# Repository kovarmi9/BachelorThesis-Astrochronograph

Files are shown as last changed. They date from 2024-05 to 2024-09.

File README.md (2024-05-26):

# BachelorThesis-Astrochronograph

This repository contains files created for a Bachelor’s Thesis on the topic of ‘Development of a device for receiving and recording coordinated time for astronomical measurement purposes’. It includes the source code of the application and the LaTeX code of the thesis.

**Srtucture of repository:**
<pre>
├── README.md                                    # Documentation
│   ├── src                                      # Source code folder
│   │   ├── Arduino                              # Arduino codes
│   │   │   ├── Components                       # Codes for individual components
│   │   │   │   ├── BLE
│   │   │   │   ├── Bluetooth
│   │   │   │   ├── DCF77_time
│   │   │   │   ├── Display
│   │   │   │   ├── GNSS_time
│   │   │   │   ├── NTP
│   │   │   │   ├── RGB_LED
│   │   │   │   ├── Rotarry_encoder
│   │   │   │   ├── RTC
│   │   │   │   ├── SD
│   │   │   │   ├── Sound
│   │   │   │   └── TS_Reader
│   │   │   ├── Complet
│   │   │   │   ├── Astro-Chronograph_R3
│   │   │   │   └── Astro-Chronograph_R4
│   │   │   └── Test                             # Arduino codes for testing time synchronization
│   │   ├── LaTeX                                # LaTeX source code of the bachelor thesis
│   │   └── R                                    # Processing of testing data
├── Eagle                                        # Circuit schematics and PCB design
└── Text - Text                                  # Text of the Thesis
    ├── Thesis.pdf -                             # Thesis document in PDF format
    └── Presentation.pdf                         # Presentation document in PDF format
</pre>
**Circuit schematics:**
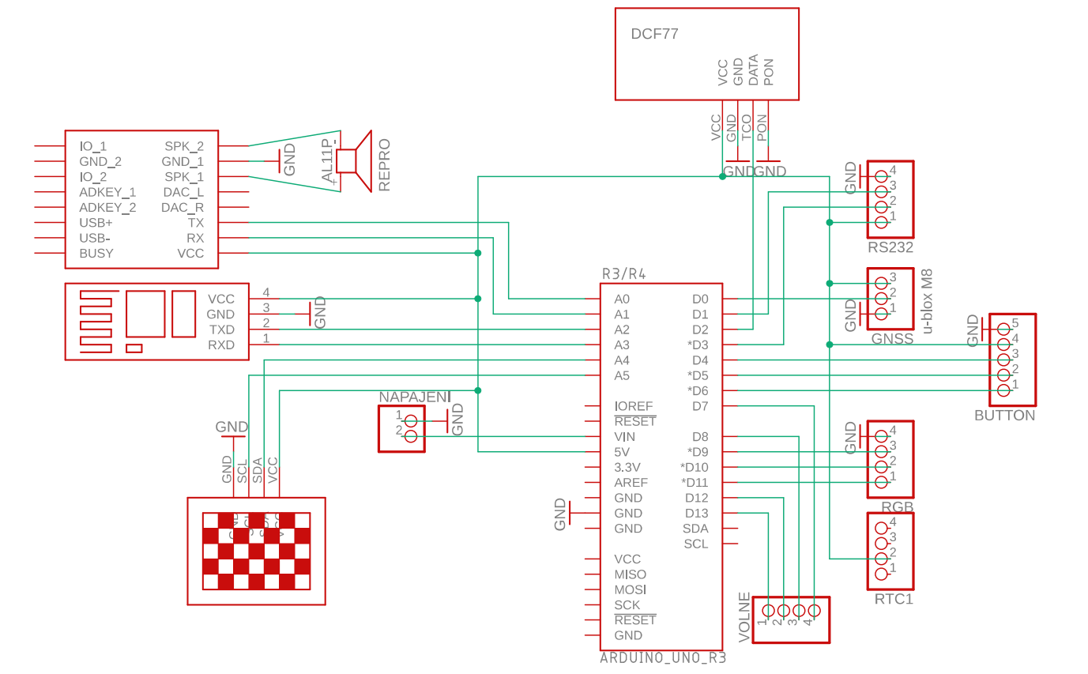
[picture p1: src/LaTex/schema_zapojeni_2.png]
Popis obrázku


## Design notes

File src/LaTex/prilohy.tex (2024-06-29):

% %%%%%%%%%%%%%%%%%%%%%%%%%%%%%%%%%%%%%%%%%%%%%%%%%%%%%%%%%%%%%%%%%%%%%%%%%%%%%%%%%%%
% %%                                    PŘÍLOHY                                    %%
% %%%%%%%%%%%%%%%%%%%%%%%%%%%%%%%%%%%%%%%%%%%%%%%%%%%%%%%%%%%%%%%%%%%%%%%%%%%%%%%%%%%

\appendix
% Příloha A: GitHub repozitář
\chapter*{A GitHub repozitář}
\addcontentsline{loa}{section}{A GitHub repozitář}
\href{https://github.com/kovarmi9/BachelorThesis-Astrochronograph}{\texttt{https://github.com/kovarmi9/BachelorThesis-Astrochronograph}}.
\begin{center}
\qrcode[height=4cm]{https://github.com/kovarmi9/BachelorThesis-Astrochronograph}
\end{center}
\textbf{Struktura repozitáře:}
\dirtree{%
.1 \href{https://github.com/kovarmi9/BachelorThesis-Astrochronograph}{BachelorThesis-Astrochronograph}.
.2 \href{https://github.com/kovarmi9/BachelorThesis-Astrochronograph/blob/main/README.md}{README.md}.\dottedline  stručná dokumentace.
.2 \href{https://github.com/kovarmi9/BachelorThesis-Astrochronograph/blob/main/src}{src}.
.3 \href{https://github.com/kovarmi9/BachelorThesis-Astrochronograph/tree/main/src/Arduino}{Arduino}.\dottedline kódy pro Arduino.
.4 \href{https://github.com/kovarmi9/BachelorThesis-Astrochronograph/tree/main/src/Arduino/Components}{Components}.\dottedline kódy pro jednotlivé komponenty.
.5 \href{https://github.com/kovarmi9/BachelorThesis-Astrochronograph/tree/main/src/Arduino/Components/BLE}{BLE}.
.5 \href{https://github.com/kovarmi9/BachelorThesis-Astrochronograph/tree/main/src/Arduino/Components/Bluetooth}{Bluetooth}.
.5 \href{https://github.com/kovarmi9/BachelorThesis-Astrochronograph/tree/main/src/Arduino/Components/DCF77_time}{DCF77\_time}.
.5 \href{https://github.com/kovarmi9/BachelorThesis-Astrochronograph/tree/main/src/Arduino/Components/Display}{Display}.
.5 \href{https://github.com/kovarmi9/BachelorThesis-Astrochronograph/tree/main/src/Arduino/Components/GNSS_time}{GNSS\_time}.
.5 \href{https://github.com/kovarmi9/BachelorThesis-Astrochronograph/tree/main/src/Arduino/Components/NTP}{NTP}.
.5 \href{https://github.com/kovarmi9/BachelorThesis-Astrochronograph/tree/main/src/Arduino/Components/RGB_LED}{RGB\_LED}.
.5 \href{https://github.com/kovarmi9/BachelorThesis-Astrochronograph/tree/main/src/Arduino/Components/Rotarry_encoder}{Rotarry\_encoder}.
.5 \href{https://github.com/kovarmi9/BachelorThesis-Astrochronograph/tree/main/src/Arduino/Components/RTC}{RTC}.
.5 \href{https://github.com/kovarmi9/BachelorThesis-Astrochronograph/tree/main/src/Arduino/Components/SD}{SD}.
.5 \href{https://github.com/kovarmi9/BachelorThesis-Astrochronograph/tree/main/src/Arduino/Components/Sound}{Sound}.
.5 \href{https://github.com/kovarmi9/BachelorThesis-Astrochronograph/tree/main/src/Arduino/Components/TS_Reader}{TS\_Reader}.
.4 \href{https://github.com/kovarmi9/BachelorThesis-Astrochronograph/tree/main/src/Arduino/Complet}{Complet}.\dottedline kompletní kód.
.5 \href{https://github.com/kovarmi9/BachelorThesis-Astrochronograph/tree/main/src/Arduino/Complet/Astro-Chronograph_R3}{Astrochronograph\_R3}.
.5 \href{https://github.com/kovarmi9/BachelorThesis-Astrochronograph/tree/main/src/Arduino/Complet/Astro-Chronograph_R4}{Astrochronograph\_R4}.
.4 \href{https://github.com/kovarmi9/BachelorThesis-Astrochronograph/tree/main/src/Arduino/Test}{Test}.\dottedline kód pro testování.
.3 \href{https://github.com/kovarmi9/BachelorThesis-Astrochronograph/tree/main/src/LaTeX}{LaTeX}.\dottedline zdrojový kód práce ve formátu \LaTeX.
.3 \href{https://github.com/kovarmi9/BachelorThesis-Astrochronograph/tree/main/src/R}{R}.\dottedline zpracování testovacích dat.
.2 \href{https://github.com/kovarmi9/BachelorThesis-Astrochronograph/tree/main/Eagle}{Eagle}.\dottedline schéma zapojení a návrh DPS.
.2 \href{https://github.com/kovarmi9/BachelorThesis-Astrochronograph/tree/main/Text}{Text}.
.3 \href{https://github.com/kovarmi9/BachelorThesis-Astrochronograph/blob/main/Text/Thesis.pdf}{Thesis.pdf}.\dottedline text práce ve formátu PDF.
.3 \href{https://github.com/kovarmi9/BachelorThesis-Astrochronograph/blob/main/Text/Presentation.pdf}{Presentation.pdf}.\dottedline Prezentace ve formátu PDF.
}

% Příloha B: Elektronická příloha - SD karta
\newpage
\chapter*{B Elektronická příloha - SD karta}
\addcontentsline{loa}{section}{B Elektronická příloha - SD karta}
\textbf{Struktura souborů na SD kartě:}
\dirtree{%
.1 SD.
.2 Arduino.\dottedline kódy pro Arduino.
.3 Components.\dottedline kódy pro jednotlivé komponenty.
.4 BLE.
.4 Bluetooth.
.4 DCF77\_time.
.4 Display.
.4 GNSS\_time.
.4 NTP.
.4 RGB\_LED.
.4 Rotarry\_encoder.
.4 RTC.
.4 SD.
.4 Sound.
.4 TS\_Reader.
.3 Complet.\dottedline kompletní kód.
.4 Astrochronograph\_R3.
.4 Astrochronograph\_R4.
.3 Test.
.2 R.\dottedline zpracování testovacích dat.
.2 Eagle.\dottedline schéma zapojení a návrh DPS.
}

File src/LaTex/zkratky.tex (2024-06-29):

\begin{seznamzkratek}{GNSS}
\novazkratka{API}{API}{Application Programming Interface}
\novazkratka{DPS}{DPS}{deska plošných spojů}
\novazkratka{GNSS}{GNSS}{globální navigační satelitní systémy}
\novazkratka{IDE}{IDE}{integrované vývojové prostředí} \(\) - z angl. Integrated Development Environment
\novazkratka{LED}{LED}{elektroluminiscenční dioda} \(\) - z angl. Light Emitting Diode
\novazkratka{NTP}{NTP}{Network Time Protokol}

\novazkratka{PWM}{PWM}{pulzně šířková modulace} \(\) - z angl. Pulse Width Modulation

\novazkratka{TAI}{TAI}{mezinárodní atomový čas} \(\) - z fr. Temps Atomique International
\novazkratka{UTC}{UTC}{univerzální koordinovaný čas}\(\) - z angl. Coordinated Universal Time / fr. Temps Universel Coordonné

%SI sistem international

%\novazkratka{VLBI}{VLBI}{interferometrie z velmi dlouhých základen} \(\) - z angl. Very-long-baseline interferometry
%\novazkratka{SEČ}{SEČ}{středoevropský čas}
%\novazkratka{SELČ}{SELČ}{středoevropský letní čas}
%\novazkratka{UART}{UART}{Universal asynchronous receiver-transmitter}

\end{seznamzkratek}

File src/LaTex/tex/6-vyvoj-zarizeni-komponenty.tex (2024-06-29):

\chapter{Vývoj zařízení - Komponenty}
\label{4-vyvoj-zarizeni-komponenty}
\section{Vývojová deska}
Vývojová deska je elektronické zařízení skládající se z~desky plošných spojů, mikro\-kontroléru a k~němu připojených dalších periférií. Mikrokontrolér je malý \text{počítač} na jednom integrovaném obvodu, který může obsahovat jedno nebo více jader \text{procesoru}, paměť pro uložení programu, operační paměť a programovatelné \text{vstupy/výstupy}. Mikrokontrolér neobsahuje operační systém a řídící program na něj bývá nahraný \text{pomocí} integrovaného vývojového prostředí (\zk{IDE}, z~anglického Integrated Develop\-ment Environment). Mikrokontrolér ovládá k~němu připojené periférie a další součástky připojnené k~vývojové desce. Připojením součástek k~vývojové desce lze vytvořit nové elektronické zařízení \cite{dps_vyvojove_desky}.

\subsection{Arduino Uno}
Jako vývojová deska bylo zvoleno Arduino UNO, a to z~důvodu jeho poměrně nízké ceny, velkého množství dostupné dokumentace a kompatibilních součástek. Tato vývojová deska, na které je nahraný řídící program, ovládá všechny ostatní použité komponenty. Nejběžněji se lze setkat s~Arduinem UNO R3, které je \text{založené} na mikrokontroléru ATmega328P od firmy Atmel. Z~důvodu malé kapacity paměti \text{Arduina} UNO R3 bylo využito novější Arduino UNO R4. To je založeno na mikrokontroléru Renesas RA4M1, jenž obsahuje procesor ARM Cortex-M4F. Arduino UNO R4 se vyrábí ve verzích Minima a WiFi. Verze WiFi je zaměřena na IoT aplikace a obsahuje navíc mikrokontrolér ESP32-S3 od firmy Espressif s~integrovaným WiFi a bluetooth low energy (BLE) modulem. Toho lze využít pro připojení k~NTP serveru, nebo odesílání dat \cite{arduino}. Arduino UNO lze pořídit i v~podobě „klonu“, který vyrábí neoficiální výrobce. Tyto „kolny“ bývají obvykle cenově dostupnější než \text{originální desky}.

% https://www.robotikabrno.cz/docs/arduino/Pr%C5%AFvodce-sv%C4%9Btem-Arduina-CZ.pdf

\begin{table}[H]
    \centering
    \caption{Porovnání kapacity paměti Arduina UNO R3 a R4 \cite{arduino}}
    \begin{tabular}{|c|c|c|}
    \hline
    \textbf{Typ paměti} & \textbf{R3} & \textbf{R4}\\
    \hline\hline
    flash  & 32 KB & 256 kB \\ \hline
    SRAM   & 2  KB &  32 kB \\ \hline
    EEPROM & 1  KB &   8 kB \\ \hline
    \end{tabular}\\
\end{table}

\begin{figure}[H]
	\centering
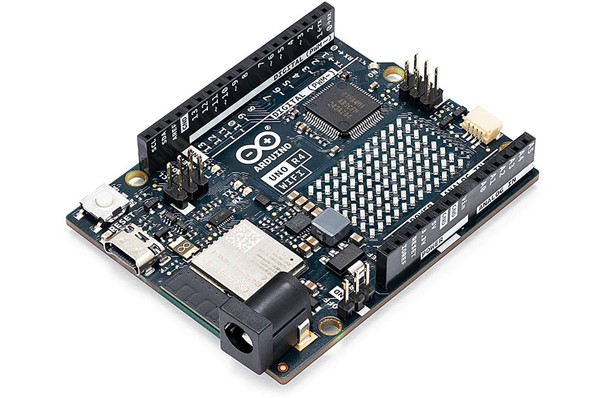
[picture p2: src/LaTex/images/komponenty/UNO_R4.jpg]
	
	\caption{Arduino UNO R4 ve verzi WiFi \cite{laskakit_web}}
\end{figure}

\subsection{Arduino Mega}
Vzhledem k~nedostatečné kapacitě paměti Arduina UNO R3 se rovněž nabízí možnost využití Arduina Mega. To je založené na mikrokontroléru ATmega2560. Oproti \text{Arduinu} UNO R3 disponuje větší kapacitou paměti, a oproti oběma verzím Arduina UNO i větším množstvím pinů. Nevýhodou Arduina Mega je větší fyzická velikost a bylo tedy využito jen pro testování během vývoje zařízení \cite{arduino}.

\begin{figure}[H]
	\centering
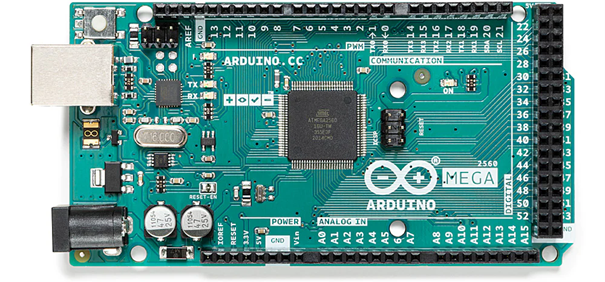
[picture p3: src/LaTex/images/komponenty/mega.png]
	
	\caption{Arduino Mega \cite{arduino}}
\end{figure}

\section{Přijímač časového signálu}
Existuje několik způsobů, jak synchronizovat čas Arduina s~koordinovaným časem. Jedním z~nich je synchronizace času při nahrávání programu do Arduina. Tato metoda však vyžaduje opakované nahrání programu před každým měřením, aby se interní čas aktualizoval. Tato metoda neumožňuje průběžnou synchronizaci a její přesnost je závislá na přesnosti vnitřního času zařízení z~nějž je program nahráván. Vhodnějšími metodami jsou synchronizace přes internet, využití přijímače DCF77, který přijímá koordinovaný čas pomocí rádiového signálu, nebo využití času z~NMEA zprávy z~GNSS přijímače. Tyto metody poskytují přesnější a průběžnou synchronizaci času bez nutnosti opakovaného nahrávání programu.

\subsection{Přijímač DCF77}
Pro příjem signálu DCF77 je vhodné zvolit anténu, která přijímá především magnetickou složku elektromagnetické vlny, protože elektrická složka vlny je citlivá na výšku antény nad povrchem a bývá výrazně více rušena okolním signálem z~jiných \text{elektronických} zařízení než magnetická složka. Pro příjem magnetické složky signálu lze využít rámovou anténu, která ale mívá poměrně velké rozměry. Obvykle se používá anténa o~průměru 0,5m. Z~důvodu kompaktnosti celého zařízení byla \text{zvolena} feritová anténa. Pokud by signál z~feritové antény nebyl dostatečně silný, je možné pro jeho zesílení přímo na feritovou anténu připojit rámovou anténu s~větším průměrem.

Využitý přijímač se skládá z~feritového jádra, kolem kterého je vinuta cívka a demodulátoru, který slouží k~oddělení modulačního signálu od nosného signálu. Anténa má dvě maxima a dvě minima. Pro příjem maximální intenzity signálu, je vhodné ji umístit kolmo na směr k~vysílači. Pokud by docházelo k~rušení signálu z~jednoho směru, lze to vyřešit tím, že bude anténa natočena minimem ke zdroji rušení \cite{fel_dcf77} \cite{vyvoj_hw_andel}.

\begin{figure}[H]
	\centering
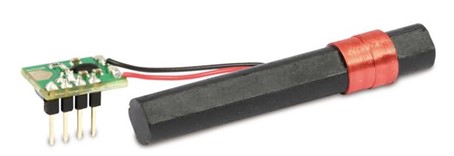
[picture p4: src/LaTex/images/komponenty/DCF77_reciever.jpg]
	
	\caption{Přijímač radiového signálu DCF77 \cite{dratek_web}}
\end{figure}

\subsection{Přijímač GNSS}
Pro příjem informací o~aktuálním čase lze využít i GNSS přijímač. \text{Astrochrograf} je navržený tak, že má vyvedený pin D0 Arduina, aby k~němu mohl být \text{připojen} \text{libovolný} GNSS přijímač. Pin D0 na Arduinu Uno funguje jako RX pin pro \text{sériovou} komunikaci pomocí UART. GNSS přijímač musí být k~RX pinu Arduina \text{připojen} pomocí svého TX pinu. Přijímač musí poskytovat NMEA zprávu \$GNZDA, která obsahuje informace o~aktuálním čase a zprávu \$GNGGA, která poskytuje informaci o~poloze přijímače. Pro vývoj zařízení byl použit aktuálně dostupný GNSS \text{přijímač} Ublox NEO-M8T, který je schopen přijímat data ze satelitů GPS, GLONASS, Galileo, BeiDou, QZSS a SBAS. Tento přijímač umožňuje i RTK měření. Nevýhodou přijímače je poměrně vysoká cena. Pro určování času lze využít i přijímače s~omeze\-nější funkcionalitou než Ublox NEO-M8T. Například levnější přijímač Ublox NEO-M7M, který přijímá data ze satelitů GPS, GLONASS, Galileo a QZSS. Tento přijímač neumožňuje měření RTK, což není pro určování času potřeba.
\begin{figure}[H]
\centering
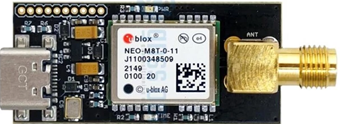
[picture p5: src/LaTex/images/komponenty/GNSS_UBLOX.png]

\caption{GNSS přijímač Ublox NEO-M8T \cite{gnss_store}}
\end{figure}

\begin{figure}[H]
	\centering
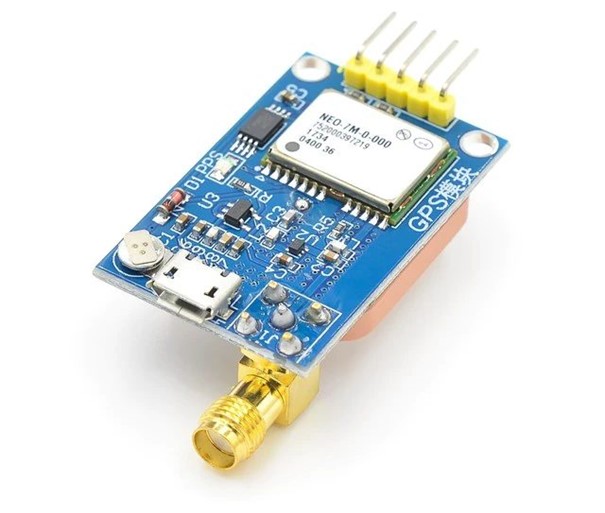
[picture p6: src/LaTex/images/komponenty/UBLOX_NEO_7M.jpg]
	
	\caption{GNSS přijímač Ublox NEO 7M \cite{dratek_web}}
\end{figure}

\section{Čtečka Micro SD karet}
Protože Arduino samo o sobě nemá paměť pro ukládání dat, tak byla pro ukládání měřených dat využita Micro SD karta. Čtečka Micro SD karet umožňuje zapisovat měřená data na Micro SD kartu a popřípadě je z~ní i číst. Pro komunikaci s~čtečkou Micro SD karet je využíváno standardní SPI rozhraní \cite{arduino_navody}.

\begin{figure}[H]
	\centering
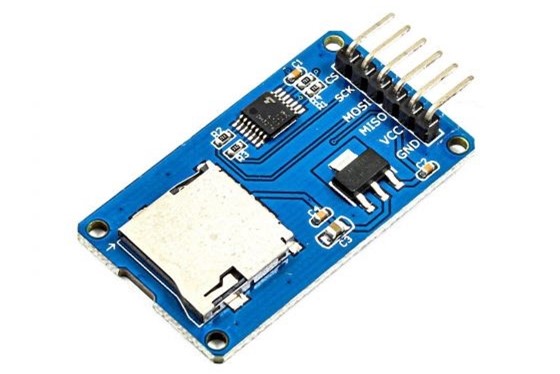
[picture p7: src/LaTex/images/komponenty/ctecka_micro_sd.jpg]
	
	\caption{Čtečka Micro SD karet \cite{dratek_web}}
\end{figure}

\section{Tlačítko}
Tlačítko je jednoduchý komponent, sloužící pro detekci svého stisknutí. Stisknutí tlačítka slouží k~provedení záznamu času na Micro SD kartu. Místo samostatného tlačítka byl využit modul rotačního enkodéru, který umí detekovat své stisknutí a při pootočení osou poskytuje informaci o~směru rotace. Výhodou rotačního enkodéru oproti tlačítku je, že poskytuje další informace, které lze využít k~ovládání zařízení. Výhodou tohoto konkrétního modulu je to, že jej lze snadno upevnit ke krabičce s~výsledným zařízením.
\begin{figure}[H]
	\centering
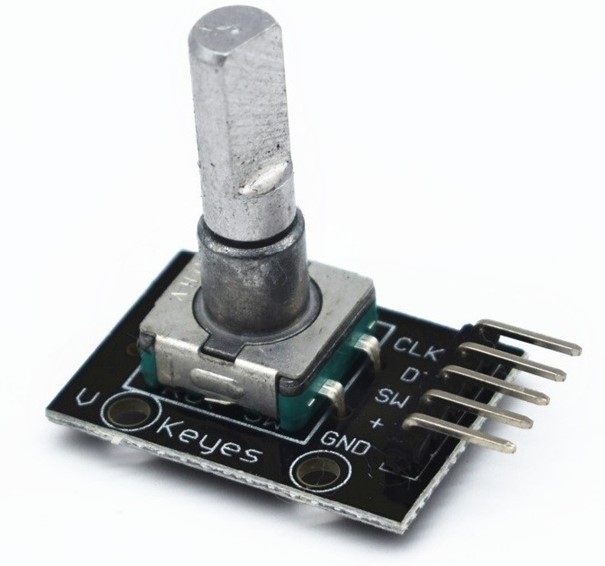
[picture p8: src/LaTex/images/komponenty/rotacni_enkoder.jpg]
	
	\caption{Rotační enkodér \cite{dratek_web}}
\end{figure}

\section{OLED displej}
K~informování měřiče o~průběhu měření slouží mimo jiné displej. Na něj se zobrazuje informace o~stavu vložení Micro SD karty, o~stavu synchronizace času, aktuální čas a poslední uložený čas. Jako displej byl zvolen OLED displej především kvůli nízké ceně, dobré čitelnosti, nízké spotřebě energie a absenci potřeby dodatečného podsvícení, jelikož světélkují samotné pixely. Displej je monochromatický a jeho rozlišení je 128×64 bodů. K~řízení displeje je využívána komunikace pomocí I\(^2\)C sběrnice \cite{arduino_navody}.

\begin{figure}[H]
	\centering
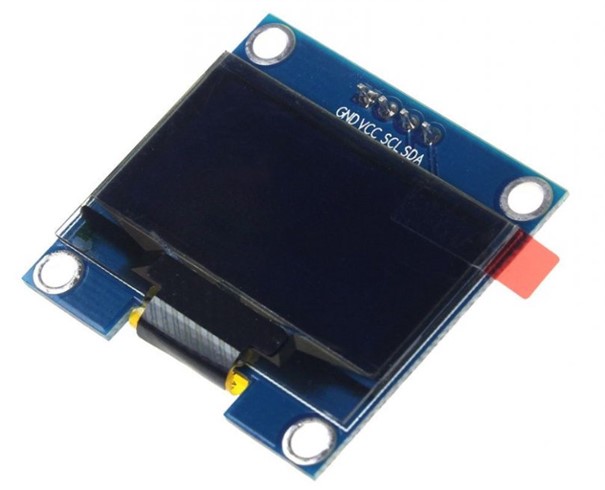
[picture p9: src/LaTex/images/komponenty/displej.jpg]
	
	\caption{OLED displej \cite{dratek_web}}
\end{figure}

\section{Hlasový modul}
O~průběhu měření je měřič informován kromě displeje i pomocí reproduktoru, tak aby nemusel při měření sledovat displej. Měřiče o~průběhu měření informují slovní pokyny „Čas byl synchronizován“ a „Měření času bylo uloženo“, které byly vytvořeny pomocí převodu textu na mp3 soubor. Jelikož Arduino neumožňuje ukládat žádné soubory do své vnitřní paměti, tak jsou mp3 soubory se zvukovými informacemi nahrány na Micro SD kartu. Soubory jsou z~Micro SD karty čteny pomocí hlasového modulu a přehrávány pomocí reproduktoru, který je k~hlasovému modulu připojen. Hlasový modul s~Arduinem komunikuje prostřednictvím sériové komunikace \cite{arduino_navody}.

\begin{figure}[H]
	\centering
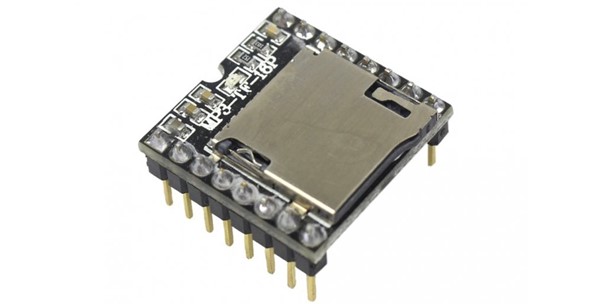
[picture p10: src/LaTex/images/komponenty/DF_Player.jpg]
	
	\caption{Hlasový modul \cite{laskakit_web}}
\end{figure}

\begin{figure}[H]
	\centering
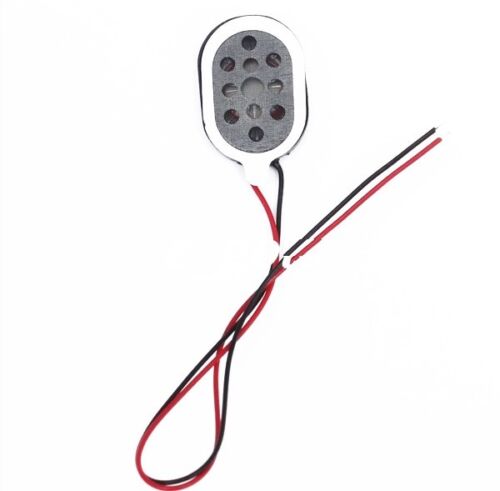
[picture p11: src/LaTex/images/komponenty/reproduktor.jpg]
	
	\caption{Reproduktor \cite{arduino}}
\end{figure}

\section{RGB LED}
Kromě displeje a zvukového signálu je měřič informován o~průběhu měření také prostřednictvím elektroluminiscenční diody (\zk{LED}, z~anglického Light Emitting Diode). Jako \zkratka{LED} je využit modul RGB \zk{LED}, který se skládá ze tří samostatných \zk{LED} (červená, zelená, modrá). Tyto \zk{LED} mají společnou \text{katodu}, ale samostatné anody. K ovládání jasu jednotlivých barev slouží \zkratka{PWM}. Jednotlivé anody lze nezávisle na sobě připojit na piny s podporou \zk{PWM}, což umožňuje ovládat samostatně jednotlivé barvy. Další výhodou tohoto modulu je, že již má integrované ochranné rezistory. Během měření může \zk{LED} signalizovat různé stavy: Nejprve bliká červeně v~každý okamžik, kdy přijme signál DCF77 (v~ideálním případě je to jednou za sekundu). Ve chvíli, kdy je čas poprvé synchronizován se změní červené blikání na zelené, což informuje měřiče o~úspěšné synchronizaci času. Dále \zk{LED} bliká modře v~každý okamžik, kdy měřič provede měření \cite{arduino_navody}.
\begin{figure}[H]
	\centering
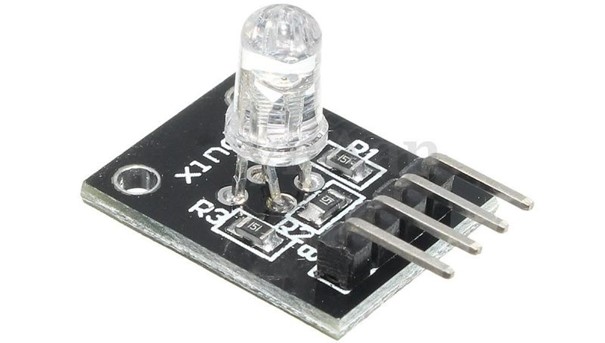
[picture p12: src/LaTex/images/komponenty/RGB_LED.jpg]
	
	\caption{Modul s~RGB LED \cite{dratek_web}}
\end{figure}

\section{Převodník TTL na RS232}
Aby byl spolu s~časovými údaji uložen na Micro SD kartu vodorovný směr (a případně i zenitový úhel) měřený totální stanicí, je potřeba zajistit komunikaci Arduina s~totální stanicí. K~tomu lze využít sériovou komunikaci pomocí UART. Konkrétně byla využita totální stanice Leica TC1700. Ta využívá pro sériovou komunikaci standart RS-232 a lze k~ní tedy připojit sériový kabel RS-232 \cite{tps-dna}. Standart RS-232 využívá pro datové signály +3~V až +25~V jako logickou nulu a -3~V až -25~V jako logickou jedničku. Arduino UNO využívá protokol TTL, který považuje hodnoty okolo 0~V za logickou nulu a hodnoty v~okolí +5~V za logickou jedničku. Aby mohl být kabel RS-232 připojen i k~Arduinu, je potřeba využít převodník TTL na RS-232 \cite{sparkfun-tutorial}.

\begin{figure}[H]
	\centering
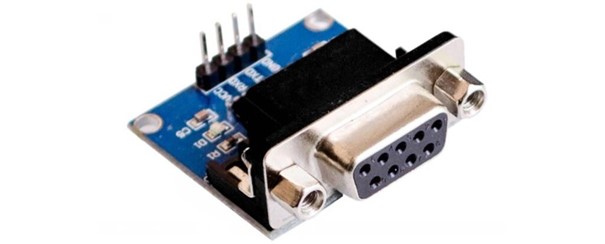
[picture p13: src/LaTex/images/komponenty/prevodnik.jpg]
	
	\caption{Převodník TTL na RS232 \cite{laskakit_web}}
\end{figure}

\section{Bluetooth modul}
Pro export dat z~Micro SD karty, aniž by bylo potřeba ji vyjmout, lze využít \text{Bluetooth} modul. Konkrétně byl pro tento účel využit modul HC-05. Tento modul využívá sériovou komunikaci pomocí UART a podporuje Bluetooth ve verzi 2.0. Pomocí Bluetooth modulu lze přenášet binární data. Modul je připojen pomocí pinů GND, VCC, RX a TX. Kromě toho obsahuje piny STATE a EN, které slouží pro konfiguraci modulu. Pin EN na modulu HC-05 umožňuje přepnutí modulu do režimu „enabled“. V~tomto režimu lze pomocí AT příkazů nastavit jméno, heslo, popřípadě i baud rate a další parametry modulu \cite{arduino_navody}.

\begin{figure}[H]
	\centering
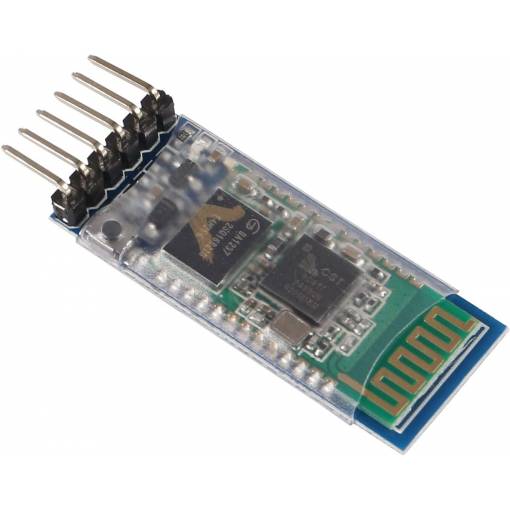
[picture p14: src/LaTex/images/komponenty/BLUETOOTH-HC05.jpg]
	
	\caption{Bluetooth modul HC-05 \cite{dratek_web}}
\end{figure}

\section{Deska plošných spojů}
Během vývoje zařízení byly všechny komponenty spojovány pomocí kabelů. Nevýho\-dou propojení pomocí kabelů je velká prostorová náročnost a celková nepřehlednost. Z~toho důvodu bývá obvykle propojení různých komponentů realizováno pomocí desky plošných spojů. Pro snadné propojení všech využitých komponentů byla tedy vyhotovena \zkratka{DPS}.

\begin{figure}[H]
	\centering
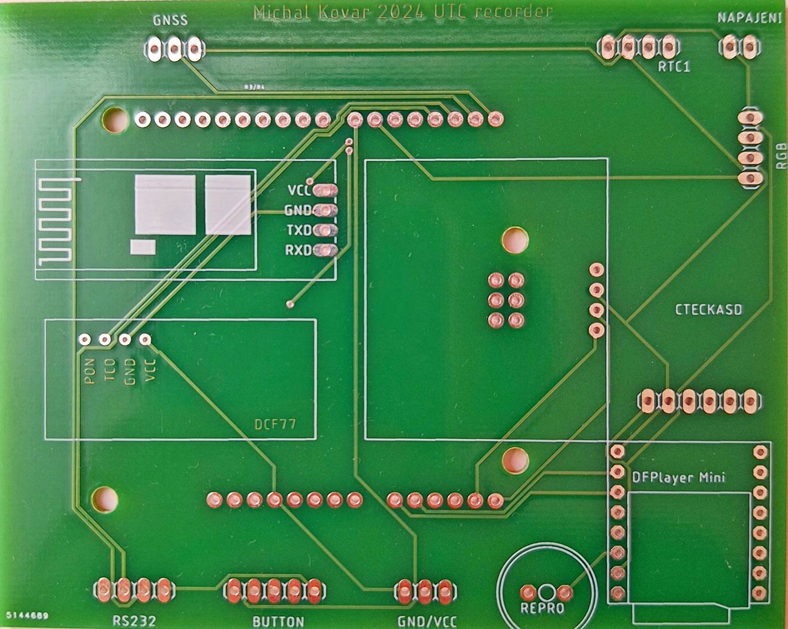
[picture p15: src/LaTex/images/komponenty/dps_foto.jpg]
	
	\caption{Výsledná DPS}
\end{figure}

\section{Cena komponentů}
Ceny jednotlivých komponentů se mění v čase a mohou se lišit v závislosti na místě (obchodě), kde byly zakoupeny. Cena výsledného zařízení závisí na tom, zda byly použity všechny komponenty pro plnou funkcionalitu, nebo zda byly některé funkce vynechány.  Pokud se zařízení vyrábí s omezenou funkcionalitou, lze využít levnější Arduino UNO R3. Náklady na výsledné zařízení lze také snížit použitím „klonů“ místo originálního Arduina. Níže uvedená tabulka obsahuje komponenty potřebné pro zařízení s plnou funkcionalitou a uvádí ceny, za které byly tyto komponenty zakoupeny.

\begin{table}[H]
    \centering
    \caption{Cena použitých součástek}
    \begin{tabular}{|c|c|c|}
    \hline
    \textbf{Název} & \textbf{Cena} & \textbf{Odkaz na obchod}\\
    \hline\hline
    Arduino UNO R4 WiFi         & 768 Kč            & \href{https://www.laskakit.cz/arduino-uno-r4-wifi--original/}{laskakit.cz}  \\ \hline
    Přijímač DCF77              & 5,60 \euro/140 Kč  & \href{https://www.pollin.de/p/dcf-empfangsmodul-dcf1-810054}{pollin.de} \\ \hline
    Přijímač GNSS               & 339 Kč            & \href{https://dratek.cz/arduino/1733-gps-satelitni-urceni-polohy-neo-7m-modul.html?}{dratek.cz} \\ \hline
    Čtečka Micro SD karet       & 24 Kč             & \href{https://dratek.cz/arduino/993-ctecka-microsd-karet.html?}{dratek.cz} \\ \hline
    Tlačítko (rotační enkodér)   & 38 Kč             & \href{https://dratek.cz/arduino/837-rotacni-enkoder.html?}{dratek.cz} \\ \hline
    OLED displej                & 167 Kč            & \href{https://dratek.cz/arduino/3181-iic-i2c-oled-1-3-displej-128x64-bily.html?}{dratek.cz} \\ \hline
    Hlasový modul               & 66 Kč             & \href{https://dratek.cz/arduino/4857-hlasovy-modul-s-integrovanym-mp3-prehravacem-dfplayer.html?}{dratek.cz} \\ \hline
    Reproduktor                 & 19 Kč             & \href{https://dratek.cz/arduino/1175-reproduktor-1w-8ohm.html?}{dratek.cz} \\ \hline
    RGB LED                     & 15 Kč             & \href{https://dratek.cz/arduino/837-rotacni-enkoder.html}{dratek.cz} \\ \hline
    Bluetooth modul HC-05       & 117 Kč            & \href{https://dratek.cz/arduino/1005-bluetooth-modul-hc-05.html?}{dratek.cz} \\ \hline
    Deska plošných spojů        & 9,34 \$/216 Kč    & \href{https://www.allpcb.com/}{allpcb.com} \\ \hline
     \textbf{Celkem}            & 1909 Kč           & - \\ \hline
    \end{tabular}\\
\end{table}

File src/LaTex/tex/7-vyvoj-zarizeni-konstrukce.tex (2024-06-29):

\chapter{Vývoj zařízení - Konstrukce}
\label{5-vyvoj-zarizeni-konstrukce}
V~této kapitole bude vysvětleno zapojení jednotlivých komponentů, které byly pop\-sány v~předchozí kapitole. Dále bude popsán návrh desky plošných spojů (\zk{DPS}), jenž byl vyhotoven v~softwaru Autodesk EAGLE. Bude vysvětleno, jak byla \zk{DPS} osazena jednotlivými komponenty. Nakonec bude popsáno, jak byl vytvořen prototyp výsledného zařízení.

\section{Schéma zapojení}
Arduino Uno disponuje různými typy pinů, které lze využít k~různým účelům. Při zapojování jednotlivých komponentů je důležité zohlednit specifickou funkcionalitu jednotlivých pinů. Nelze totiž připojit součástky na libovolné piny, ale je nutné je zapojit na piny, které disponují potřebnou funkcionalitou. Jeden pin může mít více funkcí najednou. Piny Arduina mohou sloužit například jako digitální vstupy/výstupy, analogové vstupy, \zk{PWM} (analogové výstupy s~modulací šířky pulzu), RX a TX pro sériovou komunikaci, SDA a SCL pro I\(^2\)C komunikaci nebo jako MISO, MOSI, CLK, a CS pro SPI komunikaci \cite{arduino}.

\begin{figure}[H]
	\centering
	
	\caption{Výstupy pinů pro Arduino UNO R4 \cite{arduino}}
\end{figure}

Schéma zapojení bylo vyhotoveno v~softwaru Autodesk Eagle. nejprve bylo \text{vyhotoveno} schéma zapojení pro Arduino UNO R3 podle toho, jak byly jednotlivé komponenty zapojeny v~rámci testování jejich funkčnosti. Toto schéma zapojení sloužilo jako podklad pro tvorbu desky plošných spojů (\zk{DPS}). Arduino UNO R3 však nedisponuje dostatečnou kapacitou paměti k~tomu, aby mohlo \text{obsluhovat} všechny plánované komponenty. Pro finální zařízení, které bude disponovat plnou funkcionalitou, bylo proto zvoleno Arduino UNO R4. Vzhledem k~tomu, že Arduino UNO R4 má lehce odlišné rozvržení pinů oproti verzi R3, bylo nutné vyhotovit nové schéma zapojení a podle něj i novou \zk{DPS}. Nové schéma zapojení se povedlo navrhnout tak, že nová \zk{DPS} je kompatibilní s~oběma verzemi Arduina UNO (R3 i R4).

\begin{figure}[H]
	\centering
	
	\caption{Schéma zapojení komponentů pro Arduino Uno}
\end{figure}

\subsubsection*{Přijímač časového signálu DCF77}
Přijímač poskytuje digitální signál, který odpovídá dekódovaným bitům časového kódu.
Tento digitální signál je pak k~dispozici na výstupním pinu přijímače (obvykle označeném jako TCO nebo DATA), který je potřeba připojit k~digitálnímu vstupu Arduina.
\begin{itemize}
    \tiny
    \setlength{\itemsep}{0pt} 
    \item VCC $\rightarrow$ 3.3V
    \item GND $\rightarrow$ GND
    \item PON $\rightarrow$ GND
    \item TCO $\rightarrow$ D2
\end{itemize}

\subsubsection*{GNSS přijímač u-blox NEO}
Komunikace s~Arduinem probíhá pomocí sériové komunikace TTL přes rozhraní UART. Je nutné připojit přijímač k~pinům Arduina, které tuto komunikaci umožňují.
 \begin{itemize}
     \tiny
     \setlength{\itemsep}{0pt} 
     \item VCC $\rightarrow$ 5V 
     \item GND $\rightarrow$ GND
     \item TX  $\rightarrow$ D0
 \end{itemize}

\subsubsection*{Tlačítko (rotační enkodér)}
Rotační enkodér poskytuje digitální signály, které odpovídají jeho otáčení a stisknutí tlačítka. Tyto signály lze číst pomocí digitálních pinů Arduina, které mohou sloužit jako digitální vstupy.
\begin{itemize}    
    \tiny
    \setlength{\itemsep}{0pt} 
    \item VCC $\rightarrow$ GND
    \item GND $\rightarrow$ 5V
    \item CLK $\rightarrow$ D6
    \item DT  $\rightarrow$ D5
    \item SW  $\rightarrow$ D4
\end{itemize}

\subsubsection*{OLED displej}
OLED displej využívá i\(^2\)C komunikaci a je tedy potřeba jej připojit k~pinům, které ji podporují.
\begin{itemize}
    \tiny
    \setlength{\itemsep}{0pt} 
    \item VCC $\rightarrow$ 5V 
    \item GND $\rightarrow$ GND
    \item SDA $\rightarrow$ A4
    \item SCL $\rightarrow$ A5 
\end{itemize}

\subsubsection*{Hlasový modul}
Hlasový modul využívá sériovou komunikaci. Kvůli nedostatku sériových pinů na Arduinu UNO je použita knihovna SoftwareSerial, která umožňuje emulovat \text{sériovou} komunikaci pomocí některých pinů, které nejsou primárně určeny pro sériovou komu\-nikaci.
\begin{itemize}
    \tiny
    \setlength{\itemsep}{0pt} 
    \item VCC $\rightarrow$ 5V 
    \item GND $\rightarrow$ GND
    \item TX  $\rightarrow$ RX 
    \item RX  $\rightarrow$ TX
    \item SPK1 $\rightarrow$ reproduktor (+)
    \item SPK2 $\rightarrow$ reproduktor (-)
\end{itemize}

\subsubsection*{RGB LED}
Pro ovládání jasu světla jednotlivých barev, lze využít piny s~podporou pulzně šířkové modulace (\zk{PWM}), označené symboly „\(\sim \)“.
\begin{itemize}
    \tiny
    \setlength{\itemsep}{0pt} 
    \item R $\rightarrow$ \(\sim \)D9
    \item G $\rightarrow$ \(\sim \)D10
    \item B $\rightarrow$ \(\sim \)D11
    \item GND $\rightarrow$ GND
\end{itemize}

\subsubsection*{Bluetooth modul HC-05}
Bluetooth modul HC-05 využívá sériovou komunikaci, ale Arduino UNO nemá dosta\-tečný počet sériových pinů. Proto jsou využity piny, které umožňují softwarovou emulaci sériové komunikace obdobně jako u~hlasového modulu.
\begin{itemize}
    \tiny
    \setlength{\itemsep}{0pt} 
    \item VCC $\rightarrow$ 5V 
    \item GND $\rightarrow$ GND
    \item TX  $\rightarrow$ RX 
    \item RX  $\rightarrow$ TX 
\end{itemize}

\section{Návrh DPS}
Návrh \zk{DPS} byl vyhotoven v~softwaru Autodesk Eagle. Propojení mezi komponenty vycházeli z~již vytvořeného schématu zapojení. Bylo navrženo rozmístění komponentů na \zk{DPS}. Pomocí funkce „Autorouter“ byly automaticky vygenerovány optimální trasy spojů. Dále byl vyhotoven „gerberfile“. Ten slouží jako podklad pro výrobu. Výroba \zk{DPS} může být provedena amatérsky. K~tomu je potřeba speciální vybavení a určitá zručnost zhotovitele. Vzhledem k~náročnosti výroby kvalitní \zk{DPS} byla zvolena možnost nechat ji vyrobit profesionální firmou, na základě předloženého „gerberfile“. Tím je zajištěno, že je \zk{DPS} kvalitní a spolehlivá.

\begin{figure}[H]
	\centering
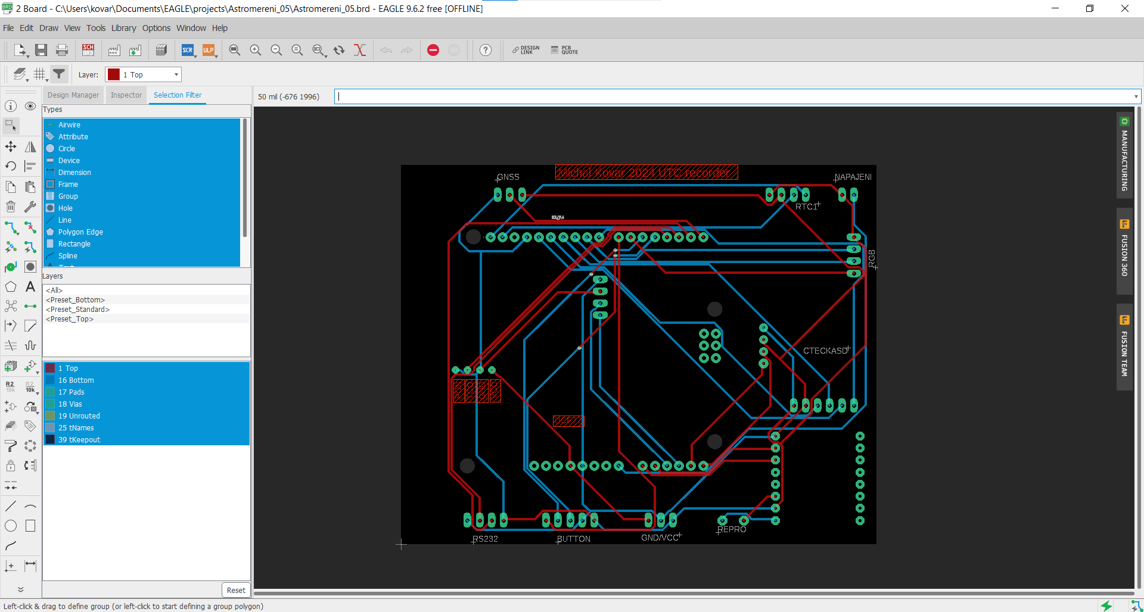
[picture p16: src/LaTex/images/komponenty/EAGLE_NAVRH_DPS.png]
	
	\caption{Ukázka návrh DPS v~softwaru Autodesk Eagle}
\end{figure}

\section{Sestavení výsledného zařízení}
Deska plošných spojů byla navržena tak, aby společně s~komponenty k~ní připojenými bylo výsledné zařízení co nejkompaktnější. K~desce byly připájeny další komponenty anebo patice a hřebínky, do kterých budou komponenty zapojeny, aby bylo možné některé komponenty v~případě potřeby odpojit nebo vyměnit. Některé součástky, jako tlačítka a displej byly připojeny k~desce pomocí kabelů. To umožňuje snadné umístění těchto součástek na vnější část krabičky. Kabely lze snadno odpojit pro případ, že by bylo zařízení potřeba rozebrat například z~důvodu výměny nějakého komponentu. Napájení zařízení je řešeno pomocí 9~V~baterie, která je propojená s~piny VIN a GND Arduina.

\begin{figure}[H]
	\centering
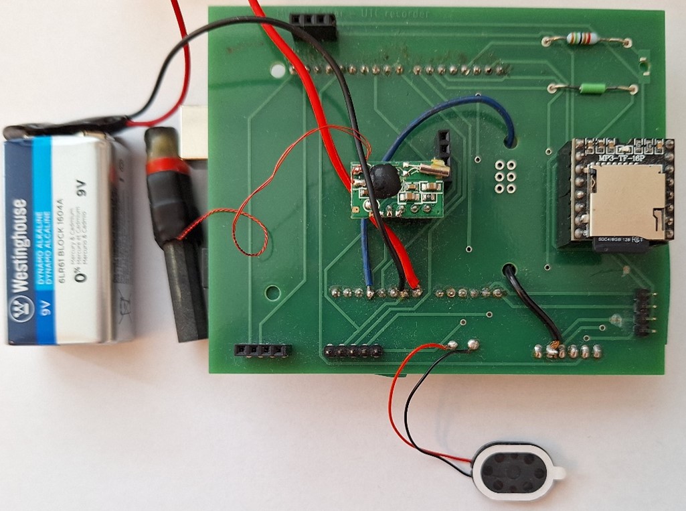
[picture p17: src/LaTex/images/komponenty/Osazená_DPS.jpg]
	
	\caption{Ukázka osazené DPS pro prototyp zařízení}
\end{figure}

Nakonec byly všechny komponenty integrovány do krabičky, která slouží jako tělo zařízení (astrochronografu). Tělo prototypu zařízení založeného na Arduinu UNO R3 bylo provizorně vytvořeno ze svačinové krabičky, která svými rozměry poměrně dobře vyhovuje potřebám zařízení. Svačinová krabička byla jako tělo zařízení využita z~důvodu toho, že je snadno dostupná a není potřeba ji speciálně vyrábět, zároveň je její výhodou vodotěsnost a průhlednost. V~budoucnu je v~plánu vytvořit vlastní tělo zařízení, které bude kompaktnější a bude přesně vyhovovat účelům zařízení. Do krabičky byly vyvrtány a vyřezány díry pro displej, konektory a tlačítka, které jsou utěsněny silikonem, aby byla zachována vodotěsnost celého zařízení.

\begin{figure}[H]
	\centering
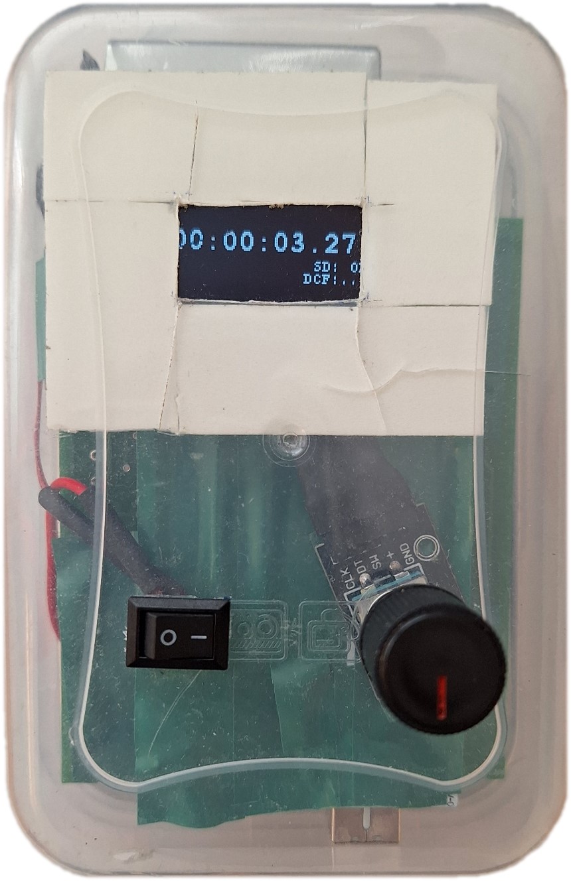
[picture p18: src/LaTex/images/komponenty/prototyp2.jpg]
	
	\caption{Prototyp zařízení}
\end{figure}

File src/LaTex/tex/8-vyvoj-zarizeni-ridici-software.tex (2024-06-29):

\chapter{Vývoj zařízení - Řídící software}
\label{5-vyvoj-zarizeni-ridici-software}
%V této kapitole bude popsána tvorba řídícího programu pro Arduino.

\section{Programovací jazyk}

Nejběžněji bývá pro tvorbu řídícího programu pro Arduino využívána varianta jazyka C++, která využívá struktury převzaté z~jazyka Wiring. Alternativně lze použít jazyky jako MicroPython, JavaScript a další. Ve Wiringu se namísto typické funkce \texttt{main} pro C++ používají funkce \texttt{setup} pro prvotní inicializaci při spuštění programu a funkce \texttt{loop} pro nekonečnou smyčku, která program nepřetržitě vykonává \cite{arduino}.

\section{Vývojové prostředí}
Pro tvorbu a nahrání řídicího programu do mikrokontroléru se využívá \zkratka{IDE}. Mikrokontroléry, na rozdíl od jednodeskových mikropočítačů, nejsou vybaveny operačním systémem. Nelze tedy tvořit kód přímo na mikro\-kontroléru, je potřeba jej vytvořit na počítači, zkompilovat a následně nahrát jako binární soubor do mikro\-kontroléru. Pro tvorbu řídicího programu bylo konkrétně využito Arduino \zk{IDE}. To nabízí kromě možnosti psaní, kompilování a nahrávání kódu i správu knihoven a čtení dat z~Arduina pro ladění kódu. Kromě vývojového prostředí Arduino \zk{IDE} bylo využíváno prostředí VS Code od společnosti Microsoft, které umožňuje verzování pomocí Gitu a sdílení kódu na platformě GitHub.

\begin{figure}[H]
	\centering
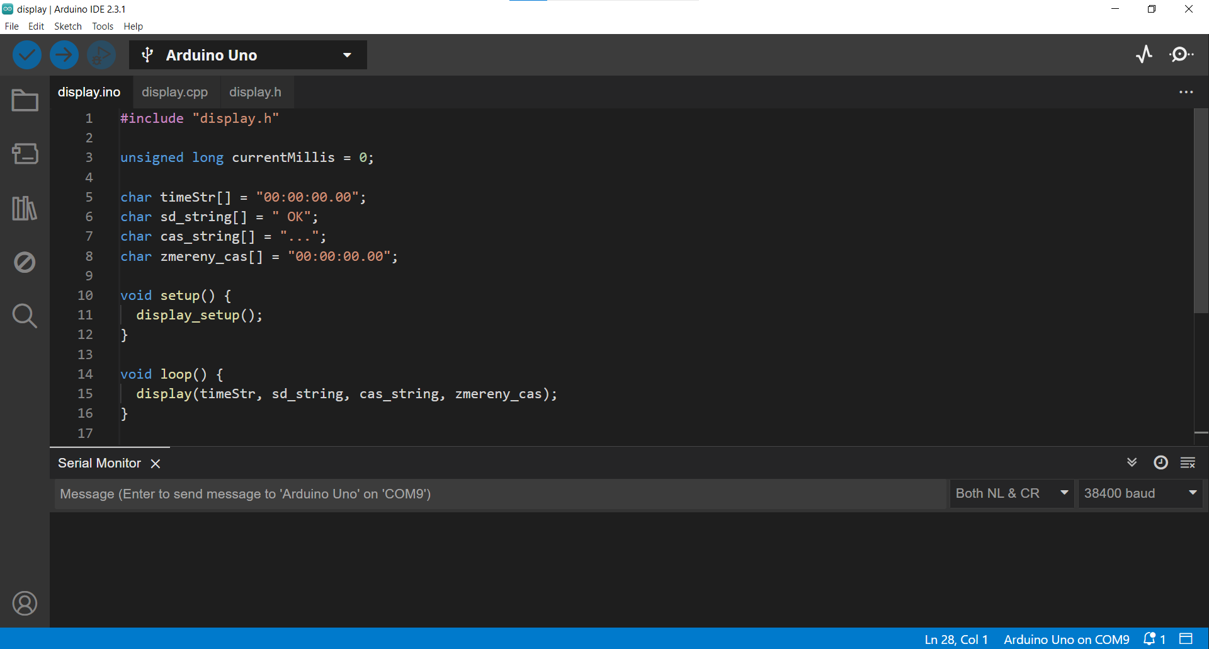
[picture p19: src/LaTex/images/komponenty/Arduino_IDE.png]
	
	\caption{Arduino IDE}
\end{figure}

\section{Použité knihovny}
Pro práci s~některými komponenty byly využity již existující knihovny, které usnadňují využití jejich funkcionality. Knihovna \href{https://www.arduino.cc/en/Reference/SoftwareSerial}{\texttt{SoftwareSerial.h}} byla využita pro emulaci pinů sloužících pro sériovou komunikaci, protože Arduino UNO obsahuje pouze jeden TX a jeden RX pin, určený pro sériovou komunikaci. Pro práci s~údaji o~čase byla využita knihovna \href{https://www.pjrc.com/teensy/td_libs_Time.html}{\texttt{TimeLib.h}}. Pro synchronizaci času prostřednictvím signálu z~DCF77 přijímače byla využita knihovna \href{https://github.com/thijse/Arduino-DCF77}{\texttt{DCF77.h}}. Tato knihovna obsahuje funkce pro dekódování signálu DCF77. Pro přístup k~NTP serveru byly využity knihovny \href{https://github.com/esp8266/Arduino/tree/master/libraries/ESP8266WiFi}{\texttt{WiFiS3.h}} a \href{https://www.arduino.cc/en/Reference/WiFi}{\texttt{WiFiUdp.h}}. Ty slouží pro připojení k~WiFi a přijímaní a odesílání paketů, které využívá NTP server. Pro práci s~Micro SD kartou byla využita knihovna \href{https://www.arduino.cc/en/Reference/SD}{\texttt{SD.h}}. Tato knihovna obsahuje funkce pro zapisování dat na Micro SD kartu a čtení dat z~ní. Pro práci s~OLED displejem byla nejprve využívána knihovna \href{https://github.com/olikraus/u8glib}{\texttt{U8glib.h}}, která ale není kompatibilní s~mikrokontroléry Renesas, a tak byla využita knihovna \href{https://github.com/olikraus/u8g2}{\texttt{U8g2lib.h}}. Pro práci s~hlasovým modulem byla využita knihovna \href{https://github.com/DFRobot/DFRobotDFPlayerMini}{\texttt{DFRobotDFPlayerMini.h}}.

\section{Členění kódu}
Řídící program byl rozdělen z~důvodu přehlednosti na hlavní program \texttt{(*.ino)}, který sdružuje další části kódu ve formě hlavičkových (\texttt{*.h}) a implementačních souborů (\texttt{*.cpp}). Během tvorby řídícího programu byly využity již existující kniho\-vny a při tvorbě kódu bylo vycházeno ze vzorových kódů, které k~nim byly přiložené v~dokumentaci. Nicméně některé části kódu byly vytvořeny zcela nově. \text{Například} bylo potřeba zajistit, aby stisknutí tlačítka bylo považováno za stisknutí pouze v~prvním průchodu funkcí \texttt{loop}, a v~dalších průchodech již nebylo tlačítko považováno za stisknuté tak, aby bylo provedeno při každém stisku jen jedno měření a měření bylo přehledné a jednoznačné. Kód pro příjem dat z~GNSS přijímače byl vytvořen také kompletně od začátku. V~tomto kódu je načítána pomocí sériové komunikace NMEA zpráva. Ta je parsována a je z~ní zjišťováno, zda byla určena poloha přijímače. Pokud je určena poloha přijímače lze považovat čas za aktuální. V~tom případě je text s~časem převeden na číselné hodnoty a s~těmi je dále praco\-váno. Dalším pří\-kladem je funkce setiny. Jelikož všechny použité přijímače poskytují data po celých sekundách, tak byla vytvořena funkce setiny, která je spuštěna vždy na začátku celé sekundy a rozděluje ji na setiny sekund. Při každé nové sekundě jsou setiny sekund vynulovány. Od začátku byla také vyhotovena část kódu pro komunikaci s~totální stanicí a další části kódu.

\vspace{1cm}

\begin{figure}[H]
\hspace{-1cm}
\begin{tikzpicture}[
    startstop/.style={rectangle, rounded corners, minimum width=2cm, minimum height=0.5cm,text centered, draw=black, fill=red!30},
    io/.style={trapezium, trapezium left angle=70, trapezium right angle=110, minimum width=2cm, minimum height=0.5cm, text centered, draw=black, fill=blue!30},
    process/.style={rectangle, minimum width=2cm, minimum height=0.5cm, text centered, draw=black, fill=orange!30},
    decision/.style={diamond, minimum width=2cm, minimum height=0.5cm, text centered, draw=black, fill=green!30},
    arrow/.style={thick,->,>=stealth},
]

\node (init) [startstop] {Inicializace zařízení};
\node (sdCheck) [process, below of=init, yshift=-0.25cm] {Kontrola připojení micro SD karty};
\node (timeAttempt) [process, below of=sdCheck, yshift=-0.25cm] {Pokus o~aktualizaci času};
\node (display) [process, below of=timeAttempt, yshift=-0.25cm] {Zobrazení aktuálního stavu na displeji};
\node (buttonCheck) [decision, below of=display, yshift=-2cm, align=center] {Kontrola\\stisknutí\\tlačítka};
\node (saveTime) [process, right of=buttonCheck, xshift=5.5cm] {Uložení aktuálního času};
\node (tsRequest) [process, below of=saveTime, yshift=-0.25cm] {Odeslání požadavku TS};
\node (saveTsData) [process, below of=tsRequest, yshift=-0.25cm] {Uložení dat z~TS};
\node (info) [process, below of=saveTsData, yshift=-0.25cm] {Signalizace};
\node (btCheck) [decision, below of=buttonCheck, yshift=-3.75cm, align=center] 
{Kontrola\\ požadavku\\ Bluetooth};

\node (uzel) [startstop, left of=btCheck, xshift=-5cm, align=center, fill=white, draw=white] {};

\node (openFile) [process, below of=btCheck, yshift=-2.1cm] {Otevření souboru s~měřenými daty};
\node (sendData) [process, below of=openFile, yshift=-0.25cm] {Odeslání dat přes Bluetooth};

\draw [arrow] (init) -- (sdCheck);
\draw [arrow] (sdCheck) -- (timeAttempt);
\draw [arrow] (timeAttempt) -- (display);
\draw [arrow] (display) -- (buttonCheck);
\draw [arrow] (buttonCheck.east) -- ++(1,0) |- node[yshift=0.2cm] {ano} (saveTime.west);
\draw [arrow] (saveTime) -- (tsRequest);
\draw [arrow] (tsRequest) -- (saveTsData);
\draw [arrow] (saveTsData) -- (info);
\draw [arrow] (info) |- (btCheck);

\draw [arrow] (btCheck.west) -- ++(0,0) |- node[yshift=0.2cm,xshift=-2cm] {ne} (uzel.center);

\draw [arrow] (buttonCheck) -- node[anchor=east] {ne} (btCheck);
\draw [arrow] (btCheck) -- node[xshift=0.5cm] {ano} (openFile);
\draw [arrow] (openFile) -- (sendData);
\draw [arrow] (sendData) |- ++(0,-1) -- ++(-6,0) |- (sdCheck);

\end{tikzpicture}
\caption{Zjednodušené schéma řídícího programu}
\end{figure}

% https://bastlirna.hwkitchen.cz/zakladni-struktury-jazyka-wiring/

% https://www.arduino.cc/reference/en/

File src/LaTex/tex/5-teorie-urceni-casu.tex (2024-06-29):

\chapter{Teorie - Možnosti určení času}
\label{4-teorie-urceni-casu}
Existuje mnoho možností, jak synchronizovat čas. Mezi nejběžnější patří synchronizace pomocí internetu, rádiového signálu nebo GNSS přijímače.

\section{Internet}
Na internetu jsou dostupné zdroje poskytující informace o~aktuálním koordinovaném světovém čase UTC. Hlavní výhodou synchronizace času pomocí internetu je její snadná dostupnost. Tato metoda je dostupná celosvětově na všech místech s~připojením k~internetu. Nevýhodou je, že může být přesnost synchronizace času ovlivněna latencí internetového připojení. Nejčastěji se lze setkat s~\zk{API} a \zk{NTP} servery.

\subsection{API}
\zkratka{API} je rozhraní, které slouží pro předávání dat mezi softwarovými aplikacemi.
\zk{API} může být použito k~získání času z~webové služby. Například, World Time API slouží pro získání aktuálního času a poskytuje čas pro konkrétní časová pásma ve tvaru Unixového času, nebo ve tvaru podle ISO8601. Data jsou poskytována ve formátu prostého textu nebo jako JSON \cite{worldtimeapi}.

\subsection{NTP}
\zkratka{NTP} servery jsou nejběžněji využívaným zdrojem pro synchronizaci času přes internet. \zk{NTP} je navržený tak, aby na něj neměla velký vliv proměnlivá latence internetového připojení. K~posílání informací slouží v~\zk{NTP} serverech takzvané packety, které obsahují vždy menší množství dat. K~omezení vlivu latence internetového připojení jsou využívány sofistikované algoritmy, díky nimž se přesnost synchronizace času pohybuje do 10 ms \cite{timetools}. Příkladem NTP serveru je Google Public NTP a NTP Pool \cite{ntppool}.
%https://home.zcu.cz/~poupa/pccas.html
% 50ms je sntp
%klasické ntp je lepší : https://timetoolsltd.com/ntp/ntp-timing-accuracy/

\section{Rádiový signál}
Existují vysílače, které vysílají informace o~čase pomocí radiových vln. Tyto signály jsou obvykle velmi přesné, ale jejich příjem může být ovlivněn atmosférickými podmínkami nebo rušením signálu. Příkladem těchto vysílačů jsou WWVB v~USA, MSF ve Velké Británii a DCF77 v~Německu. V~minulosti existoval v~ČR vysílač OMA 50, který od roku 1995 není v~provozu \cite{vyvoj_hw_poupa}.% seznam vysílačů: https://en.wikipedia.org/wiki/Radio_clock

\subsection{DCF77}
Vzhledem k~omezenému dosahu rádiového signálu má na území ČR smysl uvažovat o~využití pouze signálu DCF77. Vysílač DCF77 vysílá čas vycházející z~měření cesiových atomových hodin Fyzikálně-technického institutu v~Braunschweigu (PTB). Tento vysílač vysílá dlouhovlnné rádiové vlny na kmitočtu 77,5 kHz. Výkon vysílače je 50kW. Vysílač vysílá nepřetržitě od roku 1970 a odstaven je jen velmi výjimečně z~důvodů údržby. Teoretický dosah vysílače je uváděn až 2000 km, což však platí jen za ideálních podmínek. Dosah vysílače i za méně příznivých podmínek je udáván 1100~km, což stále pokrývá celé území České republiky.\cite{ptb_dcf77} Název DCF77 vychází z~označení:
\begin{description}[leftmargin=!,labelwidth=\widthof{\bfseries D --}]
    \item[\textbf{D} --] Deutschland (Německo)
    \item[\textbf{C} --] Označení pásma dlouhých vln
    \item[\textbf{F} --] Frankfurtský region
    \item[\textbf{77} --] Vysílací frekvence (77,5 kHz)
\end{description}

\textbf{Časový kód signálu DCF77:}
Každou minutu vysílač vysílá informaci o~\text{minutě}, hodině, dni v~týdnu, měsíci a roku pomocí amplitudové modulace. Tato \text{informace} platí vždy pro následující minutu \cite{fel_dcf77}. Dále je signál modulován pomocí pseudo\-náhodné fázové modulace, která slouží pro přenos pseudonáhodného šumu, který lze využít pro přesnější určení času \cite{vyvoj_hw_poupa} \cite{ptb_2012}.

\begin{figure}[H]
	\centering
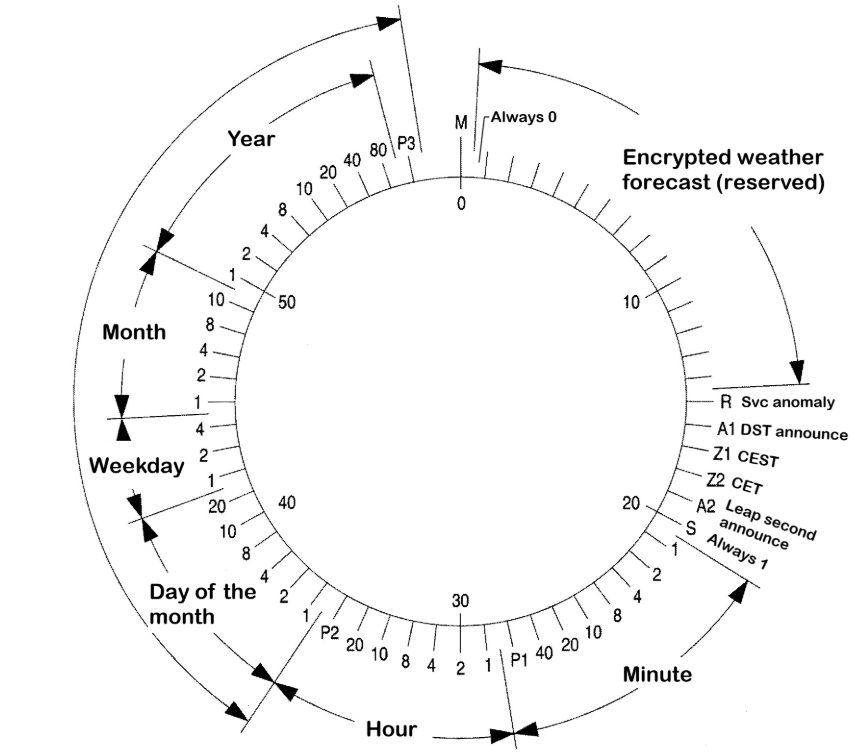
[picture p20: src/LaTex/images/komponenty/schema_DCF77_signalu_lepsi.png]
	
	\caption{Schéma signálu DCF 77 \cite{fel_dcf77}}
\end{figure}

\textbf{Rušení signálu DCF77:}
Signál DCF77 se šíří ohybem po povrchu Země a odrazem od ionosféry. Odrazy od ionosféry jsou přes den slabé, a proto je signál během dne slabší. Signál DCF77 je rušen z~několika zdrojů. Jedním zdrojem rušení je atmosférický šum způsobený činností ionosféry a může dosahovat velikosti až 80~dB. Atmosférický šum je proměnlivý. Dále může být signál rušen průmyslovou činností, například vlivem vysokonapěťového vedení \cite{vyvoj_hw_andel} \cite{hopf_dcf77}.

\section{GNSS}
Pro určení času lze využít \zkratka{GNSS} jako je GPS, GLONASS nebo Galileo. Družice těchto systémů vysílají časové informace spolu s~navigačními daty. Na satelitech těchto systémů jsou obvykle cesiové atomové hodiny a záložní rubidiové atomové hodiny, které poskytují velmi přesný zdroj času. Signál z těchto družic jsou schopny přijímat GNSS přijímače. Signál je ovšem z~důvodu tranzitní doby opožděn. Pokud přijímač přijímá v~jednu epochu signál alespoň ze čtyř družic, je schopen spočítat opravu hodin přijímače a tím získat svůj přesný čas. Tento čas poskytují GNSS přijímače prostřednictvím NMEA zprávy.

Je potřeba si uvědomit, že například GPS družice pracují v~GPS čase, který je odlišný od času UTC. Součástí NMEA zprávy \$GNZDA je však už čas přepočítaný do UTC \cite{ublox}. Tato metoda poskytuje velmi přesný čas a je dostupná kdekoliv na Zemi, ale vyžaduje přímý výhled na oblohu pro příjem signálů od alespoň čtyř satelitů, aby bylo možné spočítat i opravu hodin přijímače.

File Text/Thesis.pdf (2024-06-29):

## ČESKÉ VYSOKÉ UČENÍ TECHNICKÉ V PRAZE

## FAKULTA STAVEBNÍ

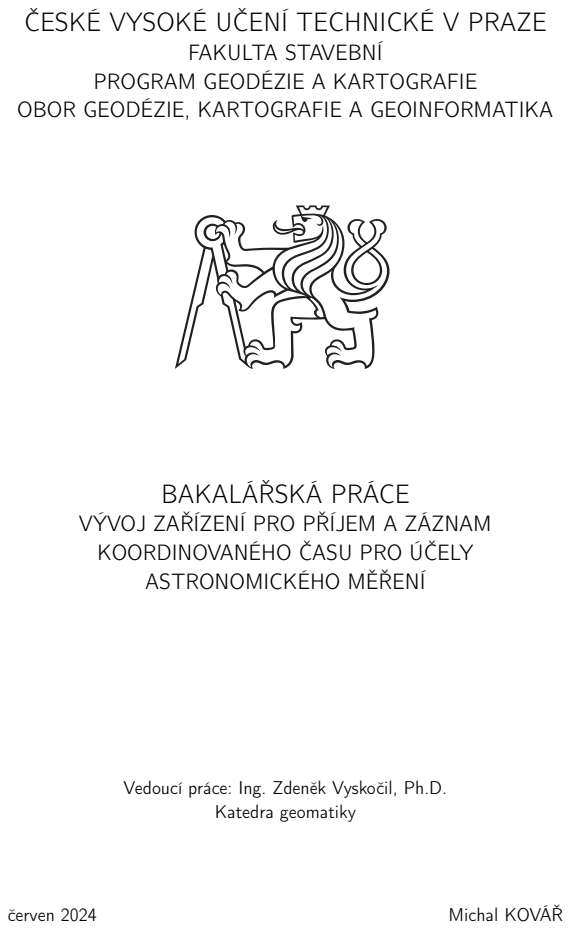
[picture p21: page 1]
BAKALÁŘSKÁ PRÁCE; Katedra geomatiky; červen 2024; Michal KOVÁŘ

PROGRAM GEODÉZIE A KARTOGRAFIE

OBOR GEODÉZIE, KARTOGRAFIE A GEOINFORMATIKA

VÝVOJ ZAŘÍZENÍ PRO PŘÍJEM A ZÁZNAM
KOORDINOVANÉHO ČASU PRO ÚČELY
ASTRONOMICKÉHO MĚŘENÍ

Vedoucí práce: Ing. Zdeněk Vyskočil, Ph.D.

ČESKÉ VYSOKÉ UČENÍ TECHNICKÉ V PRAZE Fakulta stavební
Thákurova 7, 166 29 Praha 6

## ZADÁNÍ BAKALÁŘSKÉ PRÁCE

I. OSOBNÍ A STUDIJNÍ ÚDAJE

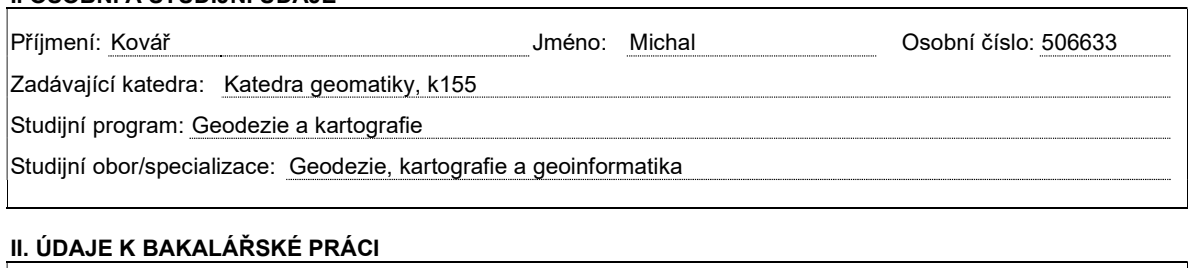
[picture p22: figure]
Příjmení: Kovář; Jméno: Michal; Osobní číslo: 506633; Zadávající katedra: Katedra geomatiky, k155; Studijní program: Geodezie a kartografie; II. ÚDAJE K BAKALÁŘSKÉ PRÁCI

Studijní obor/specializace: Geodezie, kartografie a geoinformatika

Název bakalářské práce: Vývoj zařízení pro příjem a záznam koordinovaného času pro účely astronomického měření
Název bakalářské práce anglicky: Development of a device for receiving and recording coordinated time for astronomical measurement purposes Pokyny pro vypracování:

### 1. Návrh zařízení pro příjem a záznam koordinovaného času 2. Realizace návrhu 3. Vývoj řídícího software 4. Testování

Seznam doporučené literatury:

Jméno vedoucího bakalářské práce: Ing. Zdeněk Vyskočil, Ph.D.

Datum zadání bakalářské práce: 9.2. 2024 | Termín odevzdání BP v IS KOS: 20. 5. 2024 Údaj uveďte v souladu s datem v časovém plánu příslušného ak. roku
Podpis vedoucího práce | Podpis vedoucího katedry

III. PŘEVZETÍ ZADÁNÍ
Beru na vědomí, že jsem povinen vypracovat bakalářskou práci samostatně, bez cizí pomoci, s výjimkou poskytnutých konzultací. Seznam použité literatury, jiných pramenů a jmen konzultantů je nutné uvést v bakalářské práci a při citování postupovat v souladu s metodickou příručkou ČVUT „Jak psát vysokoškolské závěrečné práce“ a metodickým pokynem ČVUT „O dodržování etických principů při přípravě vysokoškolských závěrečných prací“.
Datum převzetí zadání | Podpis studenta(ky)

ABSTRAKT

Tato bakalářská práce se zabývá vývojem zařízení, které je schopné přijímat a zazna-

menávat koordinovaný čas (UTC) pro účely astronomického měření v geodézii. Nejprve

je popsána teorie časových soustav a teorie astronomického měření, včetně požadavků

na přesnost určení času. Následně jsou popsány možnosti příjmu koordinovaného času.

Práce dále popisuje jednotlivé komponenty využité pro tvorbu tohoto zařízení. Je pop-

sána konstrukce výsledného zařízení a řídící program, který zařízení ovládá. Na závěr je

testována funkčnost zařízení.

KLÍČOVÁ SLOVA

astronomické měření, astronomický azimut, časové soustavy, UTC, synchronizace času,

Arduino, NTP, DCF77, GNSS

### ABSTRACT

This bachelor’s thesis deals with the development of a device that is able to receive and

record Coordinated Universal Time (UTC) for the purposes of astronomical measure-

ments in geodesy. Initially, the theory of time systems and principles of astronomical

measurement are described, including the specification of accuracy requirements for time

determination. Subsequently, the possibilities for receiving coordinated time are explored.

The thesis further describes the individual components used for the creation of this de-

vice. It details the construction of the resulting device and the control program that

operates it. At the end, the functionality of the device is tested.

KEYWORDS

astronomical measurement, astronomical azimuth, time systems, UTC, time synchro-

nization, Arduino, NTP, DCF77, GNSS

### PROHLÁŠENÍ

Prohlašuji, že bakalářskou práci na téma „Vývoj zařízení pro příjem a záznam koordi-

novaného času pro účely astronomického měření“ jsem vypracoval samostatně. Použitou

literaturu a podkladové materiály uvádím v seznamu zdrojů.

V Praze dne | | | |
| | (podpis autora)

### PODĚKOVÁNÍ

Chtěl bych poděkovat Ing. Zdeňku Vyskočilovi, Ph.D za jeho ochotu a velké

množství cenných rad při vedení této bakalářské práce. Dále bych chtěl poděkovat

Ing. Janu Holešovskému za rady ohledně průběhu astronomického měření a v neposlední řadě paní Kerstin Eisold za zakoupení součástek, které nebyly v České republice dostupné.

Velké poděkování také patří mé rodině za podporu během celého studia.

## Obsah

1 Úvod | 10
2 Rešerše | 11
3 Teorie - Čas | 12
4 Teorie - Astronomické měření | 15
5 Teorie - Možnosti určení času | 17
6 Vývoj zařízení - Komponenty | 20

7 Vývoj zařízení - Konstrukce | 29
8 Vývoj zařízení - Řídící software | 35
9 Testování | 38
10 Závěr | 41
Seznam zkratek | 43
Literatura | 44
Seznam příloh | 47

## Seznam obrázků

4.1 Schéma konverze časových údajů | 16
5.1 Schéma signálu DCF 77 [12] | 18
6.1 Arduino UNO R4 ve verzi WiFi [15] | 21
6.2 Arduino Mega [3] | 21
6.3 Přijímač radiového signálu DCF77 [7] | 22
6.4 GNSS přijímač Ublox NEO-M8T [9] | 23
6.5 GNSS přijímač Ublox NEO 7M [7] | 23
6.6 Čtečka Micro SD karet [7] | 23
6.7 Rotační enkodér [7] | 24
6.8 OLED displej [7] | 24
6.9 Hlasový modul [15] | 25
6.10 Reproduktor [3] | 25
6.11 Modul s RGB LED [7] | 26
6.12 Převodník TTL na RS232 [15] | 26
6.13 Bluetooth modul HC-05 [7] | 27
6.14 Výsledná DPS | 27
7.1 Výstupy pinů pro Arduino UNO R4 [3] | 29
7.2 Schéma zapojení komponentů pro Arduino Uno | 30
7.3 Ukázka návrh DPS v softwaru Autodesk Eagle | 33
7.4 Ukázka osazené DPS pro prototyp zařízení | 33
7.5 Prototyp zařízení | 34
8.1 Arduino IDE | 35
8.2 Zjednodušené schéma řídícího programu | 37
9.1 Histogram počtu synchronizací | 39

## Seznam tabulek

4.1 Rozdíly azimutů Slunce v závislosti na rozdílu časů UTC | 16
6.1 Porovnání kapacity paměti Arduina UNO R3 a R4 [3] | 20
6.2 Cena použitých součástek | 28
9.1 Porovnání časů z různých zdrojů | 40

ČVUT v Praze | 1. ÚVOD

## 1 Úvod

V minulosti bylo velmi obtížné určit přesnou polohu objektů na Zemi. Poloha ob-

jektů na Zemi byla určována především pomocí geodetické astronomie. Určovaly se

astronomické zeměpisné souřadnice (astronomická zeměpisná šířka a astronomická

zeměpisná délka) a astronomické azimuty. Během astronomického měření se na

rozdíl od klasické geodézie měří na pohyblivé cíle a je tedy nutné zaznamenávat

i čas jednotlivých měření. Přesnost určení času má významný vliv na přesnost

konkrétních výsledků.

V dnešní době byly metody geodetické astronomie z velké části nahrazeny meto-

dami kosmické geodezie, jako jsou GNSS a VLBI. Avšak pro výukové účely má

astronomické měření stále svůj význam. V současné době se v rámci výuky teoretické

geodezie zaměřují astronomické azimuty na Slunce. Během tohoto měření se synchro-

nizují stopky (zpravidla na chytrém telefonu) pomocí analogového přijímače signálu

DCF77 ručně, a při vlastním měření se záznam provádí druhou osobou na slovní

pokyn měřiče. To je příčinou velkých nepřesností v určení času, které negativně

ovlivňují výsledky celého astronomického měření.

Cílem této práce je navrhnout a vytvořit zařízení schopné přijímat a zaznamenávat

koordinovaný čas pro účely astronomického měření (Astrochronograf). Toto zařízení

by mělo být schopno automaticky synchronizovat svůj vnitřní čas, aby nedocházelo

k chybě z ruční synchronizace. Mělo by být jednoduché na ovládání tak, aby

mohl astronomické měření snadno provádět i jednotlivec, díky čemuž se eliminuje

prodleva způsobená slovním pokynem. Zařízení by mělo být také schopné informovat

měřiče o průběhu měření, včetně stavu synchronizace a posledního změřeného času,

a umožnit snadný export přehledně zaznamenaných měřených dat.

Výsledné zařízení by mělo být testováno, aby byla ověřena jeho funkčnost. Dále

by mělo být zjištěno, jak přesně je zařízení schopno synchronizovat svůj vnitřní čas,

jak přesně je schopné zaznamenat měřený čas a jaký vliv má zlepšení určení času

na konečné výsledky astronomického měření.

ČVUT v Praze | 2. REŠERŠE

## 2 Rešerše

Nepodařilo se dohledat žádnou práci, která by se zabývala explicitně tvorbou zařízení

pro příjem a záznam koordinovaného času pro účely astronomického měření. Podařilo

se však dohledat zdroje, které se zabývají souvisejícími tématy. Geodetickou astro-

nomií se zabývají skripta:

1. Geodetická astronomie 10: Toto skriptum bylo vydáno nakladatelstvím ČVUT

a zabývá se obecně geodetickou astronomií. Ve skriptu je popsána nauka o čase,

metody geodetické astronomie, přístroje pro astronomické měření včetně přístrojů

pro měření času. Skriptum dále obsahuje rozbory přesnosti pro astronomické

měření a zmiňuje i požadavky na přesnost určení času [13].

2. Geodetická astronomie I. a základy kosmické geodézie: Toto skriptum, bylo

vydáno nakladatelstvím VUTIUM a zabývá se geodetickou astronomií a kosmickou

geodezií. Pro tuto práci je v něm důležitá především kapitola o časech a časových

systémech [8].

Tvorbou zařízení, které umí synchronizovat svůj vnitřní čas se zabývají práce:

1. „Časový normál pro centralizovanou správu elektronických hodin“: Tato bakalářská

práce se zabývá návrhem a realizací hodinové ústředny, která po zisku časového

normálu vzdáleně řídí elektronické hodiny. K synchronizaci času tato práce

využívá tři nezávislé zdroje (DCF77, GPS a NTP server) [19].

2. „Elektronické hodiny“: Tato bakalářská práce se zabývá synchronizací času pomocí

DCF77 a GPS přijímače [11].

3. „Synchronizace času pro odloučená měřící stanoviště“: Tato diplomová práce se

zabývá tvorbou zařízení, které pomocí signálu DCF77 synchronizuje čas osobního

počítače [26].

ČVUT v Praze | 3. TEORIE - ČAS

## 3 Teorie - Čas

Aby bylo možné měřit čas, je potřeba sledovat periodicky se opakující jev. V minu-

losti se předpokládalo, že rotace Země je rovnoměrná, a tak se pro měření času

využívalo měření zdánlivého pohybu nebeských objektů, který je daný rotací Země kolem své osy. Časy vycházející z rotace Země se nazývají rotační časy. Vzhledem

k nerovnoměrné rotaci Země, způsobené vlivem precese a nutace, bylo potřeba

definovat čas přesněji. K tomu se využívají fyzikálně definované časy, které nejsou

navázané na rotaci Země [8].

## 3.1 Rotační časy

Všechny rotační časy jsou odvozené od nerovnoměrné rotace Země a jsou tedy

také nerovnoměrné. Rotační časy lze dělit na místní a světové. Místní časy se

vztahují k astronomické zeměpisné délce pozorovatele λ. Světové (greenwichské)

jsou vztažené k základnímu (greenwichskému) poledníku. Podle toho, zda rotační

časy vychází ze zdánlivého pohybu jarního bodu à nebo Slunce, je lze dále dělit na

časy hvězdné a časy sluneční [13].

### 3.1.1 Rotační časy hvězdné

Hvězdné časy jsou definovány jako hodinový úhel jarního bodu à. Světové hvězdné

časy jsou vztaženy k základnímu (Greenwichskému) poledníku a jsou tedy definovány

jako úhel, který je měřený mezi směrem k jarnímu bodu à a základním poledníkem

v rovině rovníku. Místní hvězdné časy jsou definovány analogicky, avšak namísto

k základnímu poledníku se vztahují k místnímu poledníku. Hvězdný den je definovaný

jako časový interval mezi dvěma po sobě jdoucími horními kulminacemi jarního

bodu. Dále lze hvězdné časy dělit na pravé a střední. Pravé hvězdné časy jsou

vztaženy k pravému jarnímu bodu a jsou ovlivněny precesí i nutací. Střední hvězdné

časy jsou vztažené ke střednímu jarnímu bodu a jsou ovlivněné pouze precesí.

Rozdíl pravého místního hvězdného času s a pravého světového hvězdného času

S je totožný, jako rozdíl středního místního hvězdného času s a středního světového

hvězdného času S. Tento rozdíl je zároveň roven astronomické zeměpisné šířce

místního poledníku λ [13].

s − S = s − S = λ | (3.1)

ČVUT v Praze | 3. TEORIE - ČAS

### 3.1.2 Rotační časy sluneční

Smysl zavedení slunečních časů spočívá v tom, že sluneční časy korespondují s naším

vnímáním světla a tmy. Sluneční den je definován jako časový interval mezi dvěma po

sobě jdoucími dolními kulminacemi Slunce. V důsledku rotace Země kolem Slunce

urazí Země každý den v rovině ekliptiky více než 1°, což mění směr ke Slunci a

způsobuje, že sluneční den je zhruba o 4 minuty delší, než hvězdný den [8]. Sluneční

časy lze rozdělit na pravé sluneční časy a střední sluneční časy. Pravé sluneční časy

vychází ze zdánlivého pohybu pravého (skutečného) Slunce. Střední sluneční časy

vychází z pohybu fiktivního středního Slunce, které se pohybuje rovnoměrně v rovině rovníku. Často používaným časovým standardem je střední světový sluneční čas

(UT) [13].

## 3.2 Fyzikální časy

Fyzikálně definované časy vznikly kvůli nedostatečné přesnosti rotačních časů, způ-

sobené nerovnoměrnou rotací Země. Pro dosažení vyšší přesnosti při určování času

je zapotřebí měřit stabilnější, periodicky se opakující jev. V praxi se nejčastěji

využívají hodiny, které jsou založené na měření kmitání atomu cesia. Tyto hodiny

se nazývají cesiové atomové hodiny. Z měření kmitů atomu cesia vychází atomová

sekunda, která je základní jednotkou času podle mezinárodního systému jednotek

(SI) [13].

## 3.3 Časové soustavy

Jelikož je čas odvozený z rotace Země nerovnoměrný, tak mezinárodní časová služba

(BIH) zavedla soustavu světových časů [8].

### 3.3.1 Univerzální čas UT0

Jde o střední světový sluneční čas (UT), který je vázaný k místu měření, jelikož je

ovlivňován pohybem pólu vzhledem k danému místu měření [13].

### 3.3.2 Univerzální čas UT1

Nerovnoměrnosti v čase UT0, způsobené kolísáním pravého pólu, jsou v čase UT1

eliminovány zavedením redukce na střední polohu pólu ∆λp [13].

UT1 = UT0 − ∆λp | (3.2)

ČVUT v Praze | 3. TEORIE - ČAS

### 3.3.3 Mezinárodní Atomový čas (TAI)

Mezinárodní atomový čas (TAI, Temps Atomique International) je získán prostřed-

nictvím měření času množstvím nejpřesnějších atomových hodin po celém světě. Časy jednotlivých hodin se liší vlivem systematických chyb a vlivem relativistic-

kých efektů. Po zavedení oprav pro každé atomové hodiny, je mezinárodní atomový

čas (TAI) získán jako vážený průměr časů všech zapojených hodin [13] [8]. Z TAI

vychází i GPS čas, který byl zvolen tak, aby se rovnal času UTC v epoše GPS 6.

ledna 1980 [14]. Vztah mezi TAI a GPS časem je:

GP S = T AI − 19 s | (3.3)

### 3.3.4 Univerzální koordinovaný čas (UTC)

Jelikož TAI není vázaný na rotaci Země a UT1 je nerovnoměrný, byl zaveden

univerzální koordinovaný čas (UTC). Ten vychází z TAI, ale je uměle udržován

v blízkosti rotačního času UT1. Délka sekundy TAI i UTC je shodná. Vlivem

nerovnoměrné rotace Země se přidává přestupná sekunda, která udržuje čas UTC

v blízkosti UT1. Rozdíl mezi UTC a UT1 je nazýván DUT1 a nikdy nepřesáhne

hodnotu ±0,9s. Rozdíl mezi TAI a UTC je počet přestupných sekund n [13].

DUT1 = UT1 − UT C | (3.4)
n = T AI − UT C | (3.5)

UTC se běžně používá jako občanský čas. Vychází z něj i pásmové varianty SEČ a

SELČ, které vznikají přičtením jedné, respektive dvou hodin. UTC slouží také pro

tvorbu rádiových časových signálů [13].

ČVUT v Praze | 4. TEORIE - ASTRONOMICKÉ MĚŘENÍ

## 4 Teorie - Astronomické měření

Astronomické měření bylo na našem území prováděno od roku 1863 do roku 1974.

Metody měření se v průběhu času měnily v závislosti na aktuálním vědeckém poznání

a na přesnosti, s jakou bylo možno určovat čas. Například měření zeměpisné délky

vztažené k základnímu poledníku byla započata až roku 1927, díky existenci rá-

diových časových signálů. Astronomické měření bylo prováděno především v rámci

astronomicko-geodetické sítě (AGS). Body, u nichž byly určeny astronomické země-

pisné souřadnice a astronomický azimut, se nazývají Laplaceovy body [13].

## 4.1 Astronomické azimuty

V rámci výuky Teoretické geodézie na FSv ČVUT se měří pouze astronomické

azimuty Slunce metodou určení hodinového úhlu, a tak zde bude zmíněn pouze

požadavek přesnosti určení času pro toto měření. Výpočet astronomického azimutu

vychází se vztahu:

tg(A) = | sin(t) sin(φ) · cos(t) − cos(φ) · tg(δ) (4.1)

kde δ je deklinace Slunce a lze ji zjistit například z astronomických tabulek

a t je hodinový úhel získaný ze vztahu:

t = S + λ − α | (4.2)

kde α je rektascenze Slunce a lze ji zjistit například z astronomických tabulek

S je pravý světový hvězdný čas, který je ovlivněn precesí i nutací a lze jej

dopočítat z různých časů pomocí vztahů popsaných v kapitole 3 [13]. Způsob

převodu mezi různými časy je naznačen zde:

ČVUT v Praze | 4. TEORIE - ASTRONOMICKÉ MĚŘENÍ

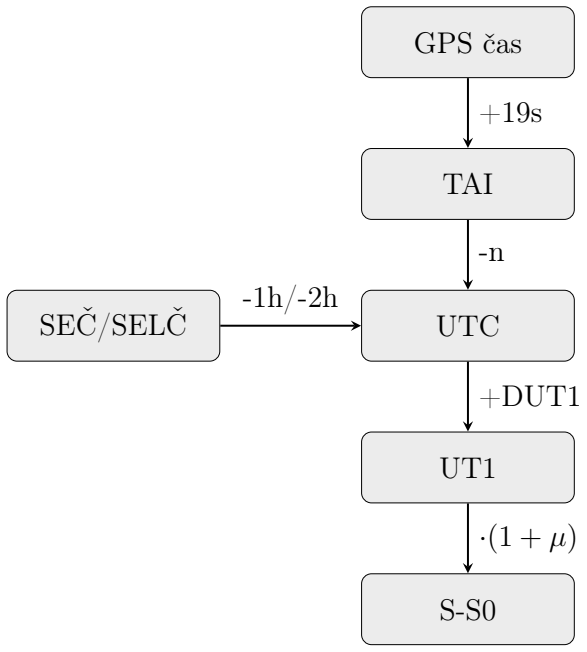
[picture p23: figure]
GPS čas; TAI; SEČ/SELČ; UTC; +DUT1

*S0 je světový hvězdný čas pro 0h UT1 [h] v den pozorováni

*μ lze dohledat v astronomických tabulkách

Obrázek 4.1: Schéma konverze časových údajů

Do výpočtu tedy vstupují zeměpisné souřadnice stanoviska a čas měření na

Slunce, zbylé hodnoty lze zjistit z astronomických tabulek a bulletinu mezinárodní

služby IERS. Experimentálním dosazením hodnot do vztahů (4.1) pro zeměpisné

souřadnice stanoviska 50° s. š. a 15° v. d. a hodnot vycházejících z časů UTC

lišících se o 1s 0.1s a 0.01s byl orientačně zjištěn vliv chyby v určení času na výsledný

astronomický azimut Slunce.

Tab. 4.1: Rozdíly azimutů Slunce v závislosti na rozdílu časů UTC

∆ UTC [s] | Rozdíl azimutů ["] | Rozdíl azimutů [cc]
1 | 13.93 | 43.01
0.1 | 1.39 | 4.30
0.01 | 0.13 | 0.43

Z tabulky vyplývá, že aby byla chyba v určení azimutu Slunce menší než jedna

úhlová vteřina, je potřeba určovat čas s přesností na setiny sekund.

ČVUT v Praze | 5. TEORIE - MOŽNOSTI URČENÍ ČASU

## 5 Teorie - Možnosti určení času

Existuje mnoho možností, jak synchronizovat čas. Mezi nejběžnější patří synchro-

nizace pomocí internetu, rádiového signálu nebo GNSS přijímače.

## 5.1 Internet

Na internetu jsou dostupné zdroje poskytující informace o aktuálním koordinovaném

světovém čase UTC. Hlavní výhodou synchronizace času pomocí internetu je její

snadná dostupnost. Tato metoda je dostupná celosvětově na všech místech s připo-

jením k internetu. Nevýhodou je, že může být přesnost synchronizace času ovlivněna

latencí internetového připojení. Nejčastěji se lze setkat s API a NTP servery.

### 5.1.1 API

Application Programming Interface (API) je rozhraní, které slouží pro předávání dat

mezi softwarovými aplikacemi. API může být použito k získání času z webové služby.

Například, World Time API slouží pro získání aktuálního času a poskytuje čas pro

konkrétní časová pásma ve tvaru Unixového času, nebo ve tvaru podle ISO8601.

Data jsou poskytována ve formátu prostého textu nebo jako JSON [25].

### 5.1.2 NTP

Network Time Protokol (NTP) servery jsou nejběžněji využívaným zdrojem pro

synchronizaci času přes internet. NTP je navržený tak, aby na něj neměla velký

vliv proměnlivá latence internetového připojení. K posílání informací slouží v NTP

serverech takzvané packety, které obsahují vždy menší množství dat. K omezení

vlivu latence internetového připojení jsou využívány sofistikované algoritmy, díky

nimž se přesnost synchronizace času pohybuje do 10 ms [23]. Příkladem NTP serveru

je Google Public NTP a NTP Pool [16].

## 5.2 Rádiový signál

Existují vysílače, které vysílají informace o čase pomocí radiových vln. Tyto signály

jsou obvykle velmi přesné, ale jejich příjem může být ovlivněn atmosférickými pod-

mínkami nebo rušením signálu. Příkladem těchto vysílačů jsou WWVB v USA, MSF ve Velké Británii a DCF77 v Německu. V minulosti existoval v ČR vysílač

OMA 50, který od roku 1995 není v provozu [21].

ČVUT v Praze | 5. TEORIE - MOŽNOSTI URČENÍ ČASU

### 5.2.1 DCF77

Vzhledem k omezenému dosahu rádiového signálu má na území ČR smysl uvažovat

o využití pouze signálu DCF77. Vysílač DCF77 vysílá čas vycházející z měření

cesiových atomových hodin Fyzikálně-technického institutu v Braunschweigu (PTB).

Tento vysílač vysílá dlouhovlnné rádiové vlny na kmitočtu 77,5 kHz. Výkon vysílače

je 50kW. Vysílač vysílá nepřetržitě od roku 1970 a odstaven je jen velmi výjimečně

z důvodů údržby. Teoretický dosah vysílače je uváděn až 2000 km, což však platí jen

za ideálních podmínek. Dosah vysílače i za méně příznivých podmínek je udáván 1100 km, což stále pokrývá celé území České republiky.[18] Název DCF77 vychází

z označení:

D – Deutschland (Německo)

C – Označení pásma dlouhých vln

F – Frankfurtský region

77 – Vysílací frekvence (77,5 kHz)

Časový kód signálu DCF77: Každou minutu vysílač vysílá informaci o minutě,

hodině, dni v týdnu, měsíci a roku pomocí amplitudové modulace. Tato informace

platí vždy pro následující minutu [12]. Dále je signál modulován pomocí pseudo-

náhodné fázové modulace, která slouží pro přenos pseudonáhodného šumu, který lze

využít pro přesnější určení času [21] [5].

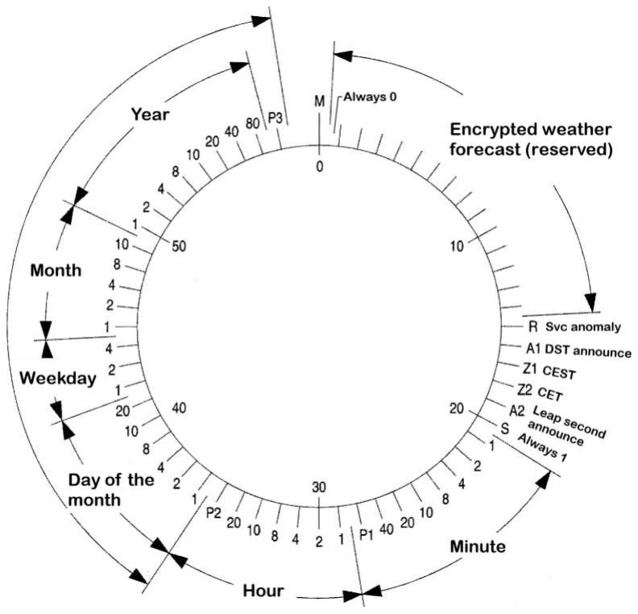
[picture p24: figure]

Obrázek 5.1: Schéma signálu DCF 77 [12]

ČVUT v Praze | 5. TEORIE - MOŽNOSTI URČENÍ ČASU

Rušení signálu DCF77: Signál DCF77 se šíří ohybem po povrchu Země a

odrazem od ionosféry. Odrazy od ionosféry jsou přes den slabé, a proto je signál

během dne slabší. Signál DCF77 je rušen z několika zdrojů. Jedním zdrojem rušení

je atmosférický šum způsobený činností ionosféry a může dosahovat velikosti až

80 dB. Atmosférický šum je proměnlivý. Dále může být signál rušen průmyslovou

činností, například vlivem vysokonapěťového vedení [2] [22].

## 5.3 GNSS

Pro určení času lze využít globální navigační satelitní systémy (GNSS) jako je GPS,

GLONASS nebo Galileo. Družice těchto systémů vysílají časové informace spolu

s navigačními daty. Na satelitech těchto systémů jsou obvykle cesiové atomové

hodiny a záložní rubidiové atomové hodiny, které poskytují velmi přesný zdroj času.

Signál z těchto družic jsou schopny přijímat GNSS přijímače. Signál je ovšem

z důvodu tranzitní doby opožděn. Pokud přijímač přijímá v jednu epochu signál

alespoň ze čtyř družic, je schopen spočítat opravu hodin přijímače a tím získat svůj

přesný čas. Tento čas poskytují GNSS přijímače prostřednictvím NMEA zprávy.

Je potřeba si uvědomit, že například GPS družice pracují v GPS čase, který je

odlišný od času UTC. Součástí NMEA zprávy $GNZDA je však už čas přepočítaný

do UTC [24]. Tato metoda poskytuje velmi přesný čas a je dostupná kdekoliv

na Zemi, ale vyžaduje přímý výhled na oblohu pro příjem signálů od alespoň čtyř

satelitů, aby bylo možné spočítat i opravu hodin přijímače.

ČVUT v Praze | 6. VÝVOJ ZAŘÍZENÍ - KOMPONENTY

## 6 Vývoj zařízení - Komponenty

## 6.1 Vývojová deska

Vývojová deska je elektronické zařízení skládající se z desky plošných spojů, mikro-

kontroléru a k němu připojených dalších periférií. Mikrokontrolér je malý počítač na

jednom integrovaném obvodu, který může obsahovat jedno nebo více jader procesoru,

paměť pro uložení programu, operační paměť a programovatelné vstupy/výstupy.

Mikrokontrolér neobsahuje operační systém a řídící program na něj bývá nahraný

pomocí integrovaného vývojového prostředí (IDE, z anglického Integrated Develop-

ment Environment). Mikrokontrolér ovládá k němu připojené periférie a další

součástky připojnené k vývojové desce. Připojením součástek k vývojové desce

lze vytvořit nové elektronické zařízení [17].

### 6.1.1 Arduino Uno

Jako vývojová deska bylo zvoleno Arduino UNO, a to z důvodu jeho poměrně nízké

ceny, velkého množství dostupné dokumentace a kompatibilních součástek. Tato

vývojová deska, na které je nahraný řídící program, ovládá všechny ostatní použité

komponenty. Nejběžněji se lze setkat s Arduinem UNO R3, které je založené na

mikrokontroléru ATmega328P od firmy Atmel. Z důvodu malé kapacity paměti

Arduina UNO R3 bylo využito novější Arduino UNO R4. To je založeno na mikrokon-

troléru Renesas RA4M1, jenž obsahuje procesor ARM Cortex-M4F. Arduino UNO

R4 se vyrábí ve verzích Minima a WiFi. Verze WiFi je zaměřena na IoT aplikace

a obsahuje navíc mikrokontrolér ESP32-S3 od firmy Espressif s integrovaným WiFi

a bluetooth low energy (BLE) modulem. Toho lze využít pro připojení k NTP

serveru, nebo odesílání dat [3]. Arduino UNO lze pořídit i v podobě „klonu“,

který vyrábí neoficiální výrobce. Tyto „kolny“ bývají obvykle cenově dostupnější

než originální desky.

Tab. 6.1: Porovnání kapacity paměti Arduina UNO R3 a R4 [3]

Typ paměti | R3 | R4
flash | 32 KB | 256 kB
SRAM | 2 KB | 32 kB
EEPROM | 1 KB | 8 kB

ČVUT v Praze | 6. VÝVOJ ZAŘÍZENÍ - KOMPONENTY


Obrázek 6.1: Arduino UNO R4 ve verzi WiFi [15]

### 6.1.2 Arduino Mega

Vzhledem k nedostatečné kapacitě paměti Arduina UNO R3 se rovněž nabízí možnost

využití Arduina Mega. To je založené na mikrokontroléru ATmega2560. Oproti

Arduinu UNO R3 disponuje větší kapacitou paměti, a oproti oběma verzím Arduina

UNO i větším množstvím pinů. Nevýhodou Arduina Mega je větší fyzická velikost

a bylo tedy využito jen pro testování během vývoje zařízení [3].

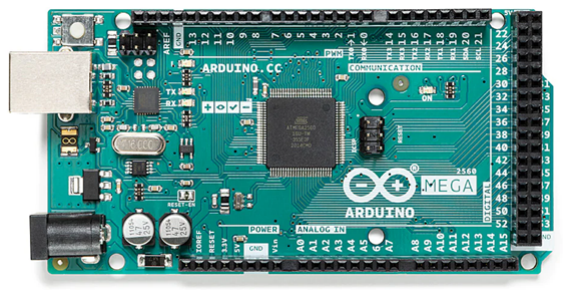
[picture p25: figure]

Obrázek 6.2: Arduino Mega [3]

## 6.2 Přijímač časového signálu

Existuje několik způsobů, jak synchronizovat čas Arduina s koordinovaným časem.

Jedním z nich je synchronizace času při nahrávání programu do Arduina. Tato

metoda však vyžaduje opakované nahrání programu před každým měřením, aby se

interní čas aktualizoval. Tato metoda neumožňuje průběžnou synchronizaci a její

přesnost je závislá na přesnosti vnitřního času zařízení z nějž je program nahráván.

Vhodnějšími metodami jsou synchronizace přes internet, využití přijímače DCF77,

který přijímá koordinovaný čas pomocí rádiového signálu, nebo využití času z NMEA

zprávy z GNSS přijímače. Tyto metody poskytují přesnější a průběžnou synchro-

nizaci času bez nutnosti opakovaného nahrávání programu.

ČVUT v Praze | 6. VÝVOJ ZAŘÍZENÍ - KOMPONENTY

### 6.2.1 Přijímač DCF77

Pro příjem signálu DCF77 je vhodné zvolit anténu, která přijímá především mag-

netickou složku elektromagnetické vlny, protože elektrická složka vlny je citlivá na

výšku antény nad povrchem a bývá výrazně více rušena okolním signálem z jiných

elektronických zařízení než magnetická složka. Pro příjem magnetické složky signálu

lze využít rámovou anténu, která ale mívá poměrně velké rozměry. Obvykle se

používá anténa o průměru 0,5m. Z důvodu kompaktnosti celého zařízení byla

zvolena feritová anténa. Pokud by signál z feritové antény nebyl dostatečně silný, je

možné pro jeho zesílení přímo na feritovou anténu připojit rámovou anténu s větším

průměrem.

Využitý přijímač se skládá z feritového jádra, kolem kterého je vinuta cívka

a demodulátoru, který slouží k oddělení modulačního signálu od nosného signálu.

Anténa má dvě maxima a dvě minima. Pro příjem maximální intenzity signálu, je

vhodné ji umístit kolmo na směr k vysílači. Pokud by docházelo k rušení signálu

z jednoho směru, lze to vyřešit tím, že bude anténa natočena minimem ke zdroji

rušení [12] [2].


Obrázek 6.3: Přijímač radiového signálu DCF77 [7]

### 6.2.2 Přijímač GNSS

Pro příjem informací o aktuálním čase lze využít i GNSS přijímač. Astrochrograf

je navržený tak, že má vyvedený pin D0 Arduina, aby k němu mohl být připojen

libovolný GNSS přijímač. Pin D0 na Arduinu Uno funguje jako RX pin pro sériovou

komunikaci pomocí UART. GNSS přijímač musí být k RX pinu Arduina připojen

pomocí svého TX pinu. Přijímač musí poskytovat NMEA zprávu $GNZDA, která

obsahuje informace o aktuálním čase a zprávu $GNGGA, která poskytuje informaci

o poloze přijímače. Pro vývoj zařízení byl použit aktuálně dostupný GNSS přijímač

Ublox NEO-M8T, který je schopen přijímat data ze satelitů GPS, GLONASS,

Galileo, BeiDou, QZSS a SBAS. Tento přijímač umožňuje i RTK měření. Nevýhodou

ČVUT v Praze | 6. VÝVOJ ZAŘÍZENÍ - KOMPONENTY

přijímače je poměrně vysoká cena. Pro určování času lze využít i přijímače s omeze-

nější funkcionalitou než Ublox NEO-M8T. Například levnější přijímač Ublox NEO-

M7M, který přijímá data ze satelitů GPS, GLONASS, Galileo a QZSS. Tento přijí-

mač neumožňuje měření RTK, což není pro určování času potřeba.


Obrázek 6.4: GNSS přijímač Ublox NEO-M8T [9]

Obrázek 6.5: GNSS přijímač Ublox NEO 7M [7]

## 6.3 Čtečka Micro SD karet

Protože Arduino samo o sobě nemá paměť pro ukládání dat, tak byla pro ukládání měřených dat využita Micro SD karta. Čtečka Micro SD karet umožňuje zapisovat

měřená data na Micro SD kartu a popřípadě je z ní i číst. Pro komunikaci s čtečkou

Micro SD karet je využíváno standardní SPI rozhraní [6].


Obrázek 6.6: Čtečka Micro SD karet [7]

ČVUT v Praze | 6. VÝVOJ ZAŘÍZENÍ - KOMPONENTY

## 6.4 Tlačítko

Tlačítko je jednoduchý komponent, sloužící pro detekci svého stisknutí. Stisknutí

tlačítka slouží k provedení záznamu času na Micro SD kartu. Místo samostatného

tlačítka byl využit modul rotačního enkodéru, který umí detekovat své stisknutí a při

pootočení osou poskytuje informaci o směru rotace. Výhodou rotačního enkodéru

oproti tlačítku je, že poskytuje další informace, které lze využít k ovládání zařízení.

Výhodou tohoto konkrétního modulu je to, že jej lze snadno upevnit ke krabičce

s výsledným zařízením.


Obrázek 6.7: Rotační enkodér [7]

## 6.5 OLED displej

K informování měřiče o průběhu měření slouží mimo jiné displej. Na něj se zobrazuje

informace o stavu vložení Micro SD karty, o stavu synchronizace času, aktuální

čas a poslední uložený čas. Jako displej byl zvolen OLED displej především kvůli

nízké ceně, dobré čitelnosti, nízké spotřebě energie a absenci potřeby dodatečného

podsvícení, jelikož světélkují samotné pixely. Displej je monochromatický a jeho rozlišení je 128×64 bodů. K řízení displeje je využívána komunikace pomocí I²C

sběrnice [6].


Obrázek 6.8: OLED displej [7]

ČVUT v Praze | 6. VÝVOJ ZAŘÍZENÍ - KOMPONENTY

## 6.6 Hlasový modul

O průběhu měření je měřič informován kromě displeje i pomocí reproduktoru, tak

aby nemusel při měření sledovat displej. Měřiče o průběhu měření informují slovní pokyny „Čas byl synchronizován“ a „Měření času bylo uloženo“, které byly vytvořeny

pomocí převodu textu na mp3 soubor. Jelikož Arduino neumožňuje ukládat žádné

soubory do své vnitřní paměti, tak jsou mp3 soubory se zvukovými informacemi

nahrány na Micro SD kartu. Soubory jsou z Micro SD karty čteny pomocí hlasového

modulu a přehrávány pomocí reproduktoru, který je k hlasovému modulu připojen.

Hlasový modul s Arduinem komunikuje prostřednictvím sériové komunikace [6].


Obrázek 6.9: Hlasový modul [15]


Obrázek 6.10: Reproduktor [3]

## 6.7 RGB LED

Kromě displeje a zvukového signálu je měřič informován o průběhu měření také

prostřednictvím elektroluminiscenční diody (LED, z anglického Light Emitting Diode).

Jako elektroluminiscenční dioda (LED) je využit modul RGB LED, který se skládá

ze tří samostatných LED (červená, zelená, modrá). Tyto LED mají společnou

katodu, ale samostatné anody. K ovládání jasu jednotlivých barev slouží pulzně

šířková modulace (PWM). Jednotlivé anody lze nezávisle na sobě připojit na piny s

ČVUT v Praze | 6. VÝVOJ ZAŘÍZENÍ - KOMPONENTY

podporou PWM, což umožňuje ovládat samostatně jednotlivé barvy. Další výhodou

tohoto modulu je, že již má integrované ochranné rezistory. Během měření může

LED signalizovat různé stavy: Nejprve bliká červeně v každý okamžik, kdy při-

jme signál DCF77 (v ideálním případě je to jednou za sekundu). Ve chvíli, kdy je

čas poprvé synchronizován se změní červené blikání na zelené, což informuje měřiče

o úspěšné synchronizaci času. Dále LED bliká modře v každý okamžik, kdy měřič

provede měření [6].

Obrázek 6.11: Modul s RGB LED [7]

## 6.8 Převodník TTL na RS232

Aby byl spolu s časovými údaji uložen na Micro SD kartu vodorovný směr (a pří-

padně i zenitový úhel) měřený totální stanicí, je potřeba zajistit komunikaci Arduina

s totální stanicí. K tomu lze využít sériovou komunikaci pomocí UART. Konkrétně

byla využita totální stanice Leica TC1700. Ta využívá pro sériovou komunikaci

standart RS-232 a lze k ní tedy připojit sériový kabel RS-232 [1]. Standart RS-232

využívá pro datové signály +3 V až +25 V jako logickou nulu a -3 V až -25 V jako

logickou jedničku. Arduino UNO využívá protokol TTL, který považuje hodnoty

okolo 0 V za logickou nulu a hodnoty v okolí +5 V za logickou jedničku. Aby mohl

být kabel RS-232 připojen i k Arduinu, je potřeba využít převodník TTL na RS-232 [4].


Obrázek 6.12: Převodník TTL na RS232 [15]

ČVUT v Praze | 6. VÝVOJ ZAŘÍZENÍ - KOMPONENTY

## 6.9 Bluetooth modul

Pro export dat z Micro SD karty, aniž by bylo potřeba ji vyjmout, lze využít

Bluetooth modul. Konkrétně byl pro tento účel využit modul HC-05. Tento modul

využívá sériovou komunikaci pomocí UART a podporuje Bluetooth ve verzi 2.0.

Pomocí Bluetooth modulu lze přenášet binární data. Modul je připojen pomocí

pinů GND, VCC, RX a TX. Kromě toho obsahuje piny STATE a EN, které slouží

pro konfiguraci modulu. Pin EN na modulu HC-05 umožňuje přepnutí modulu do

režimu „enabled“. V tomto režimu lze pomocí AT příkazů nastavit jméno, heslo,

popřípadě i baud rate a další parametry modulu [6].


Obrázek 6.13: Bluetooth modul HC-05 [7]

## 6.10 Deska plošných spojů

Během vývoje zařízení byly všechny komponenty spojovány pomocí kabelů. Nevýho-

dou propojení pomocí kabelů je velká prostorová náročnost a celková nepřehlednost.

Z toho důvodu bývá obvykle propojení různých komponentů realizováno pomocí

desky plošných spojů. Pro snadné propojení všech využitých komponentů byla tedy

vyhotovena deska plošných spojů (DPS).


Obrázek 6.14: Výsledná DPS

ČVUT v Praze | 6. VÝVOJ ZAŘÍZENÍ - KOMPONENTY

## 6.11 Cena komponentů

Ceny jednotlivých komponentů se mění v čase a mohou se lišit v závislosti na místě

(obchodě), kde byly zakoupeny. Cena výsledného zařízení závisí na tom, zda byly

použity všechny komponenty pro plnou funkcionalitu, nebo zda byly některé funkce

vynechány. Pokud se zařízení vyrábí s omezenou funkcionalitou, lze využít levnější

Arduino UNO R3. Náklady na výsledné zařízení lze také snížit použitím „klonů“

místo originálního Arduina. Níže uvedená tabulka obsahuje komponenty potřebné

pro zařízení s plnou funkcionalitou a uvádí ceny, za které byly tyto komponenty

zakoupeny.

Tab. 6.2: Cena použitých součástek

Název | Cena | Odkaz na obchod
Arduino UNO R4 WiFi | 768 Kč | laskakit.cz (https://www.laskakit.cz/arduino-uno-r4-wifi--original/)
Přijímač DCF77 | 5,60 e/140 Kč | pollin.de (https://www.pollin.de/p/dcf-empfangsmodul-dcf1-810054)
Přijímač GNSS | 339 Kč | dratek.cz (https://dratek.cz/arduino/1733-gps-satelitni-urceni-polohy-neo-7m-modul.html?)
Čtečka Micro SD karet | 24 Kč | dratek.cz (https://dratek.cz/arduino/993-ctecka-microsd-karet.html?)
Tlačítko (rotační enkodér) | 38 Kč | dratek.cz (https://dratek.cz/arduino/837-rotacni-enkoder.html?)
OLED displej | 167 Kč | dratek.cz (https://dratek.cz/arduino/3181-iic-i2c-oled-1-3-displej-128x64-bily.html?)
Hlasový modul | 66 Kč | dratek.cz (https://dratek.cz/arduino/4857-hlasovy-modul-s-integrovanym-mp3-prehravacem-dfplayer.html?)
Reproduktor | 19 Kč | dratek.cz (https://dratek.cz/arduino/1175-reproduktor-1w-8ohm.html?)
RGB LED | 15 Kč | dratek.cz (https://dratek.cz/arduino/837-rotacni-enkoder.html)
Bluetooth modul HC-05 | 117 Kč | dratek.cz (https://dratek.cz/arduino/1005-bluetooth-modul-hc-05.html?)
Deska plošných spojů | 9,34 $/216 Kč | allpcb.com
Celkem | 1909 Kč | -

ČVUT v Praze | 7. VÝVOJ ZAŘÍZENÍ - KONSTRUKCE

## 7 Vývoj zařízení - Konstrukce

V této kapitole bude vysvětleno zapojení jednotlivých komponentů, které byly pop-

sány v předchozí kapitole. Dále bude popsán návrh desky plošných spojů (DPS),

jenž byl vyhotoven v softwaru Autodesk EAGLE. Bude vysvětleno, jak byla DPS os-

azena jednotlivými komponenty. Nakonec bude popsáno, jak byl vytvořen prototyp

výsledného zařízení.

## 7.1 Schéma zapojení

Arduino Uno disponuje různými typy pinů, které lze využít k různým účelům. Při

zapojování jednotlivých komponentů je důležité zohlednit specifickou funkcionalitu

jednotlivých pinů. Nelze totiž připojit součástky na libovolné piny, ale je nutné je

zapojit na piny, které disponují potřebnou funkcionalitou. Jeden pin může mít více

funkcí najednou. Piny Arduina mohou sloužit například jako digitální vstupy/výs-

tupy, analogové vstupy, PWM (analogové výstupy s modulací šířky pulzu), RX a TX

pro sériovou komunikaci, SDA a SCL pro I²C komunikaci nebo jako MISO, MOSI,

CLK, a CS pro SPI komunikaci [3].


Obrázek 7.1: Výstupy pinů pro Arduino UNO R4 [3]

ČVUT v Praze | 7. VÝVOJ ZAŘÍZENÍ - KONSTRUKCE

Schéma zapojení bylo vyhotoveno v softwaru Autodesk Eagle. nejprve bylo

vyhotoveno schéma zapojení pro Arduino UNO R3 podle toho, jak byly jednotlivé

komponenty zapojeny v rámci testování jejich funkčnosti. Toto schéma zapojení

sloužilo jako podklad pro tvorbu desky plošných spojů (DPS). Arduino UNO

R3 však nedisponuje dostatečnou kapacitou paměti k tomu, aby mohlo obsluhovat

všechny plánované komponenty. Pro finální zařízení, které bude disponovat plnou

funkcionalitou, bylo proto zvoleno Arduino UNO R4. Vzhledem k tomu, že Arduino

UNO R4 má lehce odlišné rozvržení pinů oproti verzi R3, bylo nutné vyhotovit

nové schéma zapojení a podle něj i novou DPS. Nové schéma zapojení se povedlo

navrhnout tak, že nová DPS je kompatibilní s oběma verzemi Arduina UNO (R3 i

R4).


Obrázek 7.2: Schéma zapojení komponentů pro Arduino Uno

Přijímač časového signálu DCF77

Přijímač poskytuje digitální signál, který odpovídá dekódovaným bitům časového

kódu. Tento digitální signál je pak k dispozici na výstupním pinu přijímače (obvykle

označeném jako TCO nebo DATA), který je potřeba připojit k digitálnímu vstupu

Arduina.

ČVUT v Praze | 7. VÝVOJ ZAŘÍZENÍ - KONSTRUKCE
- VCC → 3.3V
- GND → GND
- PON → GND
- TCO → D2

GNSS přijímač u-blox NEO

Komunikace s Arduinem probíhá pomocí sériové komunikace TTL přes rozhraní

UART. Je nutné připojit přijímač k pinům Arduina, které tuto komunikaci umožňují.

- VCC → 5V
- GND → GND
- TX → D0

Tlačítko (rotační enkodér)

Rotační enkodér poskytuje digitální signály, které odpovídají jeho otáčení a stisknutí

tlačítka. Tyto signály lze číst pomocí digitálních pinů Arduina, které mohou sloužit

jako digitální vstupy.

- VCC → GND
- GND → 5V
- CLK → D6
- DT → D5
- SW → D4

OLED displej

OLED displej využívá i²C komunikaci a je tedy potřeba jej připojit k pinům, které

ji podporují.

- VCC → 5V
- GND → GND
- SDA → A4
- SCL → A5

Hlasový modul

Hlasový modul využívá sériovou komunikaci. Kvůli nedostatku sériových pinů na

Arduinu UNO je použita knihovna SoftwareSerial, která umožňuje emulovat sériovou

komunikaci pomocí některých pinů, které nejsou primárně určeny pro sériovou komu-

nikaci.

- VCC → 5V
- GND → GND
- TX → RX
- RX → TX
- SPK1 → reproduktor (+)
- SPK2 → reproduktor (-)

ČVUT v Praze | 7. VÝVOJ ZAŘÍZENÍ - KONSTRUKCE

RGB LED

Pro ovládání jasu světla jednotlivých barev, lze využít piny s podporou pulzně

šířkové modulace (PWM), označené symboly „∼“.

- R → ∼D9
- G → ∼D10
- B → ∼D11
- GND → GND

Bluetooth modul HC-05

Bluetooth modul HC-05 využívá sériovou komunikaci, ale Arduino UNO nemá dosta-

tečný počet sériových pinů. Proto jsou využity piny, které umožňují softwarovou

emulaci sériové komunikace obdobně jako u hlasového modulu.

- VCC → 5V
- GND → GND
- TX → RX
- RX → TX

## 7.2 Návrh DPS

Návrh DPS byl vyhotoven v softwaru Autodesk Eagle. Propojení mezi kompo-

nenty vycházeli z již vytvořeného schématu zapojení. Bylo navrženo rozmístění

komponentů na DPS. Pomocí funkce „Autorouter“ byly automaticky vygenerovány

optimální trasy spojů. Dále byl vyhotoven „gerberfile“. Ten slouží jako podklad pro

výrobu. Výroba DPS může být provedena amatérsky. K tomu je potřeba speciální

vybavení a určitá zručnost zhotovitele. Vzhledem k náročnosti výroby kvalitní DPS

byla zvolena možnost nechat ji vyrobit profesionální firmou, na základě předloženého

„gerberfile“. Tím je zajištěno, že je DPS kvalitní a spolehlivá.

ČVUT v Praze | 7. VÝVOJ ZAŘÍZENÍ - KONSTRUKCE


Obrázek 7.3: Ukázka návrh DPS v softwaru Autodesk Eagle

## 7.3 Sestavení výsledného zařízení

Deska plošných spojů byla navržena tak, aby společně s komponenty k ní připo-

jenými bylo výsledné zařízení co nejkompaktnější. K desce byly připájeny další

komponenty anebo patice a hřebínky, do kterých budou komponenty zapojeny, aby

bylo možné některé komponenty v případě potřeby odpojit nebo vyměnit. Některé

součástky, jako tlačítka a displej byly připojeny k desce pomocí kabelů. To umožňuje

snadné umístění těchto součástek na vnější část krabičky. Kabely lze snadno odpo-

jit pro případ, že by bylo zařízení potřeba rozebrat například z důvodu výměny

nějakého komponentu. Napájení zařízení je řešeno pomocí 9 V baterie, která je

propojená s piny VIN a GND Arduina.


Obrázek 7.4: Ukázka osazené DPS pro prototyp zařízení

ČVUT v Praze | 7. VÝVOJ ZAŘÍZENÍ - KONSTRUKCE

Nakonec byly všechny komponenty integrovány do krabičky, která slouží jako tělo

zařízení (astrochronografu). Tělo prototypu zařízení založeného na Arduinu UNO

R3 bylo provizorně vytvořeno ze svačinové krabičky, která svými rozměry poměrně

dobře vyhovuje potřebám zařízení. Svačinová krabička byla jako tělo zařízení využita

z důvodu toho, že je snadno dostupná a není potřeba ji speciálně vyrábět, zároveň

je její výhodou vodotěsnost a průhlednost. V budoucnu je v plánu vytvořit vlastní

tělo zařízení, které bude kompaktnější a bude přesně vyhovovat účelům zařízení. Do

krabičky byly vyvrtány a vyřezány díry pro displej, konektory a tlačítka, které jsou

utěsněny silikonem, aby byla zachována vodotěsnost celého zařízení.


Obrázek 7.5: Prototyp zařízení

ČVUT v Praze | 8. VÝVOJ ZAŘÍZENÍ - ŘÍDÍCÍ SOFTWARE

## 8 Vývoj zařízení - Řídící software

## 8.1 Programovací jazyk

Nejběžněji bývá pro tvorbu řídícího programu pro Arduino využívána varianta jazyka

C++, která využívá struktury převzaté z jazyka Wiring. Alternativně lze použít

jazyky jako MicroPython, JavaScript a další. Ve Wiringu se namísto typické funkce

main pro C++ používají funkce setup pro prvotní inicializaci při spuštění programu

a funkce loop pro nekonečnou smyčku, která program nepřetržitě vykonává [3].

## 8.2 Vývojové prostředí

Pro tvorbu a nahrání řídicího programu do mikrokontroléru se využívá integrované

vývojové prostředí (IDE). Mikrokontroléry, na rozdíl od jednodeskových mikropočí-

tačů, nejsou vybaveny operačním systémem. Nelze tedy tvořit kód přímo na mikro-

kontroléru, je potřeba jej vytvořit na počítači, zkompilovat a následně nahrát jako

binární soubor do mikrokontroléru. Pro tvorbu řídicího programu bylo konkrétně

využito Arduino IDE. To nabízí kromě možnosti psaní, kompilování a nahrávání

kódu i správu knihoven a čtení dat z Arduina pro ladění kódu. Kromě vývojového

prostředí Arduino IDE bylo využíváno prostředí VS Code od společnosti Microsoft,

které umožňuje verzování pomocí Gitu a sdílení kódu na platformě GitHub.


Obrázek 8.1: Arduino IDE

ČVUT v Praze | 8. VÝVOJ ZAŘÍZENÍ - ŘÍDÍCÍ SOFTWARE

## 8.3 Použité knihovny

Pro práci s některými komponenty byly využity již existující knihovny, které us-

nadňují využití jejich funkcionality. Knihovna SoftwareSerial.h (https://www.arduino.cc/en/Reference/SoftwareSerial) byla využita pro

emulaci pinů sloužících pro sériovou komunikaci, protože Arduino UNO obsahuje

pouze jeden TX a jeden RX pin, určený pro sériovou komunikaci. Pro práci s údaji

o čase byla využita knihovna TimeLib.h. (https://www.pjrc.com/teensy/td_libs_Time.html) Pro synchronizaci času prostřednictvím

signálu z DCF77 přijímače byla využita knihovna DCF77.h. (https://github.com/thijse/Arduino-DCF77) Tato knihovna ob-

sahuje funkce pro dekódování signálu DCF77. Pro přístup k NTP serveru byly

využity knihovny WiFiS3.h (https://github.com/esp8266/Arduino/tree/master/libraries/ESP8266WiFi) a WiFiUdp.h. (https://www.arduino.cc/en/Reference/WiFi) Ty slouží pro připojení k WiFi a přijí-

maní a odesílání paketů, které využívá NTP server. Pro práci s Micro SD kartou

byla využita knihovna SD.h. (https://www.arduino.cc/en/Reference/SD) Tato knihovna obsahuje funkce pro zapisování dat na

Micro SD kartu a čtení dat z ní. Pro práci s OLED displejem byla nejprve využívána

knihovna U8glib.h, (https://github.com/olikraus/u8glib) která ale není kompatibilní s mikrokontroléry Renesas, a tak

byla využita knihovna U8g2lib.h. (https://github.com/olikraus/u8g2) Pro práci s hlasovým modulem byla využita

knihovna DFRobotDFPlayerMini.h. (https://github.com/DFRobot/DFRobotDFPlayerMini)

## 8.4 Členění kódu

Řídící program byl rozdělen z důvodu přehlednosti na hlavní program (*.ino), který

sdružuje další části kódu ve formě hlavičkových (*.h) a implementačních souborů

(*.cpp). Během tvorby řídícího programu byly využity již existující knihovny a při

tvorbě kódu bylo vycházeno ze vzorových kódů, které k nim byly přiložené v doku-

mentaci. Nicméně některé části kódu byly vytvořeny zcela nově. Například bylo

potřeba zajistit, aby stisknutí tlačítka bylo považováno za stisknutí pouze v prvním

průchodu funkcí loop, a v dalších průchodech již nebylo tlačítko považováno za

stisknuté tak, aby bylo provedeno při každém stisku jen jedno měření a měření bylo

přehledné a jednoznačné. Kód pro příjem dat z GNSS přijímače byl vytvořen také

kompletně od začátku. V tomto kódu je načítána pomocí sériové komunikace NMEA

zpráva. Ta je parsována a je z ní zjišťováno, zda byla určena poloha přijímače.

Pokud je určena poloha přijímače lze považovat čas za aktuální. V tom případě je

text s časem převeden na číselné hodnoty a s těmi je dále pracováno. Dalším pří-

kladem je funkce setiny. Jelikož všechny použité přijímače poskytují data po celých

sekundách, tak byla vytvořena funkce setiny, která je spuštěna vždy na začátku celé

ČVUT v Praze | 8. VÝVOJ ZAŘÍZENÍ - ŘÍDÍCÍ SOFTWARE

sekundy a rozděluje ji na setiny sekund. Při každé nové sekundě jsou setiny sekund

vynulovány. Od začátku byla také vyhotovena část kódu pro komunikaci s totální

stanicí a další části kódu.

Inicializace zařízení; Kontrola připojení micro SD karty; Pokus o aktualizaci času; Zobrazení aktuálního stavu na displeji; Kontrola; stisknutí; tlačítka; Uložení aktuálního času; Odeslání požadavku TS; Uložení dat z TS; Signalizace; požadavku; Bluetooth; Otevření souboru s měřenými daty; Odeslání dat přes Bluetooth; ano

Obrázek 8.2: Zjednodušené schéma řídícího programu

ČVUT v Praze | 9. TESTOVÁNÍ

## 9 Testování

## 9.1 Testování během vývoje

Funkčnost jednotlivých komponentů a byla testována v průběhu vývoje řídicího

programu. Nejprve byla testována funkčnost každého komponentu samostatně. Poté

byly komponenty postupně začleňovány do celkového zařízení a byla testována jejich

vzájemná spolupráce a funkčnost jako celek.

## 9.2 Testování výsledného zařízení

Po dokončení prototypu zařízení byla ověřena jeho funkčnost. Protože prototyp je

založen na Arduinu UNO R3, má pouze omezenou funkcionalitu. Prototyp umí

synchronizovat svůj vnitřní čas buď pomocí DCF77 nebo GNSS přijímače. Tento

čas umí po stisknutí tlačítka ukládat na Micro SD kartu. Dále umí informovat měřiče

o průběhu měření prostřednictvím displeje, zvuku a diody. Všechny tyto zmíněné

funkce byly otestovány a jsou plně funkční.

## 9.3 Testování DCF77

U přijímače signálu DCF77 bylo testováno, jak rychle je schopné výsledné zařízení

synchronizovat svůj vnitřní čas a jak často bývá čas synchronizován po první syn-

chronizaci.

Prvotní synchronizace

Bylo zjištěno, že prvotní synchronizace bývá za vhodných podmínek provedena mezi

druhou až třetí minutou od spuštění.

Průběžná synchronizace

Jak často zařízení synchronizuje svůj vnitřní čas, bylo testováno tím, že bylo zařízení

spuštěno po dobu jednoho dne u okna orientovaného na západ. Na Micro SD kartě se

vytváří soubor TEST.TXT, který obsahuje informace o tom, kdy došlo k aktualizaci

času pomocí DCF77. Tato data byla následně zpracována v softwaru R, kde byl

vykreslen histogram znázorňující sloupce pro jednotlivé hodiny, přičemž velikost

sloupce značí, kolik synchronizací bylo během této hodiny provedeno.

ČVUT v Praze | 9. TESTOVÁNÍ


Obrázek 9.1: Histogram počtu synchronizací

## 9.4 Testování GNSS modulu

Prvotní synchronizace

Bylo zjištěno, že prvotní synchronizace bývá za vhodných podmínek (v exteriéru

nebo u okna) provedena během několika sekund.

Průběžná synchronizace

Po prvotní synchronizaci získává modul čas nepřetržitě, pokud nedojde k přerušení

příjmu signálu (stínění antény).

## 9.5 Testování NTP serveru

Čas z NTP serveru bývá získán prakticky okamžitě a pokud nedojde k přerušení

internetového připojení získává zařízení čas nepřetržitě.

## 9.6 Porovnání získaných časů

Pro porovnání časů získaných z NTP serveru, přijímače signálu DCF77 a GNSS

přijímače byl vytvořen testovací kód pro Arduino UNO R4. Tento kód synchronizuje

čas pomocí všech tří zmíněných metod a provádí záznam času každou minutu od

spuštění Arduina.

ČVUT v Praze | 9. TESTOVÁNÍ

Tab. 9.1: Porovnání časů z různých zdrojů

Arduino čas | NTP | DCF77 | GNSS
00:04:00.00 | 10:27:12.52 | 10:27:12.55 | 10:27:12.68
00:05:00.00 | 10:28:12.50 | 10:28:12.55 | 10:28:12.65
00:06:00.00 | 10:29:12.49 | 10:29:12.55 | 10:29:12.64
00:07:00.00 | 10:30:12.49 | 10:30:12.54 | 10:30:12.69
00:08:00.00 | 10:31:12.48 | 10:31:12.54 | 10:31:12.62

Z měřených dat je vidět, že získané časy se od sebe liší na úrovni setin až desetin

sekundy. Tyto rozdíly mohou být způsobeny tím, že každý zdroj má lehce rozdílnou

přesnost. Nejvíce se liší čas získaný pomocí GNSS přijímače, to může být způsobeno

tím, že zpracování NMEA zprávy není dostatečně rychlé a dochází tedy ke zpoždění

v určení času. Pokud se chyba v určení času pohybuje na úrovni pod jednu desetinu

sekundy, lze očekávat, že chyba výsledného astronomického azimutu Slunce, způsobená určením času, bude mít velikost menší než 5cc

ČVUT v Praze | 10. ZÁVĚR

## 10 Závěr

Cílem této práce bylo vytvořit zařízení pro příjem a záznam koordinovaného času

určené pro účely astronomického měření (Astrochronograf). Toto zařízení má sloužit

jako výuková pomůcka pro měření astronomických azimutů na Slunce v rámci výuky

teoretické geodézie.

Práce začala rešerší, během níž byly dohledány zdroje informací, týkající se témat

spojených s určováním času. Byly také dohledány cizí práce, které se zabývaly

určováním času pro různé účely. Tyto zdroje poskytly informace o tom, jakým

vhodným způsobem při tvorbě zařízení lze postupovat.

V teoretické části byly popsány jednotlivé typy časů a převody mezi nimi. Byl

rozebrán vliv chyby při určování času na přesnost výsledných astronomických azi-

mutů. Nakonec byly zmíněny způsoby, jak lze synchronizovat čas zařízení.

V praktické části byl navržen Astrochronograf. Byla vytvořena DPS k propojení

všech využitých komponentů. Byl vytvořen řídící kód pro jednotlivé části zařízení.

Dále byl vyhotoven prototyp zařízení, který je založen na Arduinu UNO R3. Z dů-

vodu nedostatečné kapacity paměti Arduina UNO R3 má tento prototyp pouze

omezenou funkcionalitu. Nicméně umožňuje synchronizaci času prostřednictvím

rádiového přijímače DCF77 nebo prostřednictvím GNSS přijímače. Zařízení infor-

muje měřiče o průběhu měření prostřednictvím displeje, LED a zvukových pokynů

tak, aby při měření nemusel měřič vizuálně sledovat zařízení.

Komponenty a pro ně vyhotovené řídící kódy, které nebyly do prototypu zahrnuty,

byly samostatně testovány, jsou plně funkční a plánuje se jejich implementace do

zařízení. Aby bylo možné tyto komponenty do zařízení implementovat, bude nutné

vyměnit Arduino UNO R3 za Arduino UNO R4. Všechny komponenty a jejich řídící

kódy byly testovány i na Arduinu UNO R4, a tak bude potřeba pouze fyzicky propo-

jit komponenty. K tomu bude sloužit nová deska plošných spojů, která je lehce jinak

uspořádaná než DPS použitá v prototypu. Změna uspořádání komponentů na DPS

byla provedena z důvodu, aby byla DPS kompatibilní s rozvržením pinů jak pro

Arduino UNO R3, tak pro Arduino UNO R4. Tato DPS bohužel dorazila až těsně

před odevzdáním této práce, a tak je prozatím funkční pouze prototyp zařízení.

ČVUT v Praze | 10. ZÁVĚR

Tato práce je včetně zdrojových kódu veřejně dostupná na GitHubu, aby mohla

sloužit jako zdroj informací pro lidi, kteří se budou v budoucnu zabývat podobnými

tématy.

ČVUT v Praze | SEZNAM ZKRATEK

## Seznam zkratek

API | Application Programming Interface
DPS | deska plošných spojů

GNSS globální navigační satelitní systémy

IDE integrované vývojové prostředí - z angl. Integrated Development

Environment

LED elektroluminiscenční dioda - z angl. Light Emitting Diode

NTP Network Time Protokol

PWM pulzně šířková modulace - z angl. Pulse Width Modulation

TAI mezinárodní atomový čas - z fr. Temps Atomique International

UTC univerzální koordinovaný čas - z angl. Coordinated Universal Time / fr.

Temps Universel Coordonné

ČVUT v Praze | | LITERATURA

## Literatura

[1] ADAMS, Mark. GSI ONLINE for Leica TPS and DNA [online]. [cit. 2024-

05-23]. Dostupné z: https://www.engineeringsurveyor.com/software/

tps-dna-online_v114.pdf. (https://www.engineeringsurveyor.com/software/tps-dna-online_v114.pdf)

[2] ANDĚL, Vladimír. Smerování antén přijímačů DCF77 [online]. [cit. 2024-

05-25]. Dostupné z: https://vyvoj.hw.cz/teorie-a-praxe/dokumentace/

smerovani-anten-prijimacu-dcf-77.html. (https://vyvoj.hw.cz/teorie-a-praxe/dokumentace/smerovani-anten-prijimacu-dcf-77.html)

[3] Arduino. Arduino - Home [online]. [cit. 2024-03-26]. Dostupné z: https:

//www.arduino.cc/.

[4] BLOOM, Jim. RS-232 vs. TTL Serial Communication [online]. [cit. 2024-05-

23]. Dostupné z: https://www.sparkfun.com/tutorials/215.

[5] D. Piester, A. Bauch, J. Becker a A. Hoppmann. Generation of UTC(PTB) as

a fountain-clock based time scale [online]. [cit. 2024-03-26]. Dostupné z: https:

//www.ptb.de/cms/fileadmin/internet/fachabteilungen/abteilung_4/

4.4_zeit_und_frequenz/pdf/2012_Piester_ProcPTTI2011.pdf. (https://www.ptb.de/cms/fileadmin/internet/fachabteilungen/abteilung_4/4.4_zeit_und_frequenz/pdf/2012_Piester_ProcPTTI2011.pdf)

[6] Drátek. Začínáme s Arduinem | Návody Drátek [online]. [cit. 2024-05-01]. Do-

stupné z: https://navody.dratek.cz/zaciname-s-arduinem/.

[7] Drátek. Drátek.cz [online]. [cit. 2024-05-01]. Dostupné z: https://dratek.cz/.
[8] FIXEL, Jan. Geodetická astronomie I. a základy kosmické geodézie. Brno:

VUTIUM, 2000. ISBN 80-214-1786-2.

[9] GNSS Store. NEO-M8T TIME and RAW receiver board with SMA (RTK
ready) [online]. [cit. 2024-05-25]. | Dostupné z: | https://gnss.store/

neo-m8t-timing-gnss-modules/284-ELT0332.html. (https://gnss.store/neo-m8t-timing-gnss-modules/284-ELT0332.html)

[10] Google. Google Public NTP [online]. [cit. 2024-04-07]. Dostupné z: https:

//developers.google.com/time.

[11] HAVLÍČEK, David. Elektronické hodiny. [online]. Brno, 2022. Bakalářská práce,

VUT. Dostupné z: https://dspace.cvut.cz/handle/10467/73830.

ČVUT v Praze | LITERATURA
[12] HRUŠKA, Ondřej. Přijímač časové reference DCF77 [online]. [cit. 2024-04-

08]. Dostupné z: https://embedded.fel.cvut.cz/sites/default/files/

kurzy/lpe/radioclock_dcf77/LongWave_Time_Reference_DCF77.pdf. (https://embedded.fel.cvut.cz/sites/default/files/kurzy/lpe/radioclock_dcf77/LongWave_Time_Reference_DCF77.pdf)

[13] KABELÁČ, Josef a KOSTELECKÝ, Jan. Geodetická astronomie 10. Vyd. 2.

Praha: České vysoké učení technické, 2009. ISBN 978-80-01-04322-6.

[14] KOSTELECKÝ, Jakub. Globální polohové souřadnicové systémy. Praha: České

vysoké učení technické, 2019. ISBN 978-80-01-06571-6.

[15] Laskakit. LaskaKit.cz [online]. [cit. 2024-05-01]. Dostupné z: https://www.

laskakit.cz/.

[16] NTP Pool Project. NTP Pool Project [online]. [cit. 2024-04-07]. Dostupné z:

https://www.ntppool.org/en/.

[17] PATRICKS, Mark. | Vývojové desky: | jaké byly, jsou a budou [online].

[cit. 2024-04-30]. Dostupné z: https://www.dps-az.cz/clanky/id:92446/

vyvojove-desky-jake-byly-jsou-a-budou. (https://www.dps-az.cz/clanky/id:92446/vyvojove-desky-jake-byly-jsou-a-budou)

[18] PIESTER, Dirk. | Reach of DCF77 [online]. [cit. 2024-03-26]. | Do-

stupné z: https://www.ptb.de/cms/en/ptb/fachabteilungen/abt4/fb-44/

ag-442/dissemination-of-legal-time/dcf77/reach-of-dcf77.html. (https://www.ptb.de/cms/en/ptb/fachabteilungen/abt4/fb-44/ag-442/dissemination-of-legal-time/dcf77/reach-of-dcf77.html)

[19] PILÍK, Martin. Časový normál pro centralizovanou správu elektronických hodin.

[online]. Praha, 2018. Bakalářská práce, ČVUT. Dostupné z: https://dspace.

cvut.cz/handle/10467/73830. (https://dspace.cvut.cz/handle/10467/73830)

[20] Pollin Electronic. DCF Empfangsmodul DCF1 [online]. [cit. 2024-04-07]. Do-

stupné z: https://www.pollin.de/p/dcf-empfangsmodul-dcf1-810054.

[21] POUPA, Martin. Vysílání časového signálu a DCF77 [online]. [cit. 2024-

03-26]. Dostupné z: https://vyvoj.hw.cz/teorie-a-praxe/dokumentace/

vysilani-casoveho-signalu-a-dcf77.html. (https://vyvoj.hw.cz/teorie-a-praxe/dokumentace/vysilani-casoveho-signalu-a-dcf77.html)

[22] REGA, B. How the DCF77-receiver works [online]. [cit. 2024-04-08]. Dostupné

z: https://timeserver.eu/dcf77-and-gps-comparison.

ČVUT v Praze | LITERATURA
[23] SHINTON, Andrew. | How Accurate Is Network Time Protocol (NTP)?
[online]. [cit. 2024-05-25]. | Dostupné z: https://timetoolsltd.com/ntp/

ntp-timing-accuracy/. (https://timetoolsltd.com/ntp/ntp-timing-accuracy/)

[24] u-blox. | u-blox 5 Protocol Specifications [online]. [cit. 2024-05-23]. | Do-

stupné z: https://www.sparkfun.com/datasheets/GPS/Modules/u-blox5_

Protocol_Specifications%28GPS.G5-X-07036%29.pdf. (https://www.sparkfun.com/datasheets/GPS/Modules/u-blox5_Protocol_Specifications%28GPS.G5-X-07036%29.pdf)

[25] World Time API. World Time API [online]. [cit. 2024-04-10]. Dostupné z:

https://worldtimeapi.org/.

[26] ZEIS, Zbyněk. Synchronizace času pro odloučená měřící stanoviště [online]. Plzeň, 2016. Bakalářská práce, ZČU. Dostupné z: https://dspace5.zcu.cz/

handle/11025/23073. (https://dspace5.zcu.cz/handle/11025/23073)

ČVUT v Praze | SEZNAM PŘÍLOH

## Seznam příloh

ČVUT v Praze | SEZNAM PŘÍLOH
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

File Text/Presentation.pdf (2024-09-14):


# Vývoj zařízení pro příjem a záznam koordinovaného času pro účely astronomického měření

## Autor: Michal Kovář

Vedoucí: Ing. Zdeněk Vyskočil, Ph.D. Oponent: prof. Ing. Jiří Pospíšil, CSc.

## Předmět práce

Synchronizace a záznam času

## Motivace

Současný postup astronomického měření Chyby v určení času
Vliv chyby v určení času
| Rozdíl azimutů ["] | Rozdíl azimutů [cc UTC [s] ]
1 | 13,93 | 43,01
0,1 | 1,39 | 4,30
0,01 | 0,14 | 0,43

## Cíl práce

Automatická synchronizace času Záznam na MicroSD kartu
Komunikace s totální stanicí Informování měřiče

## Metody příjmu času

Rádiový signál
Internet
GNSS


## Rádiový signál

OMA50, WWVB, MSF, DCF77

## Internet

Application Programming Interface (API) Network Time Protokol (NTP)


## GNSS


## Použité komponenty

Vývojová deska
Deska plošných spojů (DPS) Další

## Schéma zapojení


## Schéma zapojení


## Deska plošných spůjů


## Prototyp zařízení

## Soubory vytvořené na MicroSD kartě


## Závěr

Funkční zařízení pro příjem a záznam koordinovaného času Možnosti vylepšení

## Děkuji za pozornost

## Odpovědi na otázky oponenta

Které součástky nebyly v České republice dostupné?
Jak se bude lišit metoda měření s Astrochronografem oproti metodě zpracované Ing. O. Bottom v GÚ Bratislava v sedmdesátých letech minulého století?
Jak se projeví astronomická refrakce na určení astronomického azimutu Slunce?

## Které součástky nebyly v České republice dostupné?


Přijímač signálu DCF77

### Jak se bude lišit metoda měření s Astrochronografem oproti metodě zpracované Ing. O. Bottom v GÚ Bratislava v sedmdesátých letech minulého století?

Měření vodorovných směrů a času
Měření vodorovných směrů a zenitových úhlů

Měření vodorovných směrů a času


Měření vodorovných směrů a zenitových
úhlů

Pro t0; = 1013,2 hPa [1]

Jak se projeví astronomická refrakce na
určení astronomického azimutu Slunce?

Pouze zenitové úhly
Tečna k zakřivenému paprsku
Úhel, o který se liší skutečná výška hvězdy nad obzorem od
pozorované zdánlivé výšky.

z [°] | 70 | 72 | 74 | 76 | 78 | 80 | 82 | 84 | 86 | 88 | 90
R | 2‘44“ | 3‘03“ | 3‘27“ | 3‘57“ | 4‘37“ | 5‘30“ | 6‘47“ | 8‘46“ | 12‘11“ | 19‘04“ | 36‘30“ 0
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

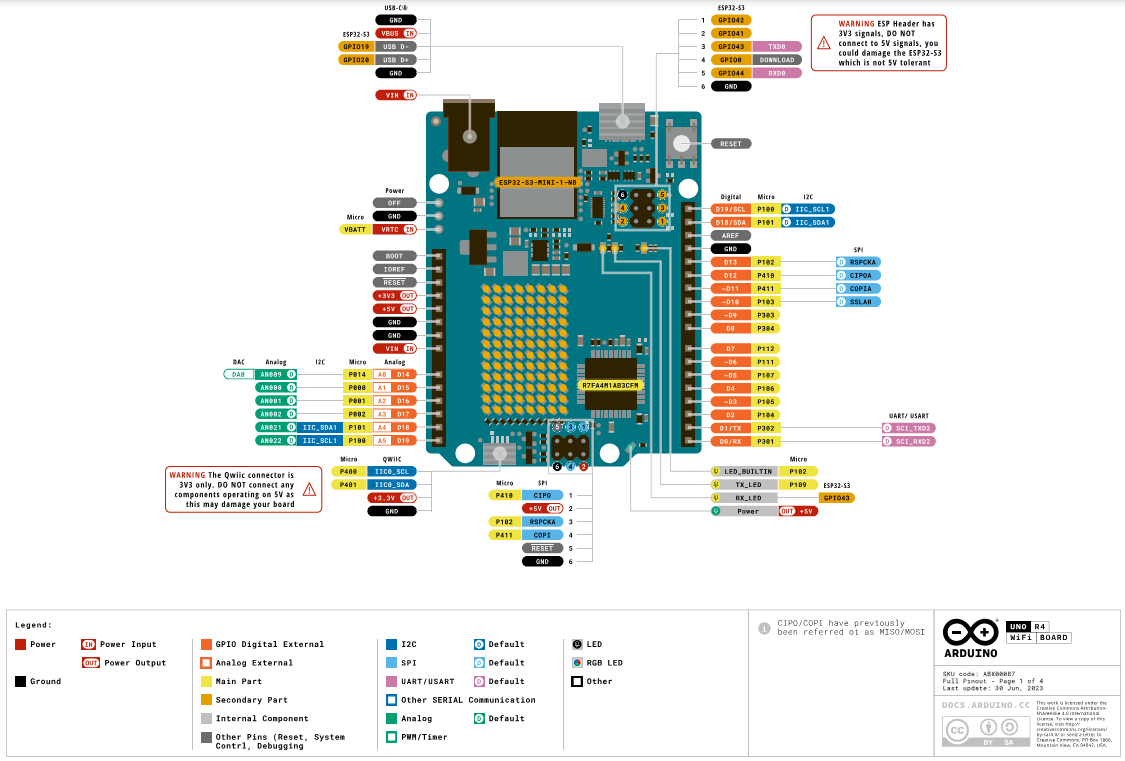
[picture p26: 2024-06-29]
src/LaTex/images/pinout_uno_R4.png

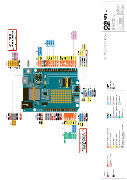
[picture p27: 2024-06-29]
src/LaTex/images/pinout.png

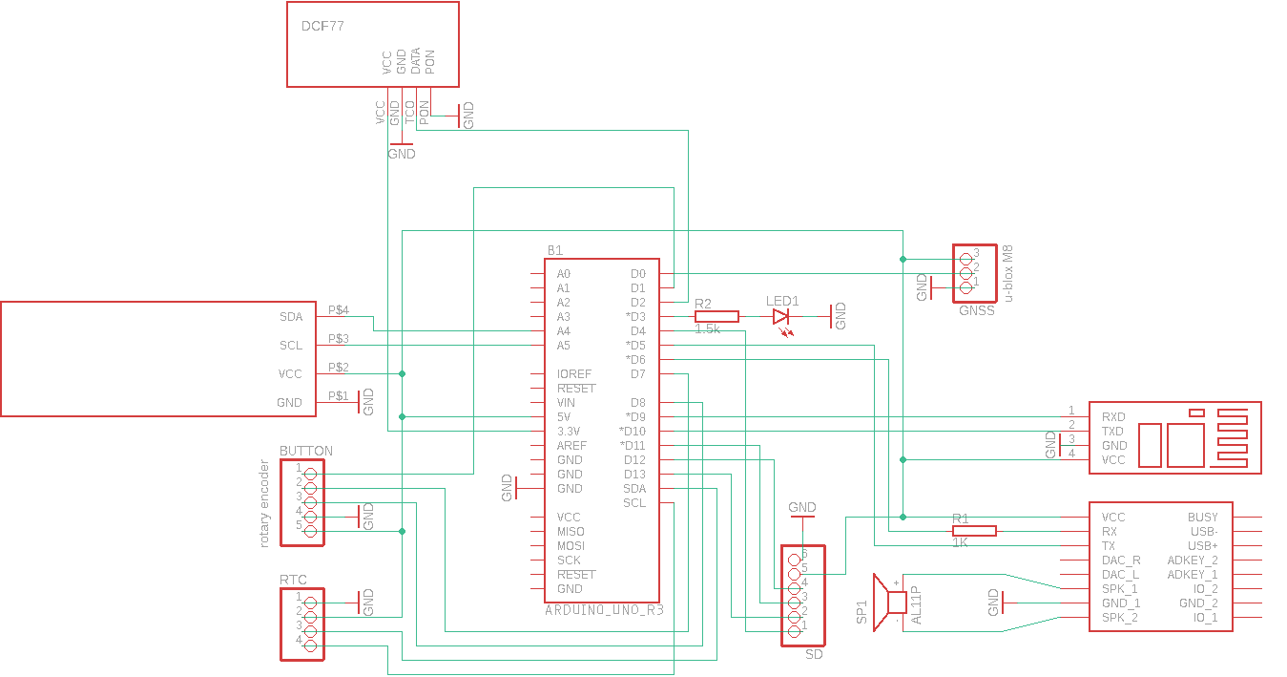
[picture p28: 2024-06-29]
src/LaTex/images/schema_zapojeni_UNO.png

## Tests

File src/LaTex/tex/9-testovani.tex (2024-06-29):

\chapter{Testování}
\label{6-testovani}

\section{Testování během vývoje}
Funkčnost jednotlivých komponentů a byla testována v~průběhu vývoje řídicího programu. Nejprve byla testována funkčnost každého komponentu samostatně. Poté byly komponenty postupně začleňovány do celkového zařízení a byla testována jejich vzájemná spolupráce a funkčnost jako celek.

\section{Testování výsledného zařízení}
Po dokončení prototypu zařízení byla ověřena jeho funkčnost. Protože prototyp je založen na Arduinu UNO R3, má pouze omezenou funkcionalitu. Prototyp umí synchronizovat svůj vnitřní čas buď pomocí DCF77 nebo GNSS přijímače. Tento čas umí po stisknutí tlačítka ukládat na Micro SD kartu. Dále umí informovat měřiče o~průběhu měření prostřednictvím displeje, zvuku a diody. Všechny tyto zmíněné funkce byly otestovány a jsou plně funkční.

\section{Testování DCF77}
U~přijímače signálu DCF77 bylo testováno, jak rychle je schopné výsledné zařízení synchronizovat svůj vnitřní čas a jak často bývá čas synchronizován po první synchronizaci.

\subsubsection{Prvotní synchronizace}
Bylo zjištěno, že prvotní synchronizace bývá za vhodných podmínek provedena mezi druhou až třetí minutou od spuštění. 

\subsubsection{Průběžná synchronizace}
Jak často zařízení synchronizuje svůj vnitřní čas, bylo testováno tím, že bylo \text{zařízení} spuštěno po dobu jednoho dne u~okna orientovaného na západ. Na Micro SD kartě se vytváří soubor \texttt{TEST.TXT}, který obsahuje informace o~tom, kdy došlo k~\text{aktualizaci} času pomocí DCF77. Tato data byla následně zpracována v~softwaru R, kde byl vykreslen histogram znázorňující sloupce pro jednotlivé hodiny, přičemž velikost sloupce značí, kolik synchronizací bylo během této hodiny provedeno.

\begin{figure}[H]
	\centering
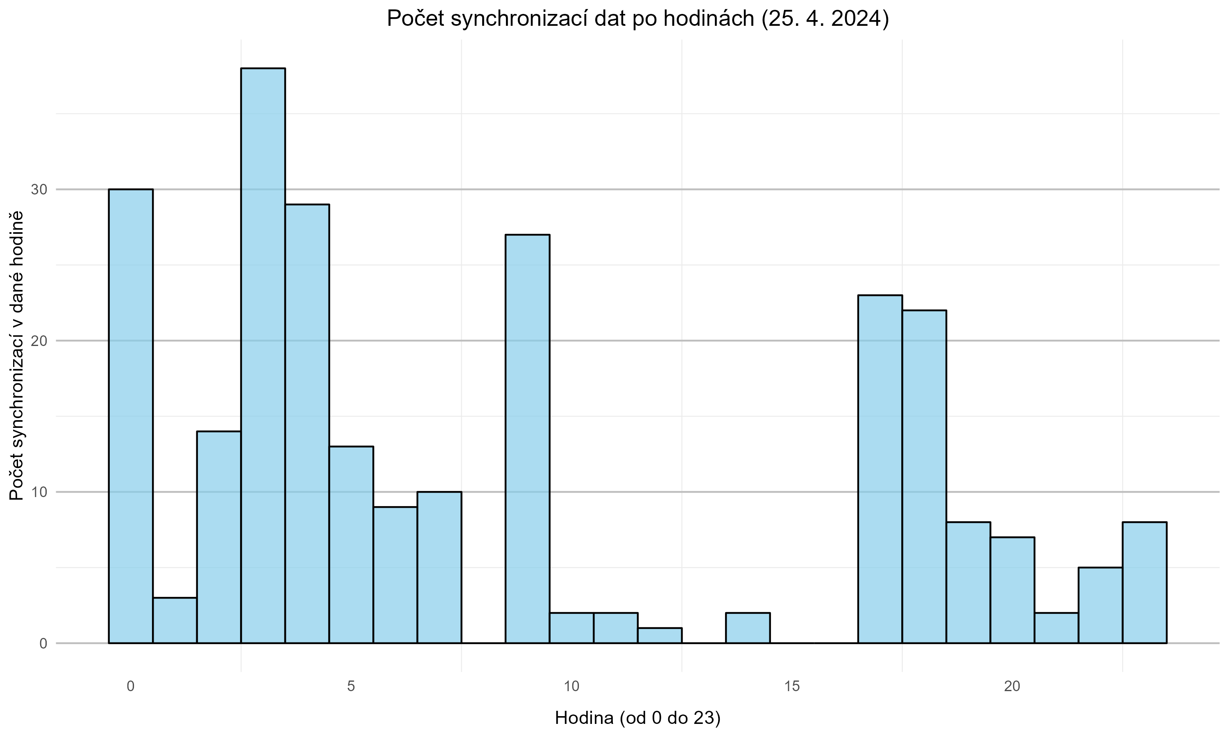
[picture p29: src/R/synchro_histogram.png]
	
	\caption{Histogram počtu synchronizací}
\end{figure}

\section{Testování GNSS modulu}

\subsubsection{Prvotní synchronizace}
Bylo zjištěno, že prvotní synchronizace bývá za vhodných podmínek (v~exteriéru nebo u~okna) provedena během několika sekund.

\subsubsection{Průběžná synchronizace}
Po prvotní synchronizaci získává modul čas nepřetržitě, pokud nedojde k~přerušení příjmu signálu (stínění antény).

\section{Testování NTP serveru}
Čas z~\zk{NTP} serveru bývá získán prakticky okamžitě a pokud nedojde k~přerušení internetového připojení získává zařízení čas nepřetržitě.

\section{Porovnání získaných časů}
Pro porovnání časů získaných z~NTP serveru, přijímače signálu DCF77 a GNSS přijímače byl vytvořen testovací kód pro Arduino UNO R4. Tento kód synchronizuje čas pomocí všech tří zmíněných metod a provádí záznam času každou minutu od spuštění Arduina.

\begin{table}[H]
    \centering
    \caption{Porovnání časů z~různých zdrojů}
    \begin{tabular}{|c|c|c|c|}
    \hline
    Arduino čas & NTP & DCF77 & GNSS \\
    \hline\hline
    00:04:00.00 & 10:27:12.52 & 10:27:12.55 & 10:27:12.68 \\ \hline
    00:05:00.00 & 10:28:12.50 & 10:28:12.55 & 10:28:12.65 \\ \hline
    00:06:00.00 & 10:29:12.49 & 10:29:12.55 & 10:29:12.64 \\ \hline
    00:07:00.00 & 10:30:12.49 & 10:30:12.54 & 10:30:12.69 \\ \hline
    00:08:00.00 & 10:31:12.48 & 10:31:12.54 & 10:31:12.62 \\ \hline
    \end{tabular}\\
\end{table}

Z~měřených dat je vidět, že získané časy se od sebe liší na úrovni setin až \text{desetin} sekundy. Tyto rozdíly mohou být způsobeny tím, že každý zdroj má lehce rozdílnou přesnost. \text{Nejvíce} se liší čas získaný pomocí GNSS přijímače, to může být způsobeno tím, že zpracování NMEA zprávy není dostatečně rychlé a dochází tedy ke zpoždění v~určení času. Pokud se chyba v~určení času pohybuje na úrovni pod jednu \text{desetinu} sekundy, lze očekávat, že chyba výsledného astronomického azimutu Slunce, způsobená určením času, bude mít velikost menší než 5\(^{cc}\).

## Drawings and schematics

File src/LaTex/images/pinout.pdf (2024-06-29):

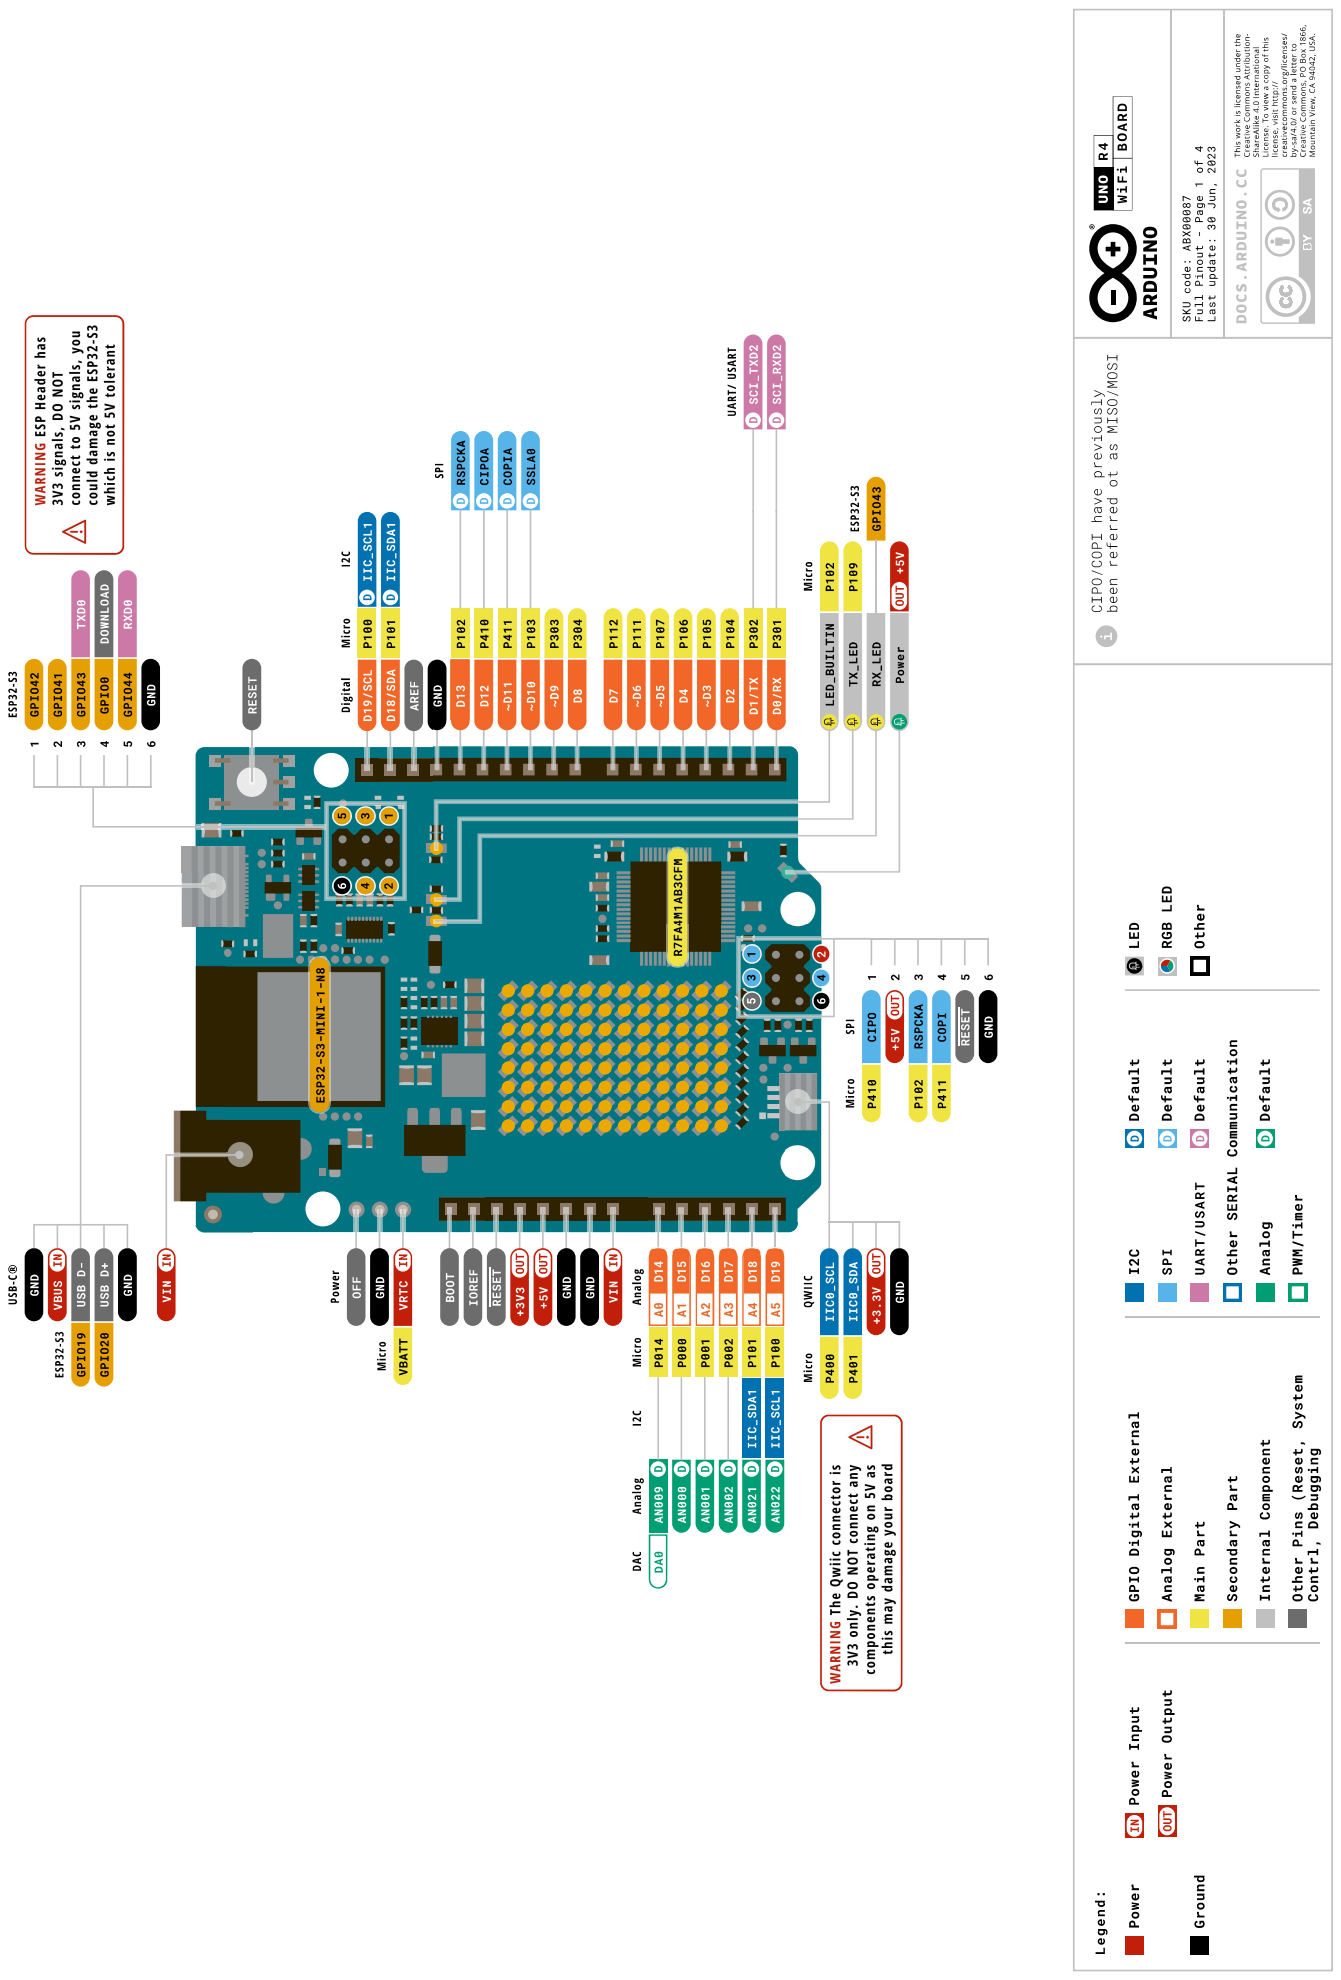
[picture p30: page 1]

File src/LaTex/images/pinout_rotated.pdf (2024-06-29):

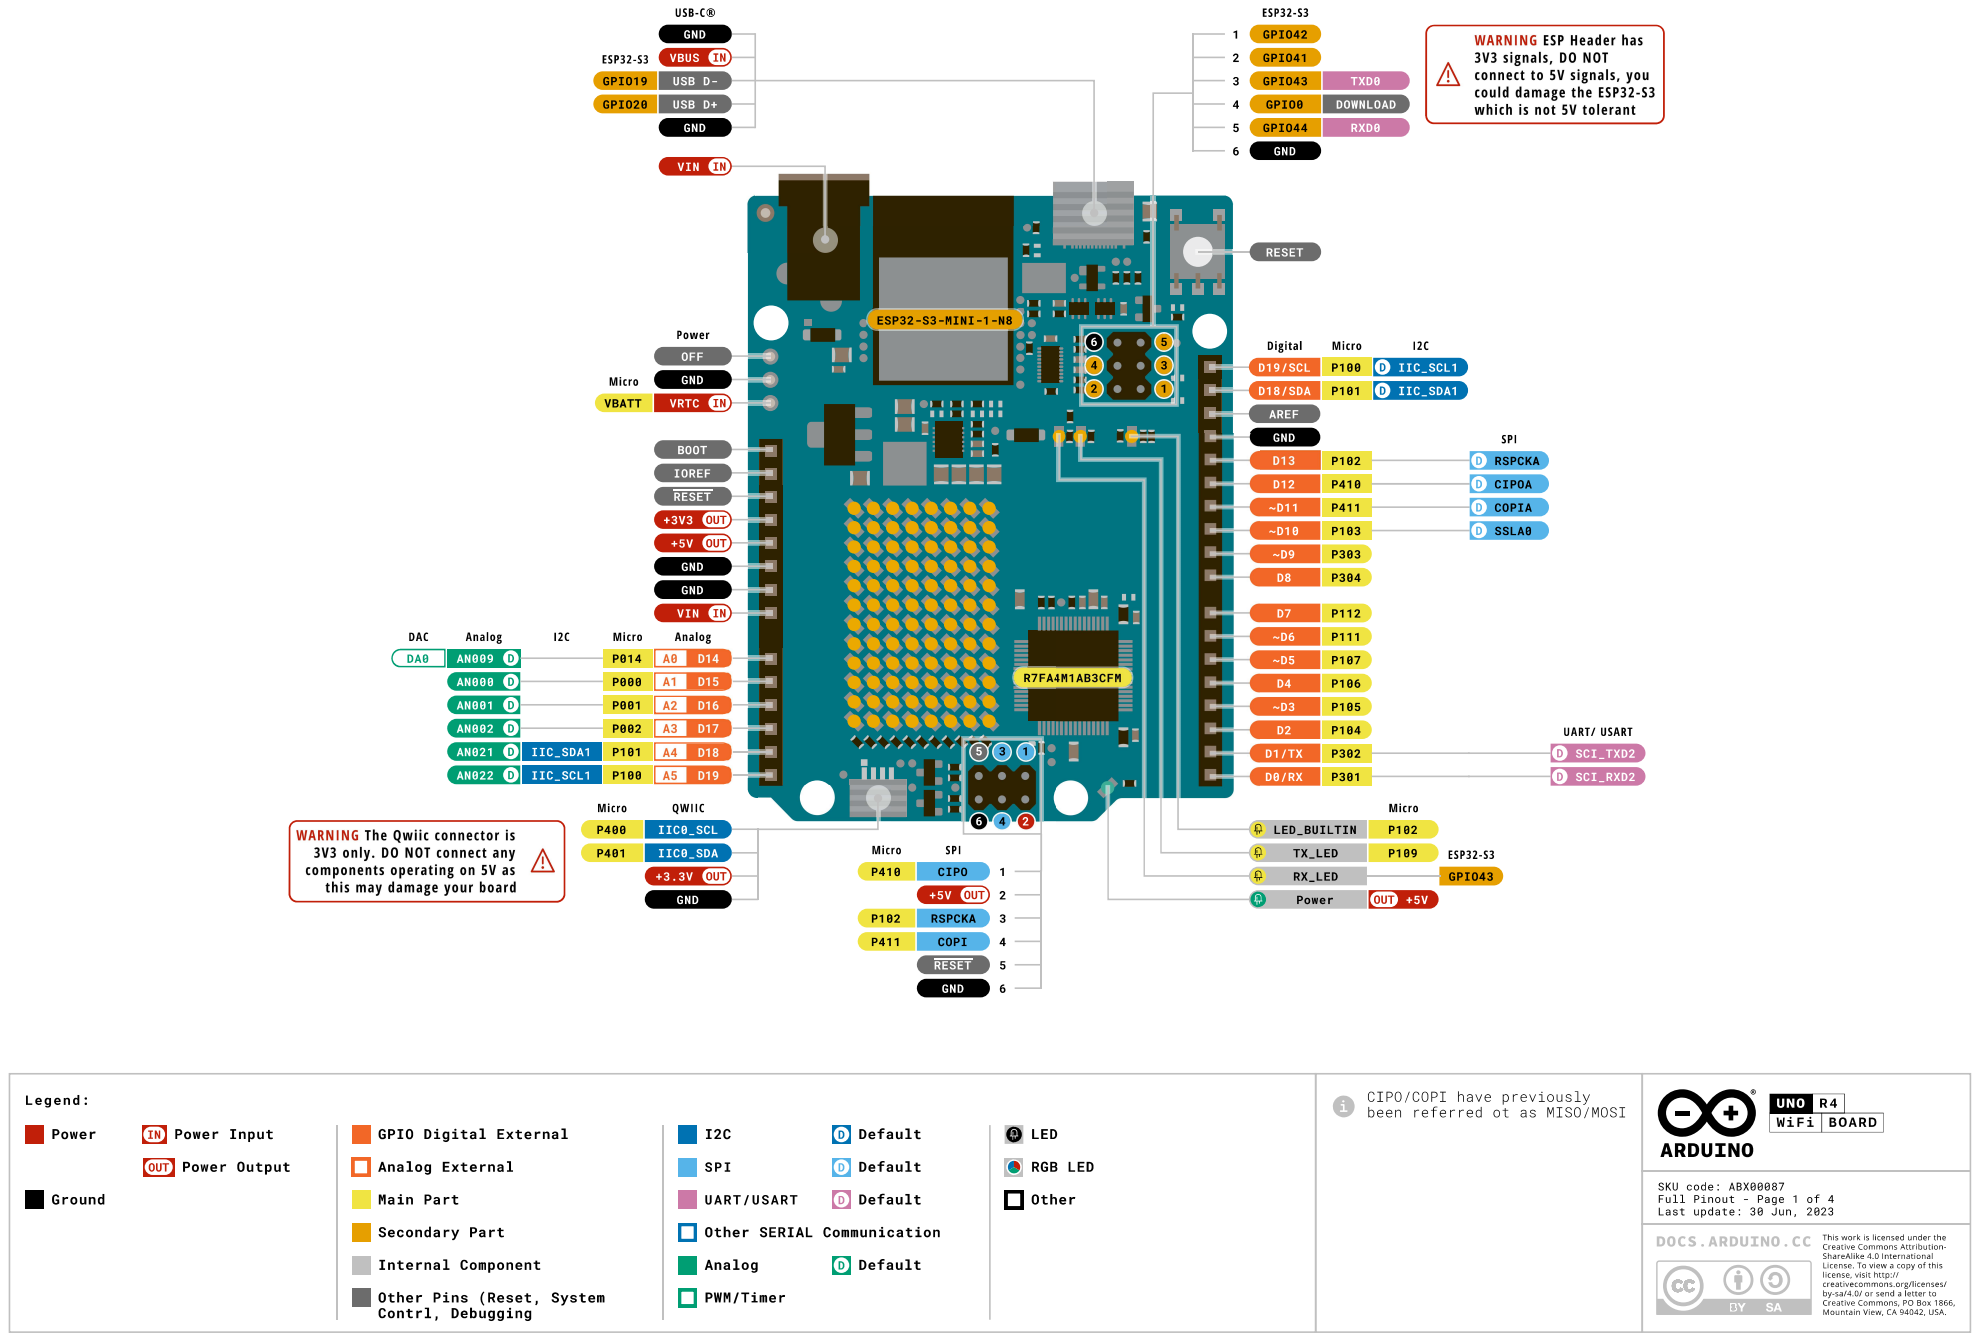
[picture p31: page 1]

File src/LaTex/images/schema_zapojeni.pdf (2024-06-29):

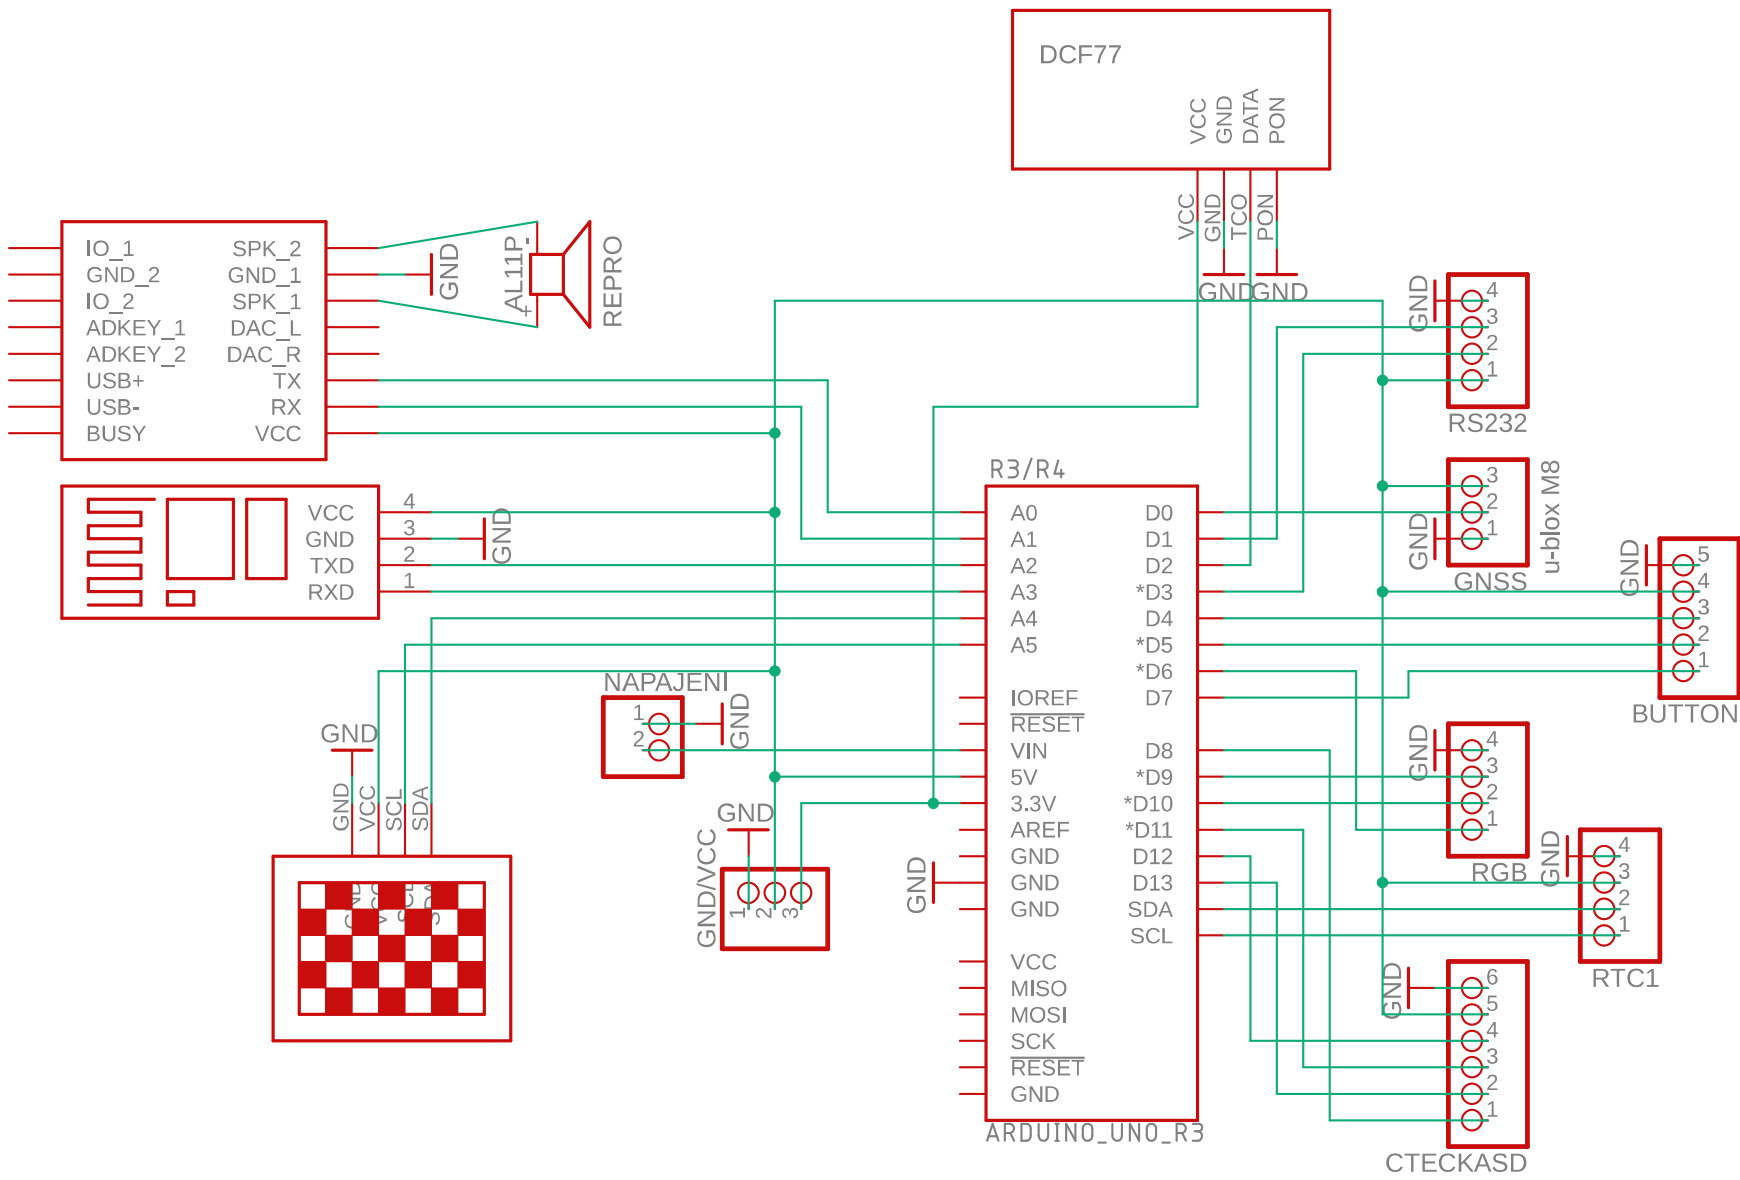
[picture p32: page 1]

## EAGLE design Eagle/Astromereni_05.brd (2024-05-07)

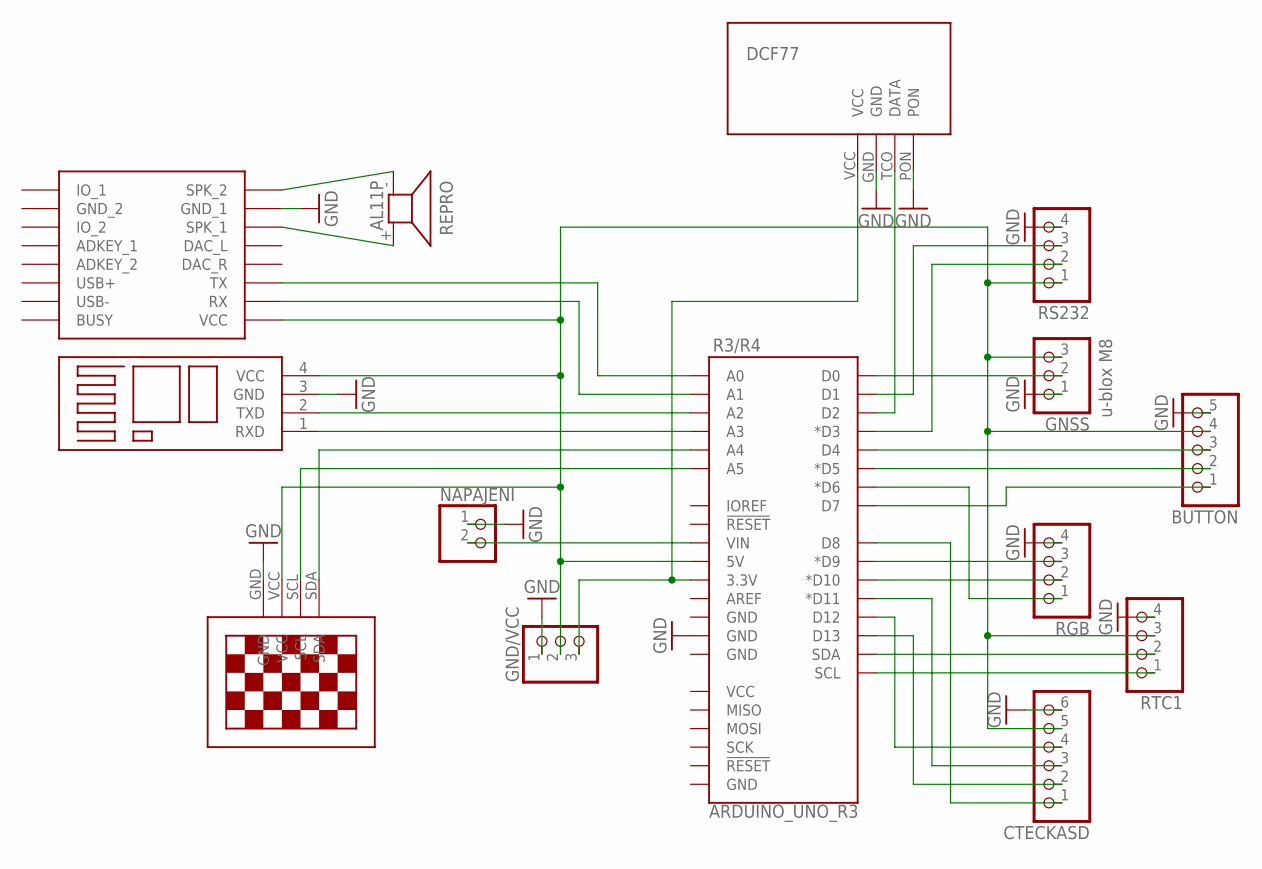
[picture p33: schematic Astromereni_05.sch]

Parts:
B4: BLUETOOTH
BUTTON: PINHD-1X5; 1X05
CTECKASD: PINHD-1X6; 1X06
GND/VCC: PINHD-1X3; 1X03
GNSS: PINHD-1X3; 1X03
NAPAJENI: PINHD-1X2; 1X02
R3/R4: ARDUINO_UNO_R3; ARDUINO_R3
REPRO: AL11P
RGB: PINHD-1X4; 1X04
RS232: PINHD-1X4; 1X04
RTC1: PINHD-1X4; 1X04
U$3: DFPLAYER
U$5: 13"OLED13"OLED; 1.3"OLED
U$6: DCF77

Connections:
GND: B4.3 (GND), BUTTON.5, CTECKASD.6, GND/VCC.1, GNSS.1, NAPAJENI.1, R3/R4.GND@3 (GND), RGB.4, RS232.4, RTC1.4, U$3.GND_1, U$5.GND, U$6.GND, U$6.PON
unnamed: CTECKASD.3, R3/R4.D11 (*D11)
unnamed: R3/R4.D6 (*D6), RGB.1
unnamed: BUTTON.1, R3/R4.D7
unnamed: R3/R4.SDA, RTC1.2
unnamed: R3/R4.SCL, RTC1.1
unnamed: GND/VCC.3, R3/R4.3.3V, U$6.VCC
unnamed: CTECKASD.1, R3/R4.D8
unnamed: CTECKASD.4, R3/R4.D12
unnamed: R3/R4.A5, U$5.SCL
unnamed: R3/R4.A4, U$5.SDA
unnamed: GNSS.2, R3/R4.D0
unnamed: REPRO.+ (2), U$3.SPK1 (SPK_1)
unnamed: REPRO.- (1), U$3.SPK2 (SPK_2)
unnamed: B4.2 (TXD), R3/R4.A2
unnamed: B4.1 (RXD), R3/R4.A3
unnamed: R3/R4.D1, RS232.3
unnamed: NAPAJENI.2, R3/R4.VIN
unnamed: R3/R4.D10 (*D10), RGB.2
unnamed: R3/R4.D9 (*D9), RGB.3
unnamed: R3/R4.A1, U$3.RX
unnamed: R3/R4.A0, U$3.TX
unnamed: B4.4 (VCC), BUTTON.4, CTECKASD.5, GND/VCC.2, GNSS.3, R3/R4.5V, RS232.1, RTC1.3, U$3.VCC, U$5.VCC
unnamed: R3/R4.D2, U$6.TCO (DATA)
unnamed: R3/R4.D3 (*D3), RS232.2
unnamed: CTECKASD.2, R3/R4.D13
unnamed: BUTTON.2, R3/R4.D5 (*D5)
unnamed: BUTTON.3, R3/R4.D4

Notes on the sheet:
u-blox M8

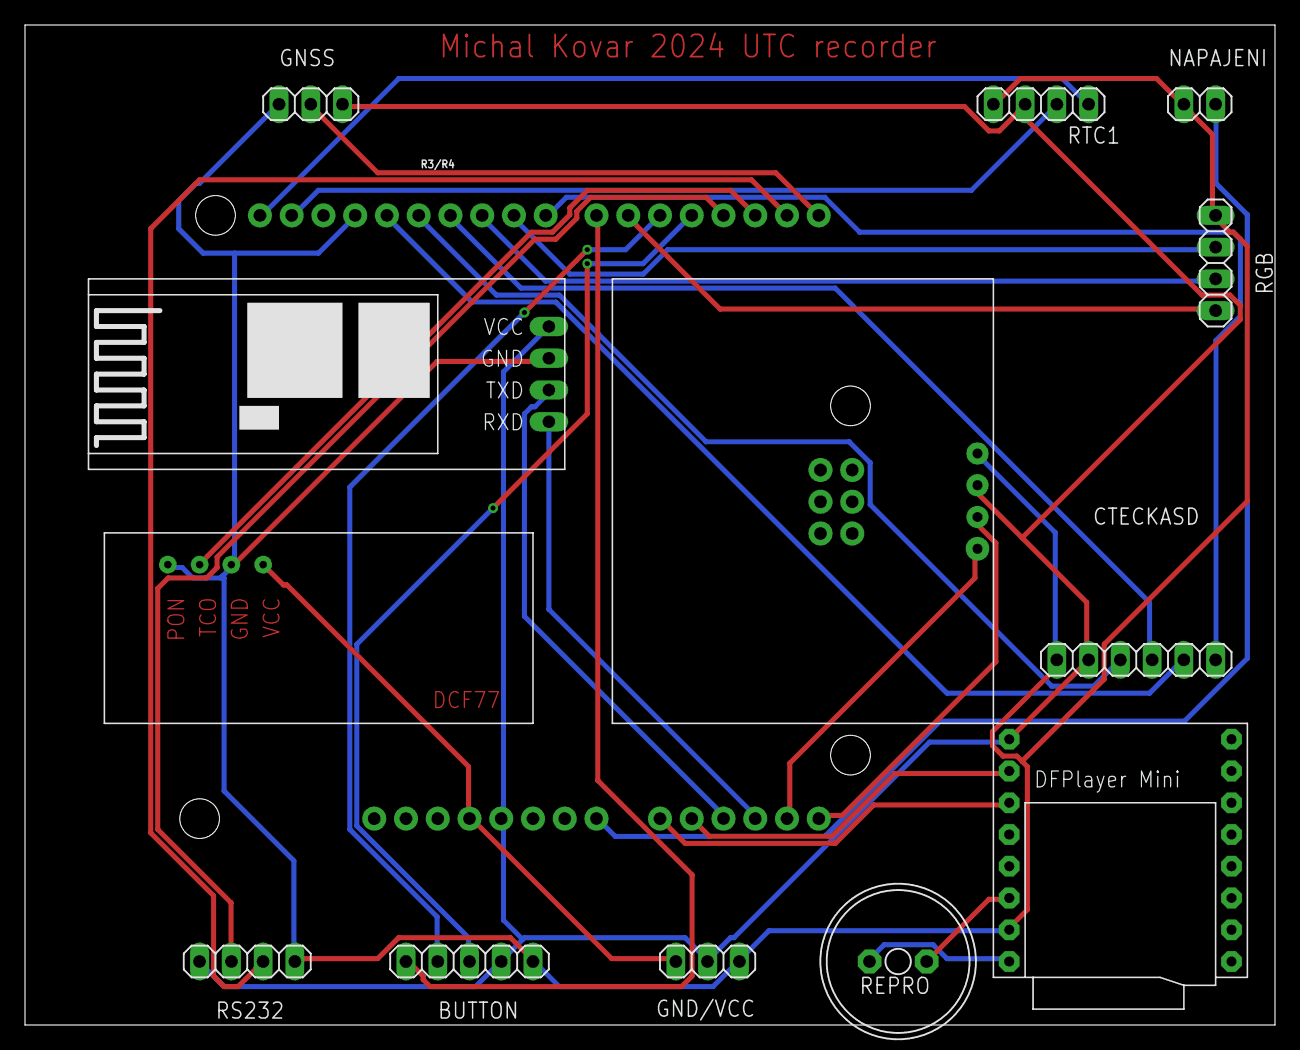
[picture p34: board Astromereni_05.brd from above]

Board: 2 copper layers, 100.0 x 80.0 mm, 14 parts (0 on the bottom side), 28 nets.

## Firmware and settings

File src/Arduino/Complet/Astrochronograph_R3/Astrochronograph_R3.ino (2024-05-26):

/* This code initializes the internal time of the Arduino with the time obtained from DCF77, connects the SD card, 
 * and upon pressing a button, creates a file "Zaznam.txt" on it, in which it saves the current time obtained from DCF77
 * in the format HH:MM:SS.SS DD MM YYYY (00:00:00.00 01 01 1970) and the time since the Arduino started in the format 
 * HHH:MM:SS.SS (000:00:00.00). This code also displays the current time, the last recorded time, the status of the SD card 
 * (SD:... / SD: OK), and the status of the time initialization from DCF77 (DCF:... / DCF: OK) on the display.
 *
 * THIS CODE WAS CREATED FOR ARDUINO UNO!!!
 *
 * Wiring:
 *
 * SD card slot:
 * MOSI - pin 11
 * MISO - pin 12
 * SCK  - pin 13
 * CS   - pin 4
 * Button (rotary encoder):
 * SW   - pin 8
 * Display:
 * SCK  - pin A5
 * SDA  - pin A4
 * DCF77 receiver:
 * TCO  - pin 2
 *
 * Description of the DCF77 receiver: https://www.pollin.de/p/dcf-77-empfangsmodul-dcf1-810054
 * Description of the display: https://dratek.cz/arduino/1479-iic-i2c-displej-oled-0.91-128x32-bily-3-3-v-5v-pro-iot-arduino-raspbery.html
 * Description of the SD card: https://www.laskakit.cz/microsd-card-modul-spi/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
 * https://github.com/arduino-libraries/SD/tree/master/examples
 * Description of the button (rotary encoder): https://dratek.cz/arduino/837-rotacni-enkoder.html
 */

/* CURRENT PROBLEMS!!!
 * When the SD card is disconnected, the display output is not smooth.
 * If the time is updated while the SD card is disconnected, the whole program freezes.
 * 90% memory usage on Arduino Uno is quite a lot... needs optimization.
 * Functions that are called only once in the code should be converted to inline functions to save space.
 * The code could use some more organization.
 */

// Define pins
#define DCF_PIN 2 // Connection pin to DCF 77 device
#define DCF_INTERRUPT 0 // Interrupt number associated with pin
#define BUTTON_PIN 8 // Define the pin for the button SW
#define KARTA_CS_PIN 4 // Define the pin for the SD card CS

// Libraries
#include "Arduino.h" // C++ library for Wiring functionality
#include "SoftwareSerial.h"
#include "DFRobotDFPlayerMini.h"
#include <DCF77.h> // Library for connecting to DCF 77
#include <TimeLib.h> // Library for working with time
#include <SD.h> // Library for working with SD card
#include <U8glib.h> // Library for working with OLED display

// Variables for DCF 77
unsigned long lastTime = 0;
char milliString[4] = ".00";
char timeString[9] = "00:00:00";
char dateString[12] = "00 00 1970";
char previousTimeString[9] = "00:00:00";

// Create a SoftwareSerial instance for communication with the DFPlayer module
SoftwareSerial mySoftwareSerial(5, 6); // RX, TX

// Create a DFRobotDFPlayerMini instance
DFRobotDFPlayerMini myDFPlayer;

time_t time;
DCF77 DCF = DCF77(DCF_PIN, DCF_INTERRUPT);

// Variables for OLED display
U8GLIB_SSD1306_128X64 mujOled(U8G_I2C_OPT_NONE); // Object for OLED display
char timeStr[12] = "00:00:00.00"; // Variable for storing time in format HH:MM:SS:SS
char sd_string[4] = "..."; // Variable for storing SD card status
char cas_string[4] = "..."; // Variable for storing DCF77 signal status

File myFile; // Object for working with files on the SD card

bool tlacitko_stisknuto = false; // Button status

char cas_od_spusteni[13] = "000:00:00.00"; // Predefined string with time since start
char posledni_ulozeny_cas[12] = "           ";

void setup() {
  // Initialization of the SoftwareSerial communication
  PlaySoundSetup();
  DCF.Start();
  pinMode(KARTA_CS_PIN, INPUT_PULLUP);
  pinMode(BUTTON_PIN, INPUT_PULLUP);
}

void loop() {
  kartaLoop();
  dcfCas();
  tvorbaStringu();
  setiny();
  zobrazitNaDisplay(timeStr, sd_string, cas_string, posledni_ulozeny_cas);
  zmacknutitlacitka();
}

void kartaLoop() {
  // Function to check the status of the SD card
  if (!SD.begin(KARTA_CS_PIN)) {
    strcpy(sd_string, "...");
  } else {
    strcpy(sd_string, " OK");
  }
}

void zobrazitNaDisplay(const char* cas, const char* sd, const char* dcf, const char* zmereny_cas) {
  /* Used fonts:
   * Fonts can be changed according to: https://github.com/olikraus/u8glib/wiki/fontsize
   * Adobe X11 Font
   * u8g_font_courB14
   * u8g_font_courR08
   */
  mujOled.firstPage();
  do {
    mujOled.setFont(u8g_font_courB14);
    mujOled.drawStr(0, 32, cas);
    mujOled.setFont(u8g_font_courR08);
    mujOled.drawStr(0, 52, zmereny_cas);
    mujOled.setFont(u8g_font_courR08);
    mujOled.drawStr(92, 44, "SD:");
    mujOled.drawStr(110, 44, sd);
    mujOled.drawStr(86, 52, "DCF:");
    mujOled.drawStr(110, 52, dcf);
  } while (mujOled.nextPage());
}

void zmacknutitlacitka() {
  // Function to detect button press and execute commands after pressing it
  if (digitalRead(BUTTON_PIN) == LOW) {
    if (!tlacitko_stisknuto) {
      tlacitko_stisknuto = true;
      PlaySound(2, 30); // Call the PlaySound function with argument 
      casOdSpusteni(); // Update cas_od_spusteni
      myFile = SD.open("ZAZNAM.txt", FILE_WRITE);
      if (myFile) {
        // Commands executed after pressing the button
        myFile.print(timeStr); // Save to ZAZNAM.txt time obtained from DCF77 in format (HH:MM:SS.SS)
        myFile.print(" "); // Add space
        myFile.print(dateString); // Save date in format (DD MM YYYY)
        myFile.print("  "); // Add two spaces
        myFile.println(cas_od_spusteni);
        myFile.close();
        strcpy(posledni_ulozeny_cas, timeStr); // Assign the value of one array to another array
        // End of commands executed after pressing the button
      } else {
        while (1);
      }
    }
  } else {
    tlacitko_stisknuto = false; // Ensures that one button press is considered only as one press
  }
}

void casOdSpusteni() {
  // Function that saves the time since start to the variable "cas_od_spusteni"
  // It is called in the function "void zmacknutitlacitka()"
  unsigned long cas = millis();
  // Splitting the time since start into hours, minutes, seconds, and hundredths
  unsigned int hodiny = cas / 3600000;
  unsigned int minuty = (cas / 60000) % 60;
  unsigned int sekundy = (cas / 1000) % 60;
  unsigned int setiny_sekundy = (cas / 10) % 100;
  // Formatting and saving the time since start to "cas_od_spusteni"
  sprintf(cas_od_spusteni, "%03d:%02d:%02d.%02d", hodiny, minuty, sekundy, setiny_sekundy);
}

void tvorbaStringu() {
  // Function to create strings with time and date obtained from DCF77
  sprintf(timeString, "%02d:%02d:%02d", hour(), minute(), second());
  sprintf(dateString, "%02d %02d %04d", day(), month(), year());
}

void dcfCas() {
  // Function to update the internal time of the Arduino with DCF77
  time_t DCFtime = DCF.getTime();
  if (DCFtime != 0) {
    setTime(DCFtime);
    sprintf(cas_string, " OK");
    tvorbaStringu();
    PlaySound(1, 30); // Call the PlaySound function with argument 
    myFile = SD.open("TEST.txt", FILE_WRITE); // Open file to write to
    if (myFile) {
      myFile.print("Time last updated: "); // Write to file TEST.txt
      myFile.print(timeString); // Save to Cas_aktualizace.txt time obtained from DCF77 in format (HH:MM:SS.SS)
      myFile.print(" ");
      myFile.println(dateString);
      myFile.close(); // Close file
    } else {
      while (1);
    }
  }
}

void setiny() {
  // Function to create hundredths of seconds
  if (strcmp(timeString, previousTimeString) != 0) { // Compare time strings
    lastTime = millis();
    strcpy(previousTimeString, timeString); // Assign new time string to the previous time string
  }
  float elapsedTime = (float)(millis() - lastTime) / 1000; // Calculate the time since the strings differed
  snprintf(milliString, 5, "%02d", (int)(elapsedTime * 100) % 100); // Create a string with hundredths of seconds
  sprintf(timeStr, "%s.%s", timeString, milliString); // Join the time string and the string with hundredths of seconds
}

// Function to play a sound
void PlaySound(int nazev, int volume) {
  myDFPlayer.volume(volume); // Set the volume 0 - 30 
  myDFPlayer.play(nazev); // Play the mp3 file in the order corresponding to the order variable
  // The sound was created using: https://ttsmaker.com/cs#google_vignette
}

void PlaySoundSetup() {
  mySoftwareSerial.begin(9600);
  if (!myDFPlayer.begin(mySoftwareSerial)) {
    while (true);
  }
}

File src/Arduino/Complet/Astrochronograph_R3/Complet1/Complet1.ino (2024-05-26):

/* Tento kÃ³d inicializuje vnitÅnÃ­ Äas arduina s Äasem zÃ­skanÃ½m z DCF77, pÅipojuje SD kartu a po zmÃ¡ÄknutÃ­ tlaÄÃ­tka na nÃ­ vytvÃ¡ÅÃ­ soubor Zaznam.txt do nÄjÅ¾ uklÃ¡dÃ¡ aktuÃ¡lnÃ­ Äas zÃ­skanÃ½ z DCF77 
 * ve formÃ¡tu HH:MM:SS.SS DD MM rok (00:00:00.00 01 01 1970) a Äas od spuÅ¡tÄnÃ­ arduina ve formÃ¡tu HHH:MM:SS.SS (000:00:00.00). Tento kod dÃ¡le zobrazuje na displej aktuÃ¡lnÃ­ Äas, poslednÃ­ zaznamenanÃ½ Äas, 
 * stav SD karty (SD:... / SD: OK) a stav inicializace Äasu z DCF77(DCF:... / DCF: OK)
 * 
 * TENTO KÃD BYL VYTVOÅEN PRO ARDUINO UNO!!!
 * 
 * kam co zapojit?
 * 
 * slot pro SD kartu:
 * MOSI - pin 11
 * MISO - pin 12
 * SCK  - pin 13
 * CS   - pin  4
 * tlaÄÃ­tko(rotaÄnÃ­ enkÃ³der):
 * SW   - pin  8
 * displej:
 * SCK  - pin A5
 * SDA  - pin A4
 * DCF77 pÅijÃ­maÄ:
 * TCO  - pin  2
 *
 *
 * popis DCF77 pÅijÃ­maÄe: https://www.pollin.de/p/dcf-77-empfangsmodul-dcf1-810054
 * popis displeje: https://dratek.cz/arduino/1479-iic-i2c-displej-oled-0.91-128x32-bily-3-3-v-5v-pro-iot-arduino-raspbery.html
 * popis SD karta: https://www.laskakit.cz/microsd-card-modul-spi/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
 * https://github.com/arduino-libraries/SD/tree/master/examples
 * popis tlaÄÃ­tko (rotaÄnÃ­ enkoder): https://dratek.cz/arduino/837-rotacni-enkoder.html
 *
 */
 
/* SOUÄASNÃ PROBLÃMY!!!
 * pÅi odpojenÃ­ SD karty nenÃ­ plynulÃ½ vÃ½pis na displej
 * ?pokud je Äas aktualizovÃ¡n v pÅÃ­padÄ Å¾e je odpojena SD karta tak se celÃ½ program zasekne
 * 90% na arduinu uno je celkem dost pamÄti... potÅeba optimalizace
 * funkce kterÃ© jsou volÃ¡ny v kodu jen jednou by bylo vhodnÃ© pÅedÄlat na inline funkce aby zabÃ­rali mÃ©nÄ mÃ­sta
 * kod by chtÄl jeÅ¡tÄ trochu zpÅehlednit
 */


// nedefinovÃ¡nÃ­ pinÅ¯
#define DCF_PIN 2 // Connection pin to DCF 77 device
#define DCF_INTERRUPT 0 // Interrupt number associated with pin
#define BUTTON_PIN 8 //definuje na kterÃ©m je sw u tlaÄÃ­tka
#define KARTA_CS_PIN 4 //definuje na kterÃ©m pinu je cs u SD krty

// knihovny
#include "Arduino.h" // C++ library for Wiring functionality
#include "SoftwareSerial.h"
#include "DFRobotDFPlayerMini.h"
#include <DCF77.h> // Knihovna pro pÅipojenÃ­ k DCF 77
#include <TimeLib.h>// Knihovna pro prÃ¡ci s Äasem
#include <SD.h> // Knihovna pro prÃ¡ci s SD kartou
#include <U8glib.h> // Knihovna pro prÃ¡ci s OLED displejem

// PromÄnnÃ© pro DCF 77
unsigned long lastTime = 0;
char milliString[4] = ".00";
char timeString[9] = "00:00:00";
char dateString[12] = "00 00 1970";
char previousTimeString[9] = "00:00:00";

// Create a SoftwareSerial instance for communication with the DFPlayer module
SoftwareSerial mySoftwareSerial(5, 6); // RX, TX

// Create a DFRobotDFPlayerMini instance
DFRobotDFPlayerMini myDFPlayer;

time_t time;
DCF77 DCF = DCF77(DCF_PIN,DCF_INTERRUPT);

// PromÄnnÃ© pro OLED displej
U8GLIB_SSD1306_128X32 mujOled(U8G_I2C_OPT_NONE); // Objekt pro OLED displej
char timeStr[12] = "00:00:00.00"; //promÄnnÃ¡ pro uklÃ¡dÃ¡nÃ­ Äasu ve formÃ¡tu HH:MM:SS:SS
char sd_string[4] = "..."; //promÄnnÃ¡ pro uklÃ¡dÃ¡nÃ­ stavu SD karty
char cas_string[4] = "..."; //promÄnnÃ¡ pro uklÃ¡dÃ¡nÃ­ stavu signÃ¡lu DCF77

File myFile; //objekt pro prÃ¡ci se souborem na SD kartÄ

bool tlacitko_stisknuto = false; //stav tlaÄÃ­tka

char cas_od_spusteni[13]= "000:00:00.00"; //pÅeddefinovÃ¡nÃ­ stringu s Äasem od spuÅ¡tÄnÃ­
char posledni_ulozeny_cas[12] ="           ";

void setup() {
  // Initialization of the SoftwareSerial communication
  PlaySoundSetup();
  DCF.Start();
  pinMode(KARTA_CS_PIN, INPUT_PULLUP);
  pinMode(BUTTON_PIN, INPUT_PULLUP);
}

void loop() {
  kartaLoop();
  dcfCas();
  tvorbaStringu();
  setiny();
  zobrazitNaDisplay(timeStr, sd_string, cas_string, posledni_ulozeny_cas);
  zmacknutitlacitka();
}

void kartaLoop() {
  // funkce pro kontrolu stavu SD karty
  if (!SD.begin(KARTA_CS_PIN)) {
    strcpy(sd_string, "...");
  } 
  else {
    strcpy(sd_string, " OK");
  }
}


void zobrazitNaDisplay(const char* cas, const char* sd, const char* dcf,const char* zmereny_cas) {
/* PouÅ¾itÃ© fonty:
 * fonty lze mÄnit podle: https://github.com/olikraus/u8glib/wiki/fontsize
 * Adobe X11 Font
 * u8g_font_courB14
 * u8g_font_courR08
 */
  mujOled.firstPage();
  do {
    mujOled.setFont(u8g_font_courB14);
    mujOled.drawStr(0, 12, cas);
    mujOled.setFont(u8g_font_courR08);
    mujOled.drawStr(0, 32, zmereny_cas);
    mujOled.setFont(u8g_font_courR08);
    mujOled.drawStr(92, 24, "SD:");
    mujOled.drawStr(110, 24, sd);
    mujOled.drawStr(86, 32, "DCF:");
    mujOled.drawStr(110, 32, dcf);
  } while ( mujOled.nextPage() );
}

void zmacknutitlacitka(){
  // funkce pro rozpoznÃ¡nÃ­ zmÃ¡ÄknutÃ­ tlaÄÃ­tka a vykonÃ¡nÃ­ pÅÃ­kazÅ¯ po jeho zmÃ¡ÄknutÃ­
  if (digitalRead(BUTTON_PIN) == LOW) {
    if (!tlacitko_stisknuto) {
      tlacitko_stisknuto = true;
      PlaySound(2,30); // Call the PlaySound function with argument 
      casOdSpusteni(); // aktualizace cas_od_spusteni
      myFile = SD.open("ZAZNAM.txt", FILE_WRITE);
      if (myFile) {
        // pÅÃ­kazy vkonanÃ© po zmÃ¡ÄknutÃ­ tlaÄÃ­tka
        myFile.print(timeStr); // uklÃ¡dÃ¡d do ZAZANAM.txt Äas zÃ­skanÃ½ z DCF77 ve formÃ¡tu (HH:MM:SS.SS)
        myFile.print(" "); // pÅidÃ¡ mezeru
        myFile.print(dateString); // uklÃ¡dÃ¡ datum ve formÃ¡tu (DD MM rok)
        myFile.print("  "); // pÅidÃ¡ dvÄ mezery
        myFile.println(cas_od_spusteni);
        myFile.close();
        strcpy(posledni_ulozeny_cas, timeStr);//pÅiÅazenÃ­ hodnoty jednoho pole do druhÃ©ho pole
        // konec pÅÃ­kazÅ¯ vykonanÃ½ch po zmÃ¡ÄknutÃ­ tlaÄÃ­tka
        } else {
        while (1);
      }
    }
  } else {
    tlacitko_stisknuto = false; // zajiÅ¡Å¥uje aby jedno zmÃ¡ÄknutÃ­ tlaÄÃ­tka bylo brÃ¡no pouze jako jedno zmÃ¡ÄknutÃ­
  }
}

void casOdSpusteni() {
  // funkce kterÃ¡ uklÃ¡dÃ¡ Äas od spuÅ¡tÄnÃ­ do promÄnÃ© "cas_od_spusteni"
  // je volÃ¡na ve funkci "void zmacknutitlacitka()"
  unsigned long cas = millis();
  // rozdÄlenÃ­ Äasu od spuÄtÅ¡nÃ­ do hodin, minut, sekund a setin
  unsigned int hodiny = cas / 3600000;
  unsigned int minuty = (cas / 60000) % 60;
  unsigned int sekundy = (cas / 1000) % 60;
  unsigned int setiny_sekundy = (cas / 10) % 100;
  // naformÃ¡tÃ³vÃ¡nÃ­ a uloÅ¾enÃ­ Äasu od spuÅ¡tÄnÃ­ do "cas_od_spusteni"
  sprintf(cas_od_spusteni, "%03d:%02d:%02d.%02d", hodiny, minuty, sekundy, setiny_sekundy);
}


void tvorbaStringu(){
  // funkce pro tvorbu stringÅ¯ s Äasem a datumem zÃ­skanÃ½mi z DCF77
  sprintf(timeString, "%02d:%02d:%02d", hour(), minute(), second());
  sprintf(dateString, "%02d %02d %04d", day(), month(), year());
}
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

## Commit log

2024-03-08 Přidána cesta ke knihovně Arduino
2024-05-07 přidány soubory Eagle
    [Astromereni_05.brd, Astromereni_05.sch]
2024-05-26 Utřídění souborů
    [casy.csv, synchro.csv]

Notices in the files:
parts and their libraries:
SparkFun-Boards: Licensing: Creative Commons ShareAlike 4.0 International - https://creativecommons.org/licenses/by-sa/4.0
